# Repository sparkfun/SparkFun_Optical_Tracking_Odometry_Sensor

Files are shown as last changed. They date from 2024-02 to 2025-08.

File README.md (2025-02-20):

SparkFun Optical Tracking Odometry Sensor
========================================

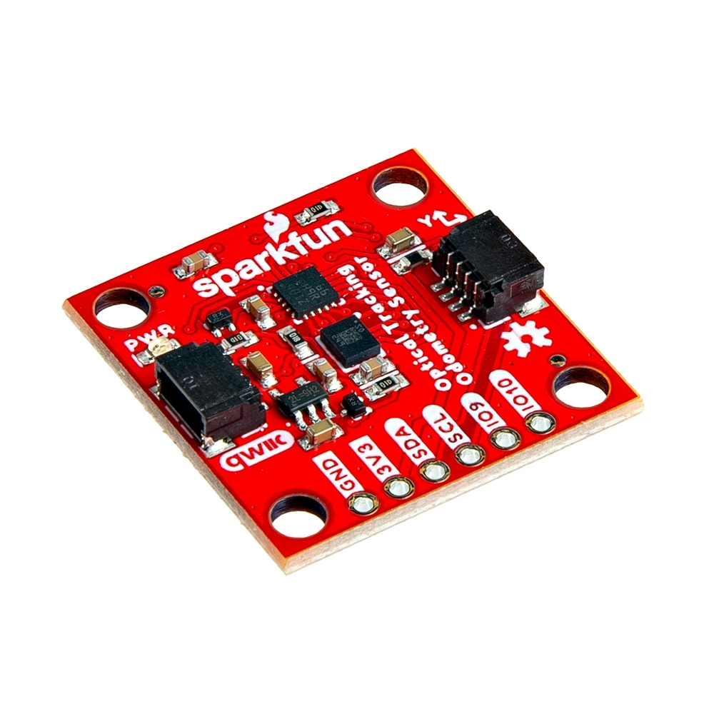
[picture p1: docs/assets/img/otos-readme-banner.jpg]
SparkFun Optical Tracking Odometry Sensor [SEN-24904]


[*SparkFun Optical Tracking Odometry Sensor [SEN-24904]*](https://www.sparkfun.com/products/24904)

The SparkFun Qwiic Optical Tracking Odometry Sensor empowers you to elevate your robot's navigation capabilities with exceptional precision and streamlined integration. This compact, all-in-one sensor leverages the power of the PAA5160E1 chip from PixArt Imaging Inc., delivering accurate dual-axis motion data across various hard floor surfaces. But that's not all! This sensor boasts a powerful built-in 6-axis Inertial Measurement Unit (IMU) and an onboard microcontroller that performs real-time sensor fusion and tracking algorithms.

Repository Contents
-------------------

* **/Hardware** - Eagle design files (.brd, .sch)
* **/Production** - Production panel files (.brd)

Documentation
--------------
* **[Arduino Library](https://github.com/sparkfun/SparkFun_Qwiic_OTOS_Arduino_Library)** - Arduino library for the SparkFun Optical Tracking Odometry Sensor.
* **[Hookup Guide](https://docs.sparkfun.com/SparkFun_Optical_Tracking_Odometry_Sensor/)** - Hookup guide for the SparkFun Optical Tracking Odometry Sensor.

License Information
-------------------

This product is _**open source**_! 

Please review the LICENSE.md file for license information. 

If you have any questions or concerns on licensing, please contact technical support on our [SparkFun forums](https://forum.sparkfun.com/viewforum.php?f=152).

Distributed as-is; no warranty is given.

- Your friends at SparkFun.

_<COLLABORATION CREDIT>_

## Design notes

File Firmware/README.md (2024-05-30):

# SparkFun OTOS (Optical Tracking Odometry Sensor) Firmware

This folder contains the firmware used on the [SparkFun Optical Tracking Odometry Sensor](https://www.sparkfun.com/products/24904). Instructions are provided below for anyone wanting to change the firmware on their OTOS.

## Firmware Update

The recommended update procedure is to use the [STM32CubeProgrammer](https://www.st.com/en/development-tools/stm32cubeprog.html) to flash the provided .hex firmware file using the UART interface. The SWD test points on the OTOS can also be used with a debugger, but instructions are not provided here.

### Required Materials

* A [SparkFun Optical Tracking Odometry Sensor](https://www.sparkfun.com/products/24904) to be updated
* A USB to serial adapter, such as the [SparkFun Serial Basic Breakout](https://www.sparkfun.com/products/15096)
* [Jumper wires](https://www.sparkfun.com/products/12795) to connect the serial adapter to the OTOS
* Download the [STM32CubeProgrammer](https://www.st.com/en/development-tools/stm32cubeprog.html) and install it onto your computer
* Download the latest .hex file [from the releases tab](https://github.com/sparkfun/SparkFun_Optical_Tracking_Odometry_Sensor/releases) or [from the main branch](https://github.com/sparkfun/SparkFun_Optical_Tracking_Odometry_Sensor/tree/main/Firmware/Release)

### Procedure

1. The STM32 on the OTOS needs to be running its bootloader to flash the new firmware.
    * To do this, the BOOT0 pin must be held high when the STM32 boots up (during power up or a reset). This is broken out to the centermost test point on the bottom of the OTOS. It is suggested to touch a jumper wire connected to 3.3V to this test point while powering up the board - the STM32 will remain in the bootloader until it resets, loses power, or new code is flashed onto it.
2. Connect the serial converter TX and RX pins to IO10 and IO9 respectively.
3. Open the STM32CubeProgrammer. In the top right, select the UART interface, leave the UART configuration at the default settings, and click the Connect button.
    * If it fails to connect, ensure the right COM port is selected and is not used by anything else on your computer, ensure the OTOS is fully powered, ensure the bootloader is running (see Step 1), and ensure the TX and RX pins are correct.
4. Once connected, select the "Erasing & programming" tab on the left. In the "Download" section, select the .hex file to be flashed in the File path, then click "Start Programming"
5. Once complete, the OTOS should start running the new firmware immediately, and will disconnect from the STM32CubeProgrammer.

## Building the Firmware

The firmware was developed using the [STM32CubeIDE](https://www.st.com/en/development-tools/stm32cubeide.html), which you will need to install in order to build the firmware. It generates code for the low-level hardware functionality, so be aware that code within the `Core` directory may be modified by the code generator if not placed in the correct locations.

To import the project, open the STM32CubeIDE -> File -> Import... -> General -> Existing Projects into Workspace -> Next -> set root directory to this folder called Firmware -> Ensure SparkFun_OTOS_Firmware is selected -> Finish. You should now see the SparkFun_OTOS_Firmware project in the Project Explorer on the left. Once open, you should also change the build configuration from Debug to Release: Project -> Build Configurations -> Set Active -> 2 Release.

To build the project, within the STM32CubeIDE, -> Project -> Build Project. The output .hex file will be placed in the `Release` directory (assuming you've changed the build configuration from Debug to Release).

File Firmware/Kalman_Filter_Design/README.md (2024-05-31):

# SparkFun OTOS Kalman Filter Design

This folder contains the simulation that was used to design the Kalman filter for the [SparkFun Optical Tracking Odometry Sensor](https://www.sparkfun.com/products/24904). This script can be run in either [MATLAB](https://www.mathworks.com/products/matlab.html) (not tested) or [GNU Octave](https://octave.org/) (free). This is mainly provided for transparency on how the Kalman filter was designed and tuned, although you're welcome to play around with it and try to improve it!

The Kalman filter is what performs the sensor fusion between the acceleration measurements from the IMU (LSM6DSO), and the velocity measurements from the optical tracking sensor (PAA5160). The LSM6DSO acceleration measurements were measured to have a standard deviation of about 0.03 m/s^2, and the PAA5160 velocity measurements were measured to have a standard deviation of about 3 in/s (0.076 m/s).

The process noise covariance matrix Q was manually tuned to give a good balance of fast response times and low noise. The simulation also includes a handful of tests to verify robustness, such as loss of optical tracking data and acceleration offsets.

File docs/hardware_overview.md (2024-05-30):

---
icon: material/cog
---

## Optical Tracking Sensor - PAA5160

The PAA5160E1-Q from PixArt Imaging has a tracking speed of 2.5m/s and a typical tracking error rate of 3~5% within a working range of 10mm to 27mm. With an 850nm Class 1 laser, a resolution of 20,000 DPI, and a frame rate of 20,000 fps, it is ideal for surfaces like concrete, epoxy, laminated wood, or glossy/semi-glossy flooring. That said, dark or diffuse surfaces are more challenging, so these specs may vary based on the surfaces that are being used. More information can be found in the [datasheet](assets/documentation/PAA5160_Datasheet_General.pdf){ target="_blank" }.

<figure markdown>
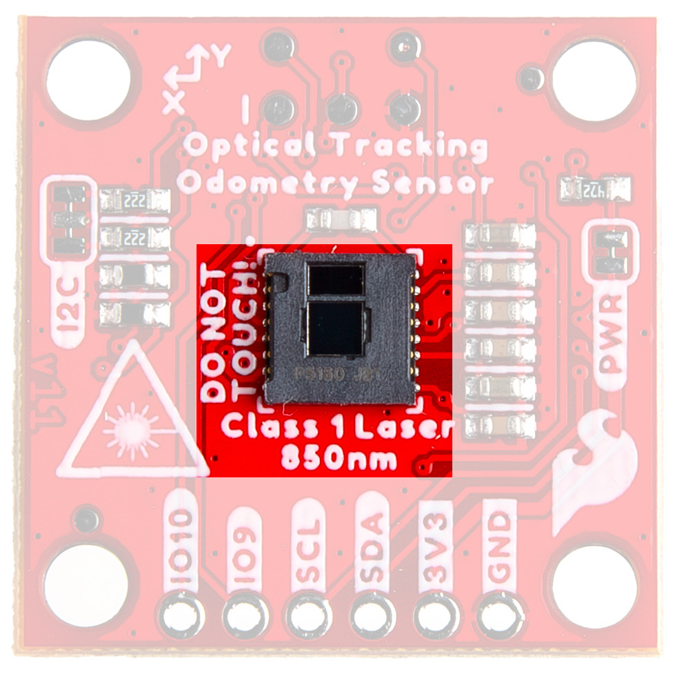
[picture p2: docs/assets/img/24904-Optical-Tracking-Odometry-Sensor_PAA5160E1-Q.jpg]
Optical Tracking Sensor - PAA5160

<figcaption markdown>Optical Tracking Sensor - PAA5160</figcaption>
</figure>

!!! warning
	The laser on this module is a Class 1, 850nm laser. Please use appropriate caution. 
	<figure markdown>
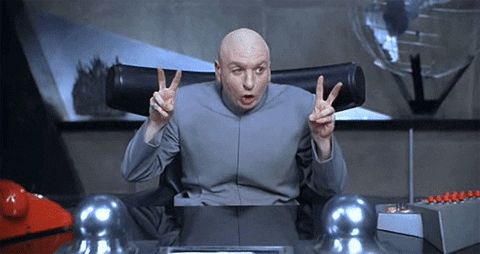
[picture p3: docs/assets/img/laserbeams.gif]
Dr. Evil using air quotes to say "freaking laser beams"
	
	<figcaption markdown>*Lasers...*</figcaption>
	</figure>

## 6-DoF IMU - LSM6DSO

The LSM6DSO from STMicroelectronics has a 3-axis digital accelerometer and 3-axis digital gyroscope featuring a full-scale acceleration range of ±2/±4/±8/±16 g and an angular rate range of ±125/±250/±500/±1000/±2000 dps. For more information, refer to the [datasheet](assets/documentation/lsm6dso.pdf){ target="_blank" }. 

<figure markdown>
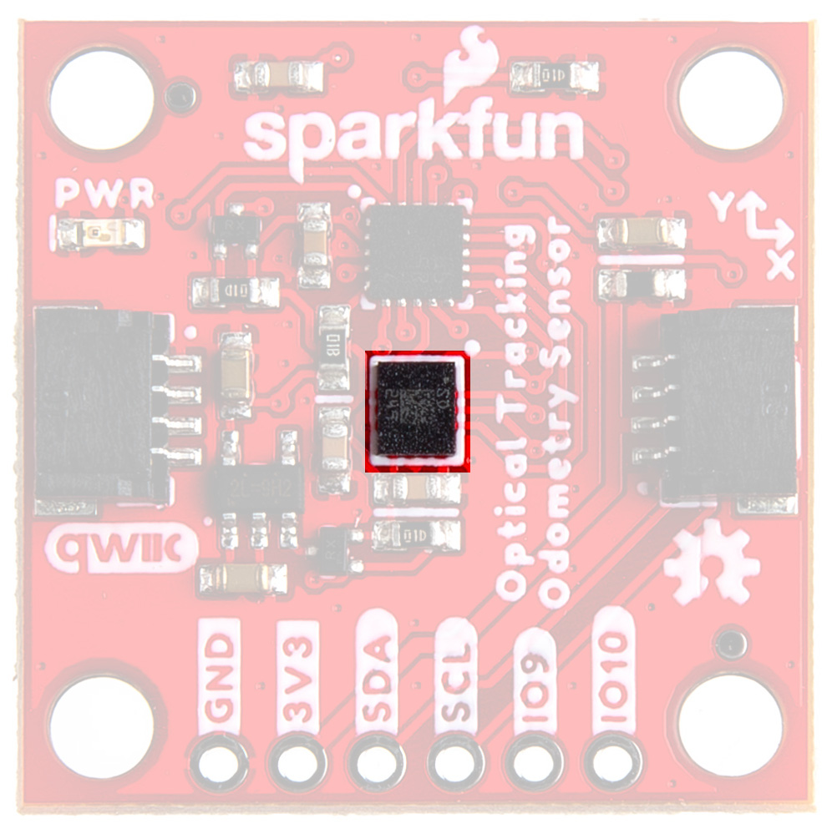
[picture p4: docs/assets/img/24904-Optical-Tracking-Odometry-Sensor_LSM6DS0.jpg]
LSM6DSO 6-DOF IMU Accelerometer

<figcaption markdown>LSM6DSO 6-DOF IMU Accelerometer</figcaption>
</figure>

## Microcontroller - STM32C0

The STM32C011F4U6 microcontroller has a high-performance Arm® Cortex®-M0+ 32-bit RISC core operating at up to 48 MHz frequency. It incorporates a memory protection unit (MPU), high-speed embedded memory (6 Kbytes of SRAM and up to 32 Kbytes of flash program memory with read and write protection), DMA, an extensive range of system functions, enhanced I/Os, and peripherals. The device offers standard communication interfaces (one I<sup>2</sup>C, one SPI / one I2S, and two USARTs), one 12-bit ADC (2.5 MSps) with up to 15 channels, a low-power RTC, an advanced control PWM timer, four general-purpose 16-bit timers, two watchdog timers, and a SysTick timer. For more information, refer to the [datasheet](assets/documentation/stm32c011d6-3082107.pdf){ target="_blank" }.

<figure markdown>
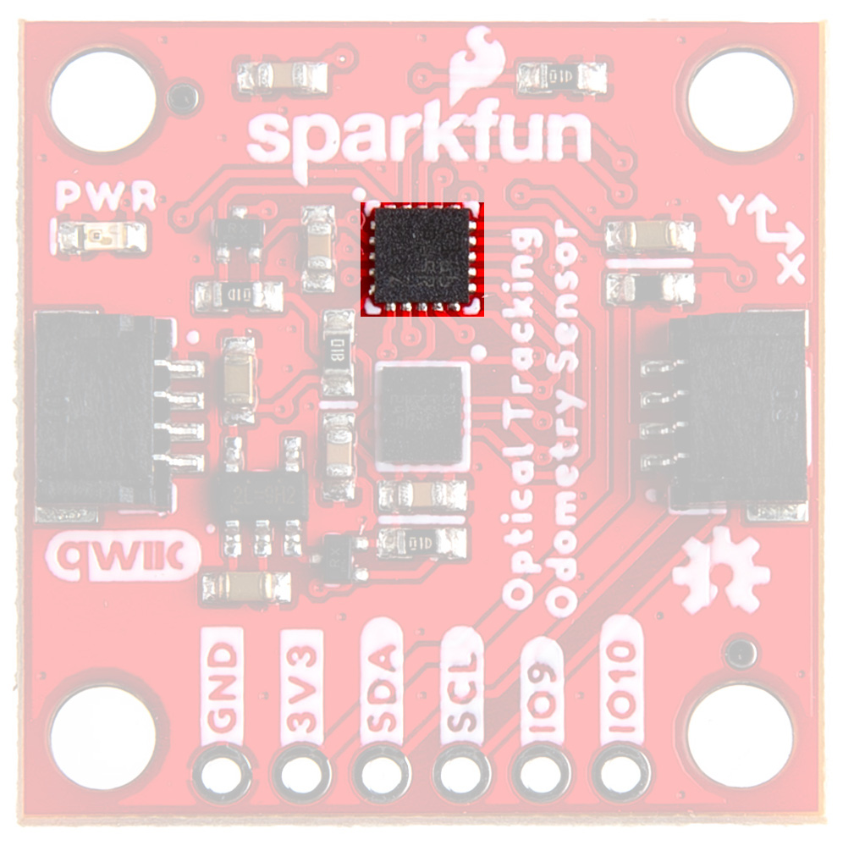
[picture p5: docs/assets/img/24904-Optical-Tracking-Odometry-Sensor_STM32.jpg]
STM32 Processor

<figcaption markdown>STM32 Processor</figcaption>
</figure>

## Power

The LED indicator lights when power is provided to the board. 

<figure markdown>
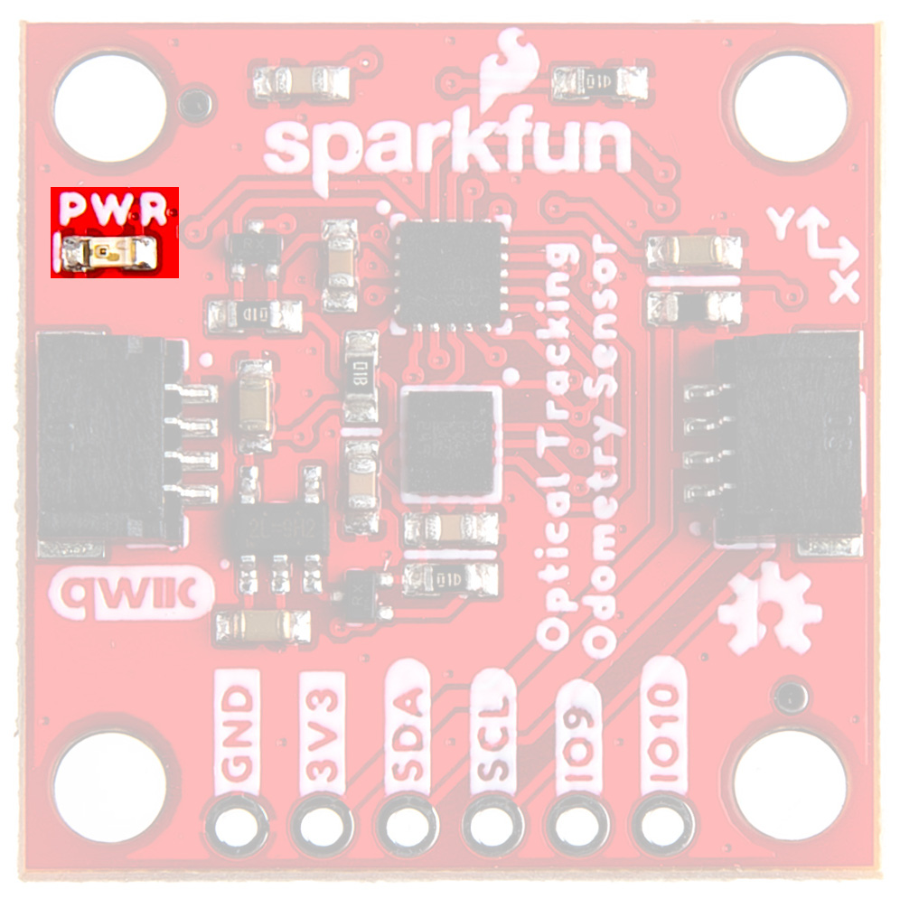
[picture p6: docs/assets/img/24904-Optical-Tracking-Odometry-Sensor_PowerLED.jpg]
Power LED

<figcaption markdown>Power LED</figcaption>
</figure>

## Qwiic Connectors

The Qwiic Connectors on the SparkFun Optical Tracking Odometry Sensor - PAA5160E1 (Qwiic) provide power and I<sup>2</sup>C connectivity simultaneously. The I<sup>2</sup>C address is 0x17.

<figure markdown>
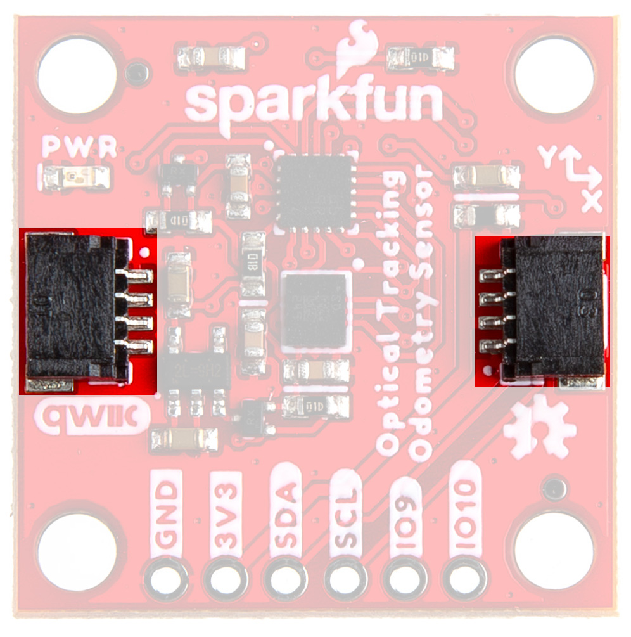
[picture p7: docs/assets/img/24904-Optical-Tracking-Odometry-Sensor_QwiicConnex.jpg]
Qwiic Connectors

<figcaption markdown>Qwiic Connectors</figcaption>
</figure>

## GPIO

The PTH pins on the side of the board allow you to provide power, access the I<sup>2</sup>C Data and Clock lines, and there are two pins available for UART/generic programming purposes. In normal operation, IO9 acts as a "data ready" interrupt; this pin could be used to synchronize measurements if needed. Outside of normal operation, IO9 and IO10 provide a UART interface that can be used for firmware updates, see instructions [here](https://github.com/sparkfun/SparkFun_Optical_Tracking_Odometry_Sensor/tree/main/Firmware). 

<figure markdown>
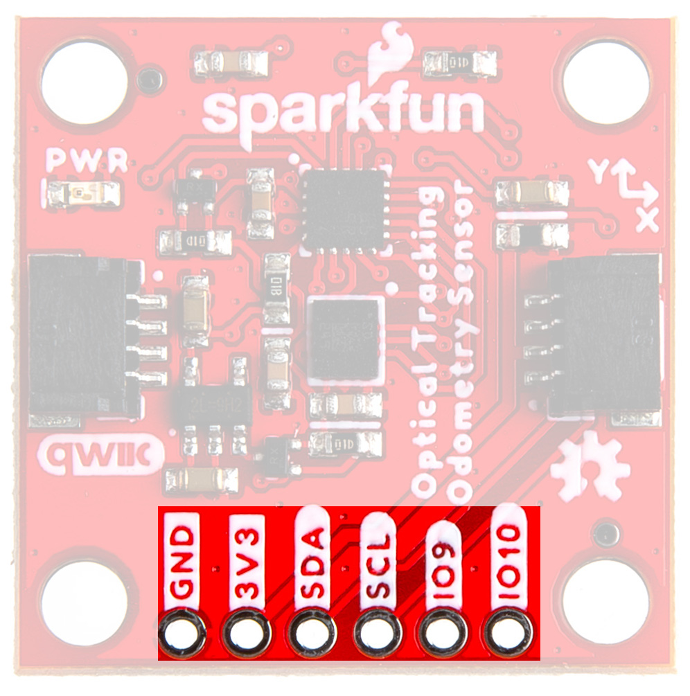
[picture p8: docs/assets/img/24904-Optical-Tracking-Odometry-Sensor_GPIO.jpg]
GPIO pins are highlighted

<figcaption markdown>GPIO</figcaption>
</figure>

## Debugging Test Points

We've broken out test points for serial wire debugging if you wish to access flash memory or directly program the board. They are located here: 

<figure markdown>
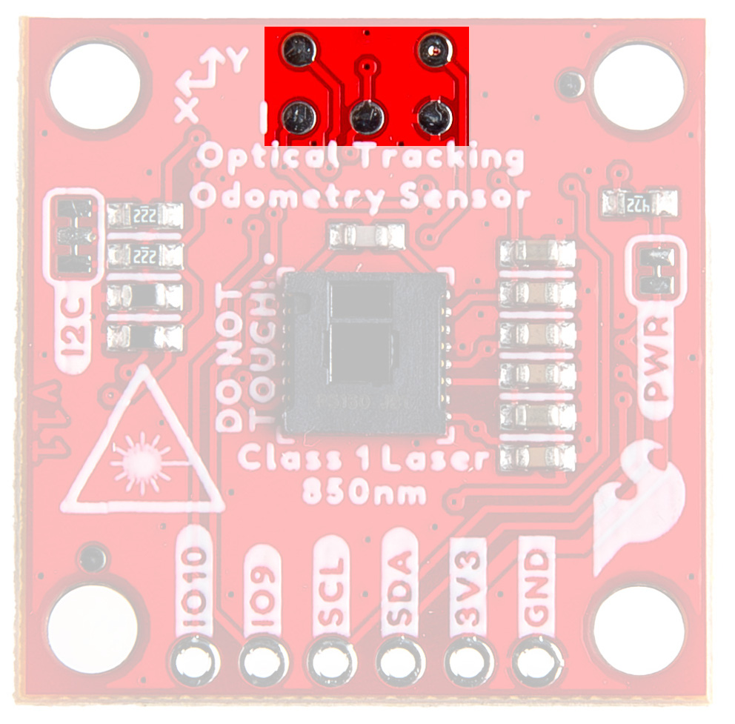
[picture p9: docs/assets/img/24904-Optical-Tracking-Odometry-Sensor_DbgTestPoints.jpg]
Debugging Test Points

<figcaption markdown>Debugging Test Points</figcaption>
</figure>

## Jumpers

??? note "Never modified a jumper before?"
	Check out our <a href="https://learn.sparkfun.com/tutorials/664">Jumper Pads and PCB Traces tutorial</a> for a quick introduction!
	<p align="center">
		<a href="https://learn.sparkfun.com/tutorials/664">
		Tutorial's thumbnail<br>
        How to Work with Jumper Pads and PCB Traces</a>
	</p>

### Power Jumper

If you are concerned about power consumption, need to run dark, or just really don't like LEDs, cut the jumper highlighted below to disconnect power from the LED on the front of the board. 

<figure markdown>
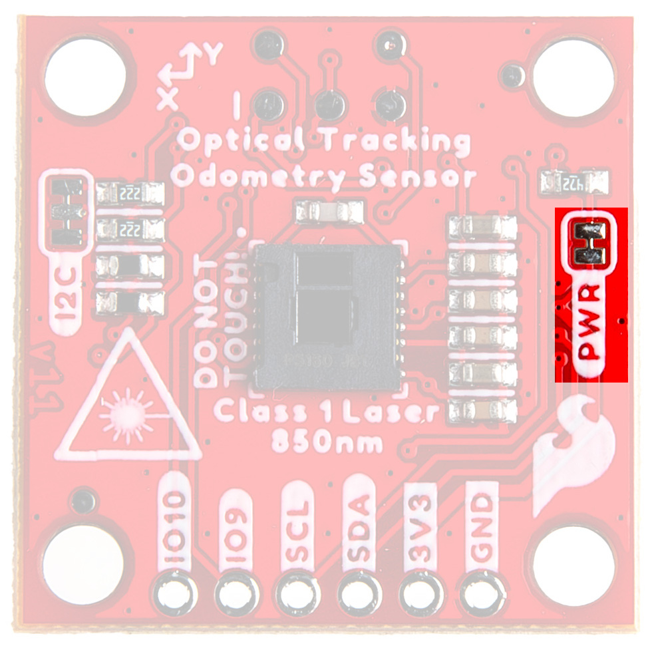
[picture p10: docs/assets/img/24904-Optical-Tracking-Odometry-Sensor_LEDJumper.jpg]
Power Jumper

<figcaption markdown>Power Jumper</figcaption>
</figure>

### I<sup>2</sup>C Jumper

If you choose to use one or more Qwiic breakouts in your project, it is important to note that this board comes equipped with pull-up resistors on the clock and data pins. If you are daisy-chaining multiple Qwiic devices, you will want to cut this jumper; if multiple sensors are connected to the bus with the pull-up resistors enabled, the parallel equivalent resistance will create too strong of a pull-up for the bus to operate correctly. As a general rule of thumb, disable all but one pair of pull-up resistors if multiple devices are connected to the bus. To disable the pull up resistors, use an X-acto knife to cut the joints between the jumper pads highlighted below.

<figure markdown>
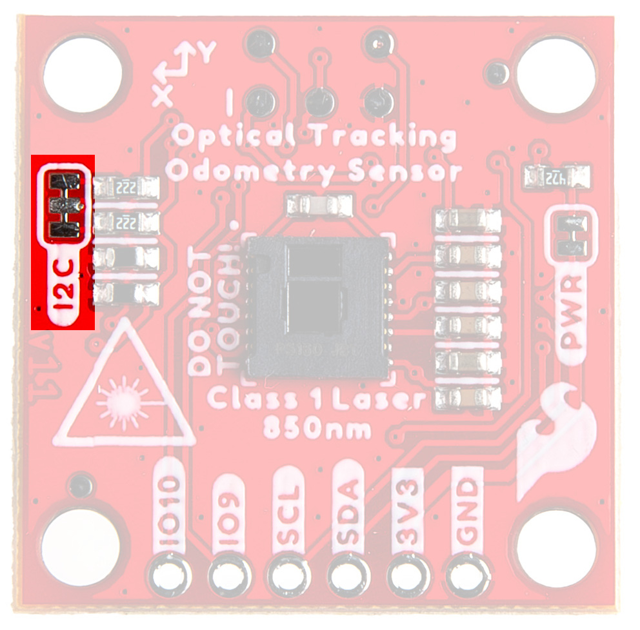
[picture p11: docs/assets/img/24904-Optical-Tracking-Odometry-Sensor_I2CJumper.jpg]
I2C Jumper

<figcaption markdown>I<sup>2</sup>C Jumper</figcaption>
</figure>

## Board Dimensions

The board dimensions are illustrated in the drawing below; the listed measurements are in inches.

<figure markdown>
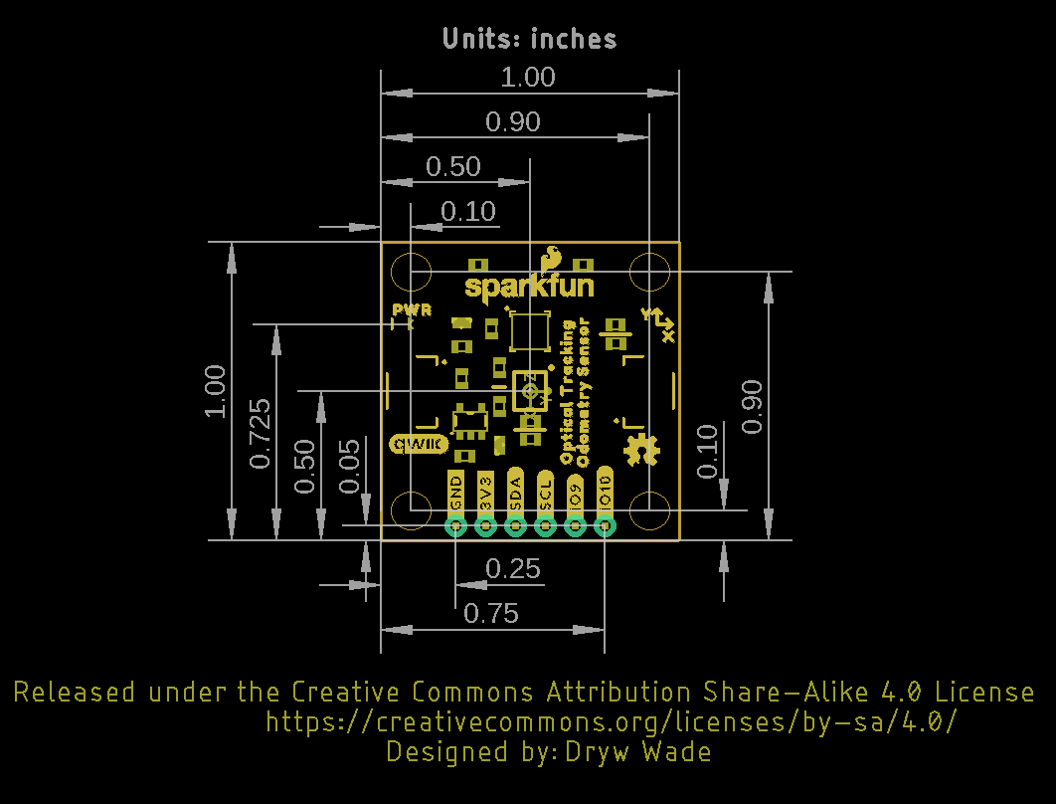
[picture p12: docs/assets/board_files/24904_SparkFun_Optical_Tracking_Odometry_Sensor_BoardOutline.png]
Board measures 1" by 1"

<figcaption markdown>SparkFun Optical Tracking Odometry Sensor Board Dimensions</figcaption>
</figure>

??? tip "Need more measurements?"
	For more information about the board's dimensions, users can download the [Eagle files](assets/board_files/24904_SparkFun_Optical_Tracking_Odometry_Sensor_EagleFiles.zip). These files can be opened in Eagle and additional measurements can be made with the dimensions tool.

	??? info ":octicons-download-16:{ .heart } Eagle - Free Download!"
		Eagle is a [CAD]("computer-aided design") program for electronics that is free to use for hobbyists and students. However, it does require an account registration to utilize the software.

		<center>
		[Download from<br>:autodesk-primary:{ .autodesk }](https://www.autodesk.com/products/eagle/free-download "Go to downloads page"){ .md-button .md-button--primary width="250px" }
		</center>
	
	??? info ":straight_ruler: Dimensions Tool"
		This video from Autodesk demonstrates how to utilize the dimensions tool in Eagle, to include additional measurements:

		<center>
		<div class="video">
		<iframe src="https://www.youtube.com/embed/dZLNd1FtNB8" title="EAGLE Dimension Tool" frameborder="0" allow="accelerometer; autoplay; clipboard-write; encrypted-media; gyroscope; picture-in-picture" allowfullscreen></iframe>
		</div>
		</center>

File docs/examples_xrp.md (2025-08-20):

---
icon: simple/python
---

!!! attention
	These instructions are written for the XRP using the [XRPCode IDE](https://xrpcode.wpi.edu/). However the setup process is very similar for MicroPython and CircuitPython on any other board, so you should be able to follow along with these instructions using your IDE of choice!

## Download Examples

First, go to the [Qwiic_OTOS_Py repository](https://github.com/sparkfun/Qwiic_OTOS_Py), open the `examples` folder, and download the example files you want to run.

Connect your XRP to your computer over USB, navigate to the [XRPCode editor](https://xrpcode.wpi.edu/), and connect to your XRP. For usage information, see the [XRPCode User Guide](https://xrpusersguide.readthedocs.io/en/latest/course/XRPCode.html).

Upload the example files into the root directory (`/`), or directory of your choice, on the XRP. Begin by finding the `Upload to XRP` option:

<figure markdown>
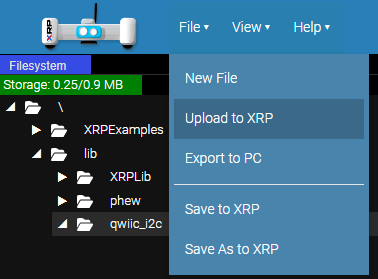
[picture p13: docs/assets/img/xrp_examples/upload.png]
File->Upload to XRP

<figcaption markdown>`Upload to XRP` option in the File Menu</figcaption>
</figure>

Select the files to upload: 

<figure markdown>
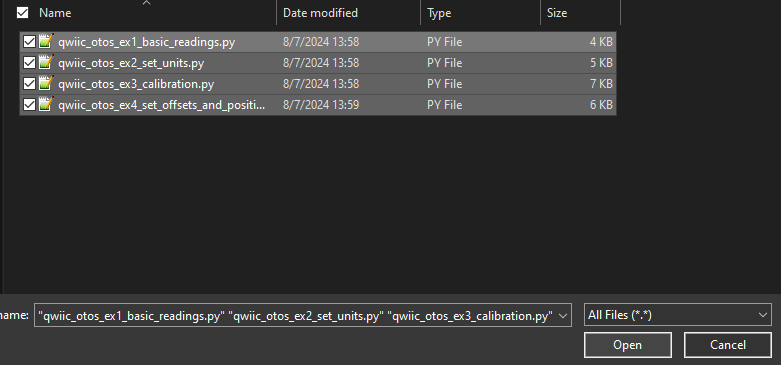
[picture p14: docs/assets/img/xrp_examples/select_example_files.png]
Select the files you wish to upload

<figcaption markdown>Selecting the Files to Upload</figcaption>
</figure>

Select the root directory (`/`), or directory of your choice, on the XRP:

<figure markdown>
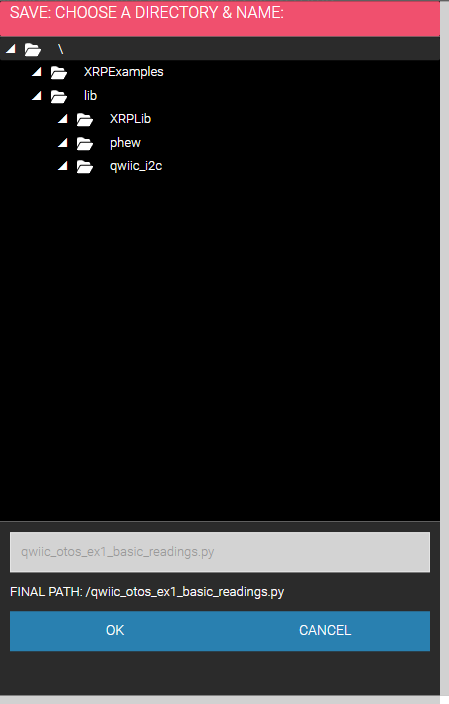
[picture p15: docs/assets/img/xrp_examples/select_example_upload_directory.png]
Select the root directory

<figcaption markdown>Select the root directory (`/`)</figcaption>
</figure>

Click the OK button and wait for the files to upload and save:

<figure markdown>
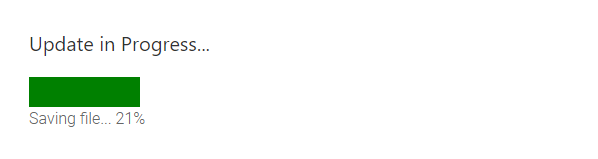
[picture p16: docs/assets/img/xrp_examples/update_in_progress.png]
Updating

<figcaption markdown>Updating</figcaption>
</figure>

You should then see the examples in the Filesystem panel on the left:

<figure markdown>
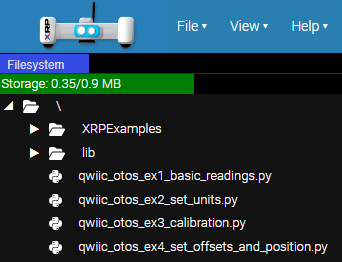
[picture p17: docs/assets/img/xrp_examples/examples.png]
Finding the examples in the FileSystem

<figcaption markdown>Finding the examples in the FileSystem</figcaption>
</figure>

## Example 1: Basic Readings

This first example just does some basic measurements to make sure everything is hooked up correctly. Assuming you uploaded this example in the procedure above, double-click `qwiic_otos_ex1_basic_readings.py` in the Filesystem panel on the left:

<figure markdown>
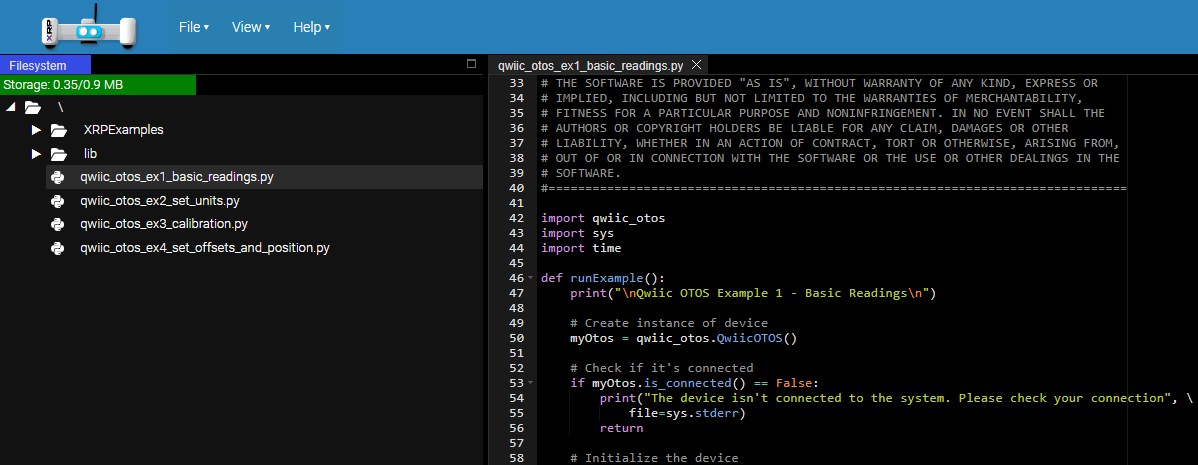
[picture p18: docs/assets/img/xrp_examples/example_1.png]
Example 1 location

<figcaption markdown>`qwiic_otos_ex1_basic_readings.py` XRP File Location</figcaption>
</figure>

Alternatively, you can expand the link below and copy and paste the code into a shiny new file:

??? "Example 1 Python Code"
	```
	--8<-- "https://raw.githubusercontent.com/sparkfun/Qwiic_OTOS_Py/master/examples/qwiic_otos_ex1_basic_readings.py"
	```

Then click the run button in the top right corner:

<figure markdown>
Giant Green RUN Button
<figcaption markdown>Run Button</figcaption>
</figure>

You should see the following output in the Shell:

<figure markdown>
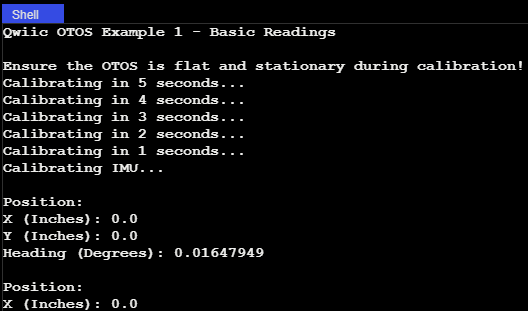
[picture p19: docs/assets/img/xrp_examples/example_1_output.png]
Example 1 Output

<figcaption markdown>Example 1 Output</figcaption>
</figure>

Move the sensor around to see how the coordinates change!

## Example 2: Set Units

This example sets the desired units for linear and angular measurements. Can be either meters or inches for linear, and radians or degrees for angular. If not set, the default is inches and degrees. Note that this setting is not stored in the sensor, it's part of the library, so you need to set at the start of all your programs. Assuming you uploaded this example in the procedure above, double-click `qwiic_otos_ex2_set_units.py` in the Filesystem panel on the left:

<figure markdown>
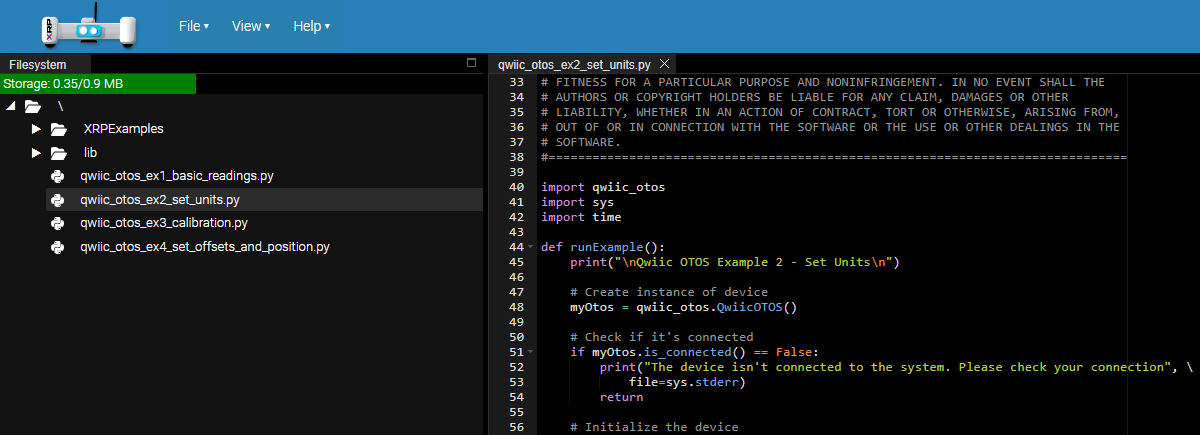
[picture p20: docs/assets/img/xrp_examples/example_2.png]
Example 2

<figcaption markdown>`qwiic_otos_ex2_set_units.py` XRP File Location</figcaption>
</figure>

Alternatively, you can expand the link below and copy and paste the code into a shiny new file and upload to the XRP as described above.

??? "Example 2 Python Code"
	```
	--8<-- "https://raw.githubusercontent.com/sparkfun/Qwiic_OTOS_Py/master/examples/qwiic_otos_ex2_set_units.py"
	```

Notice the following code snippet - this is the section of code that allows you to choose your units:

<figure markdown>
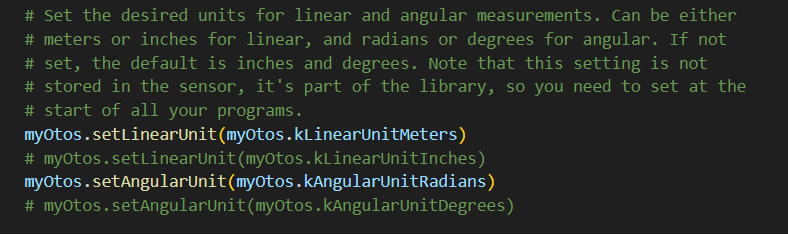
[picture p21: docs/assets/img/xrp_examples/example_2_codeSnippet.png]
Code Snippet to Change Units

<figcaption markdown>Code Snippet to Change Units</figcaption>
</figure>

Then click the run button in the top right corner:

<figure markdown>
Giant Green RUN Button
<figcaption markdown>Run Button</figcaption>
</figure>

You should see the following output in the Shell:

<figure markdown>
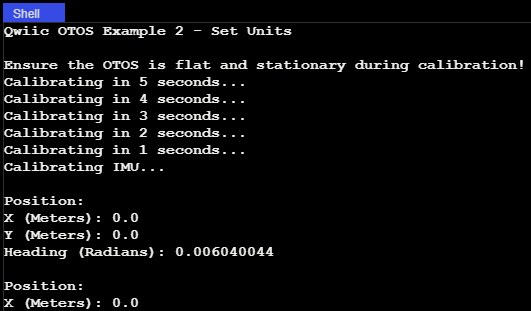
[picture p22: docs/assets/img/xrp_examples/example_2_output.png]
Example 2 Output

<figcaption markdown>Example 2 Output</figcaption>
</figure>

## Example 3: Calibration

!!! warning

	As of firmware version 1.0, these calibration values will be lost after a power cycle, so you will need to set them each time you power up the sensor.

The data from the OTOS will likely have minor scaling errors that can be calibrated out. This is especially important for the angular scalar, because an incorrect angle measurement causes the linear measurements to be rotated by the wrong angle in the firmware, which can lead to very inaccurate tracking. Assuming you uploaded this example in the procedure above, double-click `qwiic_otos_ex3_calibration.py` in the Filesystem panel on the left:

<figure markdown>
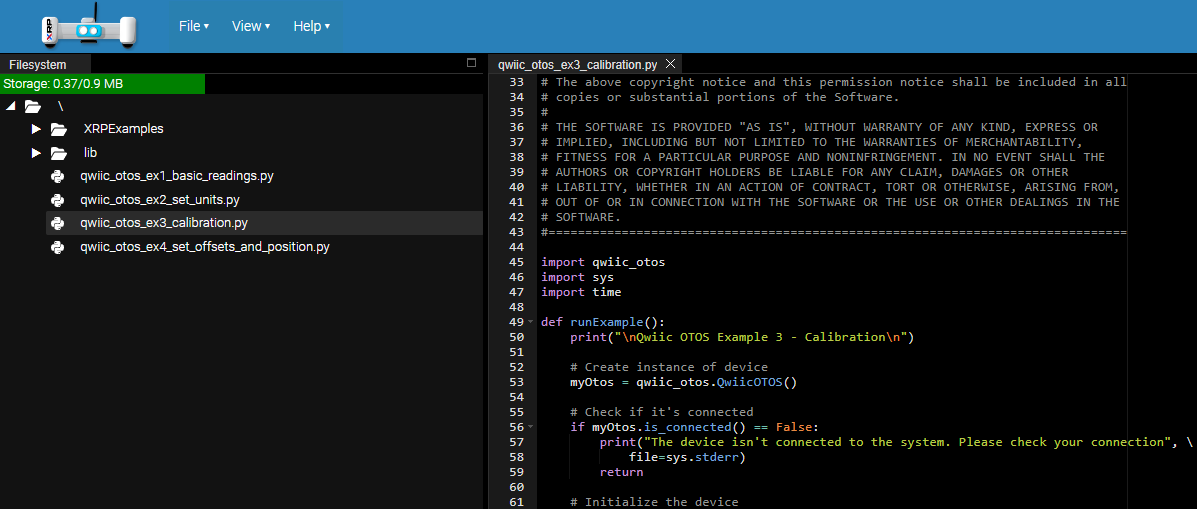
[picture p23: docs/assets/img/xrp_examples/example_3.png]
Example 3

<figcaption markdown>`qwiic_otos_ex3_calibration.py` XRP File Location</figcaption>
</figure>

Alternatively, you can expand the link below and copy and paste the code into a shiny new file and upload to the XRP as described above.

??? "Example 3 Python Code"
	```
	--8<-- "https://raw.githubusercontent.com/sparkfun/Qwiic_OTOS_Py/master/examples/qwiic_otos_ex3_calibration.py"
	```

Then click the run button in the top right corner:

<figure markdown>
Giant Green RUN Button
<figcaption markdown>Run Button</figcaption>
</figure>

Calibrating your bot requires you to move it around a bit. First, set both scalars to 1.0, then calibrate the angular scalar, then the linear scalar. 

To calibrate the angular scalar, spin the robot by multiple rotations (eg. 10) to get a precise error, then set the scalar to the inverse of the error. Remember that the angle wraps from -180 to 180 degrees, so for example, if after 10 rotations counterclockwise(positive rotation), the sensor reports -15 degrees, the required scalar would be 3600/3585 = 1.004. 

<figure markdown>
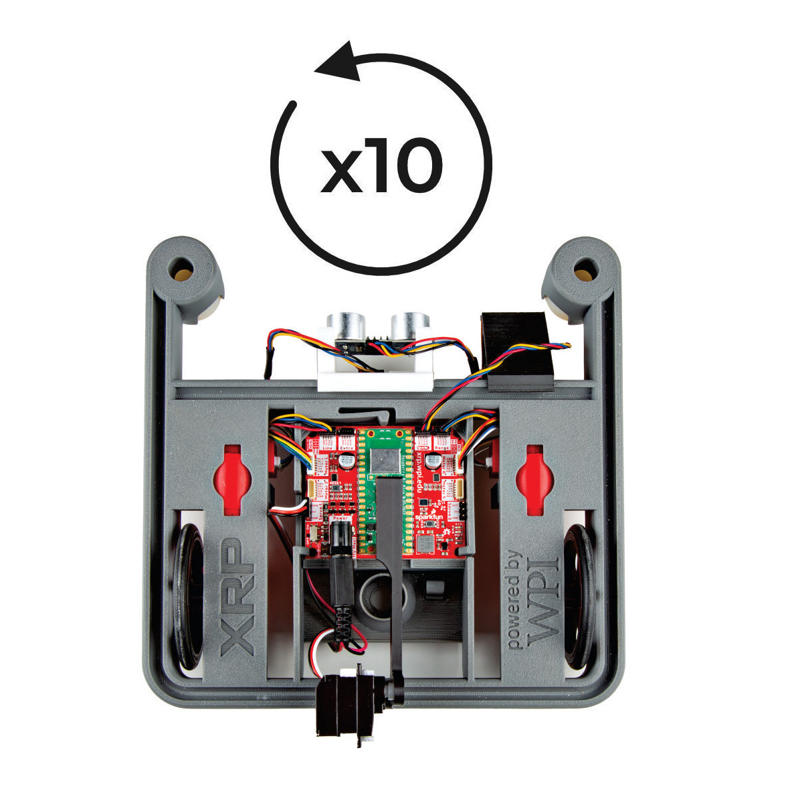
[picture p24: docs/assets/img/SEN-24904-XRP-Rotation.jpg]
Rotating the Optical Tracking Odometry Sensor

<figcaption markdown>Rotating the Optical Tracking Odometry Sensor</figcaption>
</figure>

To calibrate the linear scalar, move the robot a known distance and measure the error; do this multiple times at multiple speeds to get an average, then set the linear scalar to the inverse of the error. For example, if you move the robot 100 inches and the sensor reports 103 inches, set the linear scalar to 100/103 = 0.971. 

<figure markdown>
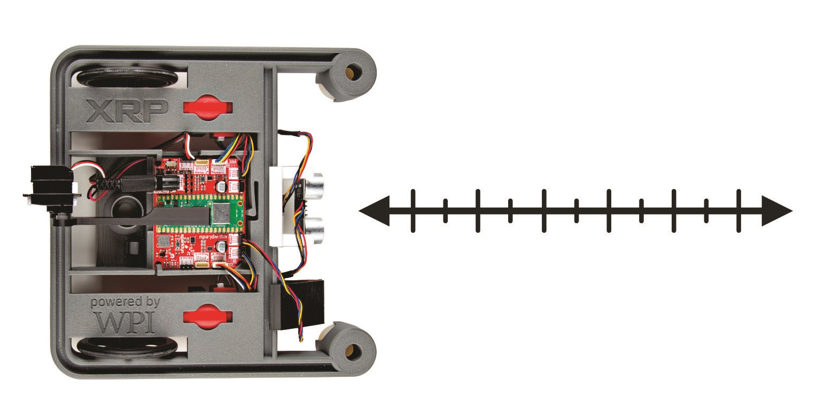
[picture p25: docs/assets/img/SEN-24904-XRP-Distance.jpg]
Moving the Optical Tracking Odometry Sensor

<figcaption markdown>Moving the Optical Tracking Odometry Sensor</figcaption>
</figure>

## Example 4: SetOffsetAndPosition 

This example shows how to set the offset for the sensor relative to the center of the robot. The units default to inches and degrees, but if you want to use different units, make sure you specify them before setting the offset. Without setting the offset, the OTOS will report the coordinates of itself. If the offset is set, the OTOS will instead report the coordinates of the center of your robot.

Note that the OTOS typically starts tracking from the origin, but if your robot starts at some other location, or you have another source of location information from another sensor that's more accurate, you can send the current location to the OTOS and it will continue tracking from there.

!!! warning 

    As of firmware version 1.0, these values will be lost after a power cycle, so you will need to set them each time you power up the sensor. 

Assuming you uploaded this example in the procedure above, double-click `qwiic_otos_ex4_set_offsets_and_position.py` in the Filesystem panel on the left:

<figure markdown>
Example 4
<figcaption markdown>`qwiic_otos_ex4_set_offsets_and_position.py` XRP File Location</figcaption>
</figure>

Alternatively, you can expand the link below and copy and paste the code into a shiny new file and upload to the XRP as described above.

??? "Example 4 Python Code"
	```
	--8<-- "https://raw.githubusercontent.com/sparkfun/Qwiic_OTOS_Py/master/examples/qwiic_otos_ex4_set_offsets_and_position.py"
	```

Then click the run button in the top right corner:

<figure markdown>
Giant Green Run Button
<figcaption markdown>Run Button</figcaption>
</figure>	

The offset values depend on the [axes conventions](https://en.wikipedia.org/wiki/Axes_conventions) that you choose for your robot. Below are 2 animations showing ENU (East-North-Up) and NWU (North-West-Up) axes conventions with the XRP, and the required offset values for the indicated location of the OTOS for each. In this case, the sensor is mounted 2 inches to the right ("East"), 4 inches forward ("North"), and with the x-axis to the right ("East").

<figure markdown>
OTOS offsets with ENU axes conventions
<figcaption markdown>OTOS offsets with ENU axes conventions</figcaption>
</figure>

<figure markdown>
OTOS offsets with NWU axes conventions
<figcaption markdown>OTOS offsets with NWU axes conventions</figcaption>
</figure>

With the ENU convention, the OTOS axes are aligned with the robot axes, so the offset angle is zero. With the NWU convention, the OTOS axes are rotated -90 degrees (right-hand rule about the "up" z-axis) relative to the robot axes. So the offset values would be `{2, 4, 0}` for ENU and `{4, -2, -90}` for NWU. These can be any value, even the angle can be tweaked slightly to compensate for imperfect mounting (eg. 1.3 degrees).

These four examples cover the basics - there are more examples to explore in the GitHub Repo!

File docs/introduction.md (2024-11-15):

---
icon: material/book-open-page-variant
---

<div class="grid cards desc" markdown>

-    <a href="https://www.sparkfun.com/products/24904">
    **SparkFun Optical Tracking Odometry Sensor - PAA5160E1 (Qwiic)**<br>
    **SKU:** SEN-24904

    ---

    <figure markdown>
    Product Thumbnail
    </figure></a>

-    The SparkFun Qwiic Optical Tracking Odometry Sensor empowers you to elevate your robot's navigation capabilities with exceptional precision and streamlined integration. This compact, all-in-one sensor leverages the power of the PAA5160E1 chip from PixArt Imaging Inc., delivering accurate dual-axis motion data across various hard floor surfaces. But that's not all! This sensor boasts a powerful built-in 6-axis Inertial Measurement Unit (IMU) and an onboard microcontroller that performs real-time sensor fusion and tracking algorithms.

    <center>
    [Purchase from SparkFun :fontawesome-solid-cart-plus:{ .heart }](https://www.sparkfun.com/products/24904){ .md-button .md-button--primary }
    </center>

</div>

<div style="text-align: center">
  <table>
    <tr>
      <td style="text-align: center; vertical-align: middle;">
        <iframe width="560" height="315" src="https://www.youtube.com/embed/WcCNC8wExUc?si=TiFzZ-B61BXpmXQT" title="YouTube video player" frameborder="0" allow="accelerometer; autoplay; clipboard-write; encrypted-media; gyroscope; picture-in-picture; web-share" referrerpolicy="strict-origin-when-cross-origin" allowfullscreen></iframe>
      </td>
    </tr>
  </table>
</div>

## Required Materials

To follow along with this tutorial, you will need the following materials. You may not need everything though depending on what you have. Add it to your cart, read through the guide, and adjust the cart as necessary.

<table style="border-style:none">
    <tr>
        <td>
            <a href="https://www.sparkfun.com/products/24904">
                <center>SparkFun Optical Tracking Odometry Sensor - PAA5160E1 (Qwiic)</center>
                <h3 class="title">SparkFun Optical Tracking Odometry Sensor - PAA5160E1 (Qwiic)</h3>
            </a>
            SEN-24904
        </td>
        <td>
            <a href="https://www.sparkfun.com/products/25596">
                <center>Flexible Qwiic to STEMMA Cable - 500mm</center>
                <h3 class="title">Flexible Qwiic to STEMMA Cable - 500mm</h3>
            </a>
            CAB-25596
        </td>
        <td>
            <a href="https://www.sparkfun.com/products/14427">
                <center>Qwiic Cable - 100mm
                </center>
                <h3 class="title">Qwiic Cable - 100mmc</h3>
            </a>
           PRT-14427
        </td>        <td>
            <a href="https://www.sparkfun.com/products/10215">
                <center>USB micro-B Cable - 6 Foot
                </center>
                <h3 class="title">USB micro-B Cable - 6 Foot</h3>
            </a>
            CAB-10215
        </td>
    </tr>
    <tr>
        <td>
            <a href="https://www.sparkfun.com/products/22230">
                <center>Experiential Robotics Platform (XRP) Kit - Beta
                </center>
                <h3 class="title">Experiential Robotics Platform (XRP) Kit - Beta</h3>
            </a>
            KIT-22230
        </td>
        <td>
            <a href="https://www.sparkfun.com/products/15123">
                <center>SparkFun RedBoard Qwiic
                </center>
                <h3 class="title">SparkFun RedBoard Qwiic</h3>
            </a>
            DEV-15123
        </td>
    </tr>
</table>

## Suggested Reading

Below are a few tutorials that may help users familiarize themselves with various aspects of the board.

<div class="grid cards hide col-4" markdown align="center">

-   <a href="https://learn.sparkfun.com/tutorials/82">
    <figure markdown>
    I2C
    </figure>
    </a>
    <a href="https://learn.sparkfun.com/tutorials/82">**I2C**
    </a>

-   <a href="https://learn.sparkfun.com/tutorials/terminal-basics">
    <figure markdown>
    SPI
    </figure>
    </a>
    <a href="https://learn.sparkfun.com/tutorials/terminal-basics">**Serial Terminal Basics**
    </a>
</div>

<center>
<div align="center">
    <div style="top:5px;left:5px;background-color:Gray;position:relative">
        <div style="top:-5px;left:-5px;background-color:#ffffff;position:relative;border:1px solid black;">
            <a href="https://www.sparkfun.com/qwiic">Qwiic Connect System</a>
        </div>
    </div>
</div>
</center>

The SparkFun Optical Tracking Odometry Sensor - PAA5160E1 (Qwiic) takes advantage of the [Qwiic connect system](https://www.sparkfun.com/qwiic). We recommend familiarizing yourself with the **Logic Levels** and **I<sup>2</sup>C** tutorials.  Click on the banner above to learn more about [Qwiic products](https://www.sparkfun.com/qwiic).

<center>
    <iframe width="600" height="327" src="https://www.youtube.com/embed/x0RDEHqFIF8" title="SparkFun's Qwiic Connect System" frameborder="0" allow="accelerometer; autoplay; clipboard-write; encrypted-media; gyroscope; picture-in-picture" allowfullscreen></iframe>
</center>

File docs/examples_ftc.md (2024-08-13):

---
icon: first
---

!!! attention
	Please ensure you have done the Software Setup before attempting to run the example! You need to have at least version v9.2 of the SDK running on the Control Hub, and add the sensor to your Hardware Config.

Unlike our Arduino and Python libraries that include several examples, there is only a single but comprehensive example for FTC. This sample OpMode is available in Blocks, OnBot Java, and Android Studio; setup instructions are avaiable for each, but running the sample is the same.

# Blocks

Create a new OpMode based on the sample called `SensorSparkFunOTOS`.

TODO

# OnBot Java

Create a new OpMode based on the sample called `SensorSparkFunOTOS`.

TODO

# Android Studio

Navigate to the sample OpModes under FtcRobotController -> java -> `org.firstinspires.ftc.robotcontroller.external.samples` -> `SensorSparkFunOTOS`. Make a copy of this file in the TeamCode folder along with the rest of your code.

!!! attention
	It is strongly recommended that you do not modify the sample OpModes within the FtcRobotController sample folder! Always make a copy so you have clean examples to work with!

After making a copy, comment out or delete the `@Disabled` to enable the OpMode. Then upload the code to the robot.

<figure markdown>

<figcaption markdown></figcaption>
</figure>

# Run the Example

On the Driver Station, select the TeleOp dropdown menu, and you should see the `Sensor: SparkFun OTOS` sample OpMode; select it.

When you press the `INIT` button, the sensor will initialize, the IMU will be calibrated, and the tracking algorithm will be reset. The telemetry on the driver station will display the version numbers read from the device.

When you press the `Start` button, the telemetry will display the (x,y) coordinates and heading angle of the robot, as measure by the sensor. If you have gamepad #1 connected, you can press Y (triangle) to reset the tracking, or press X (square) to re-calibrate the IMU.

<figure markdown>

<figcaption markdown></figcaption>
</figure>

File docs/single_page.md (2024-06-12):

---
hide:
  - navigation
  - toc
icon: fontawesome/solid/scroll
---

--8<-- "./docs/introduction.md:5"

# Hardware Overview
--8<-- "./docs/hardware_overview.md:5"

# Hardware Assembly
--8<-- "./docs/hardware_assembly.md:5"

# Hardware Assembly - FTC
--8<-- "./docs/hardware_assembly_FTC.md:5"

# Software Setup - Arduino
--8<-- "./docs/software_setup-Arduino.md:5"

# Software Setup - Python
--8<-- "./docs/software_setup-Python.md:5"

# Software Setup - FIRST Tech Challenge Java
--8<-- "./docs/software_setup-FTC.md:5"

# Troubleshooting Tips
--8<-- "./docs/troubleshooting.md:5"

# Resources:
--8<-- "./docs/resources.md"

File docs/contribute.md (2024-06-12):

# Contribute: Make an Augmentation!
Spot an improvement opportunity? Feel free to contribute to our open-source design and documentation. 

## :material-file-document-multiple:&nbsp;Improve our Documentation
All of this documentation can be modified by you! Please help us make it better.

* These pages are contained in the [`docs` folder](https://github.com/sparkfun/SparkFun_Optical_Tracking_Odometry_Sensor/tree/main/docs) of the [SparkFun Optical Tracking Odometry Sensor - PAA5160E1 (Qwiic) repository](https://github.com/sparkfun/SparkFun_Optical_Tracking_Odometry_Sensor).

### Submit a Correction

1. With a GitHub account, [fork this repository](https://github.com/sparkfun/SparkFun_Optical_Tracking_Odometry_Sensor/fork).
2. Add your corrections or improvements to the markdown file.
3. File a pull request with your changes, and enjoy making the ~~words~~ ~~worlds~~ world a better place.
	* Once received, the documentation specialist will automatically be notified.
	* We will review your suggested improvements to make sure they are correct and fit within our documentation standards.

## :material-cog:&nbsp;Improve our Hardware Design
All of our designs are open-source! Please help us make it better.

* Our board design files are contained in the [`Hardware` folder](https://github.com/sparkfun/SparkFun_Optical_Tracking_Odometry_Sensor/tree/main/Hardware) of the [SparkFun Optical Tracking Odometry Sensor - PAA5160E1 (Qwiic) repository](https://github.com/sparkfun/SparkFun_Optical_Tracking_Odometry_Sensor).

1. With a GitHub account, [fork this repository](https://github.com/sparkfun/SparkFun_Optical_Tracking_Odometry_Sensor/fork).
2. Add your design augmentation(s)
3. File a pull request with your changes, and enjoy making the ~~words~~ ~~worlds~~ world a better place.
	1. Once received, the engineer in charge of the original design will automatically be notified.
	2. We will review your suggested improvement(s) to verify that they are within our board design standards and meet our product design requirements.
	3. If approved, we will flag these changes for our next board revision. Congrats! 🍻

		!!! info
			Even if your suggestion is accepted, these changes may not be immediately available for purchase. We may have to cycle through our current product inventory first.

## Contributors&nbsp;:clap:
Let's provide some recognition to the contributors for this project!

GitHub Contributors Image
<br>


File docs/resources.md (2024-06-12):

<!-- This section should include all the relevant documentation and product files (Eagle files, schematic, datasheet(s), landing pages, etc. and any relevant tutorials to go beyond the Hookup Guide.) -->

For more resources related to the SparkFun SparkFun Optical Tracking Odometry Sensor, check out the links listed here: 

* [Product Page](https://www.sparkfun.com/products/24904){ target="_blank" }
* [Schematic (PDF)](./assets/board_files/24904_SparkFun_Optical_Tracking_Odometry_Sensor_Schematic.pdf){ target="_blank" }
* [Eagle Files (ZIP)](./assets/board_files/24904_SparkFun_Optical_Tracking_Odometry_Sensor_EagleFiles.zip){ target="_blank" }
* [Board Dimensions(PNG)](./assets/board_files/24904_SparkFun_Optical_Tracking_Odometry_Sensor_BoardOutline.png){ target="_blank" }
* [Hardware GitHub Repository](https://github.com/sparkfun/SparkFun_Optical_Tracking_Odometry_Sensor){ target="_blank" }
* [Optical Tracking Odometry Sensor Register Map (PDF)](https://github.com/sparkfun/SparkFun_Optical_Tracking_Odometry_Sensor/blob/main/Firmware/OTOS_Register_Map.pdf)

Libraries/Packages: 

* [Arduino Library GitHub Repository](https://github.com/sparkfun/SparkFun_Qwiic_OTOS_Arduino_Library){ target="_blank" }
* [SparkFun Optical Tracking Odometry Sensor Python Package GitHub](https://github.com/sparkfun/Qwiic_OTOS_Py/archive/refs/heads/master.zip){ target="_blank" }
* [SparkFun Optical Tracking Odometry Sensor Java Library GitHub](https://github.com/sparkfun/SparkFun_Qwiic_OTOS_FTC_Java_Library/archive/refs/heads/main.zip){ target="_blank" }

Visualization Python Script: 

* [XRP Visualization Script](assets\SparkFun_OTOS_XRP_Visualization.zip){ target="_blank" }

XRP Resources:

* [XRP 3D Printed Mount on Printables](https://www.printables.com/model/872179-odometry-clip-for-xrp){ target="_blank" }
* [XRP Info Page](https://www.sparkfun.com/xrp){ target="_blank" }

First Tech Challenge Resources: 

* [FTC mounts on Onshape](https://cad.onshape.com/documents/1253798610182bf3a147f431/w/11cc45e6a7c8080b22bb8377/e/d4827c4f09d804607ba1824b){ target="_blank" }	
* [Instructions for FTC mounts]( https://docs.google.com/document/d/14oHPdummdtDlF2BijsM5kqbD6MTwzaQFkbJ2jo99SUI/edit){ target="_blank" }

Datasheets: 

* [Optical Tracking Sensor - PAA5160 Datasheet](assets/documentation/PAA5160_Datasheet_General.pdf){ target="_blank" }
* [6-DoF IMU - LSM6DSO Datasheet](assets/documentation/lsm6dso.pdf){ target="_blank" }
* [Microcontroller - STM32C0 Datasheet](assets/documentation/stm32c011d6-3082107.pdf)

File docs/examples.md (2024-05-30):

---
icon: simple/arduino
---

!!! attention

	All of the examples require the user to enter a key into the serial monitor before the example starts, which triggers the IMU calibration. 

!!! attention

	The IMU on the Optical Tracking Odometry Sensor includes a gyroscope and accelerometer, which could have an offset. The OTOS performs a quick calibration when it powers up, but it is recommended to perform a more thorough calibration at the start of all your programs. 

###Example 1: Basic Readings

This first example just does some basic measurements to make sure everything is hooked up correctly. To find Example 1, go to **File** > **Examples** > **SparkFun Qwiic OTOS** > **Example1_BasicReadings**:

<figure markdown>
Optical Tracking Odometry Sensor Arduino Example 1
<figcaption markdown>Finding Example 1</figcaption>
</figure>

Alternatively, you can expand the link below and copy and paste the code into a shiny new Arduino sketch: 

??? "Example 1 Arduino Code"
	```
	--8<-- "https://raw.githubusercontent.com/sparkfun/SparkFun_Qwiic_OTOS_Arduino_Library/main/examples/Example1_BasicReadings/Example1_BasicReadings.ino"
	```

Make sure you've selected the correct board and port in the Tools menu and then hit the upload button. Once the code has finished uploading, go ahead and open a [Serial Monitor](https://learn.sparkfun.com/tutorials/terminal-basics). You should see something similar to the following.  

<figure markdown>
Optical Tracking Odometry Sensor Arduino Example 1 Output
<figcaption markdown>Example 1 Output</figcaption>
</figure>

Move the sensor around to see how the coordinates change!

###Example 2: SetUnits

This example sets the desired units for linear and angular measurements. Can be either meters or inches for linear, and radians or degrees for angular. If not set, the default is inches and degrees. Note that this setting is not stored in the sensor, it's part of the library, so you need to set at the start of all your programs.

To find Example 2, go to **File** > **Examples** > **SparkFun Qwiic OTOS** > **Example2_SetUnits**:

<figure markdown>
Optical Tracking Odometry Sensor Arduino Example 2
<figcaption markdown>Finding Example 2</figcaption>
</figure>

Alternatively, you can expand the link below and copy and paste the code into a shiny new Arduino sketch: 

??? "Example 2 Arduino Code"
	```
	--8<-- "https://raw.githubusercontent.com/sparkfun/SparkFun_Qwiic_OTOS_Arduino_Library/main/examples/Example2_SetUnits/Example2_SetUnits.ino"
	```

Notice the following code snippet - this is the section of code that allows you to choose your units: 

<figure markdown>
Optical Tracking Odometry Sensor Arduino Example 2 Code Snippet
<figcaption markdown>Example 2 Code To Change Units </figcaption>
</figure>

Make sure you've selected the correct board and port in the Tools menu and then hit the upload button. Once the code has finished uploading, go ahead and open a [Serial Monitor](https://learn.sparkfun.com/tutorials/terminal-basics). You should see something similar to the following.  

<figure markdown>
Optical Tracking Odometry Sensor Arduino Example 2
<figcaption markdown>Example 2 Output</figcaption>
</figure>

###Example 3: Calibration

!!! warning

	As of firmware version 1.0, these calibration values will be lost after a power cycle, so you will need to set them each time you power up the sensor.

The data from the OTOS will likely have minor scaling errors that can be calibrated out. This is especially important for the angular scalar, because an incorrect angle measurement causes the linear measurements to be rotated by the wrong angle in the firmware, which can lead to very inaccurate tracking.

To find Example 3, go to **File** > **Examples** > **SparkFun Qwiic OTOS** > **Example3_Calibration**:

<figure markdown>
Optical Tracking Odometry Sensor Arduino Example 3
<figcaption markdown>Finding Example 3</figcaption>
</figure>

Alternatively, you can expand the link below and copy and paste the code into a shiny new Arduino sketch: 

??? "Example 3 Arduino Code"
	```
	--8<-- "https://raw.githubusercontent.com/sparkfun/SparkFun_Qwiic_OTOS_Arduino_Library/main/examples/Example3_Calibration/Example3_Calibration.ino"
	```

Make sure you've selected the correct board and port in the Tools menu and then hit the upload button. Once the code has finished uploading, go ahead and open a [Serial Monitor](https://learn.sparkfun.com/tutorials/terminal-basics).

Calibrating your bot requires you to move it around a bit. First, set both scalars to 1.0, then calibrate the angular scalar, then the linear scalar. 

To calibrate the angular scalar, spin the robot by multiple rotations (eg. 10) to get a precise error, then set the scalar to the inverse of the error. Remember that the angle wraps from -180 to 180 degrees, so for example, if after 10 rotations counterclockwise(positive rotation), the sensor reports -15 degrees, the required scalar would be 3600/3585 = 1.004. 

<figure markdown>
Rotating the Optical Tracking Odometry Sensor
<figcaption markdown>Rotating the Optical Tracking Odometry Sensor</figcaption>
</figure>

To calibrate the linear scalar, move the robot a known distance and measure the error; do this multiple times at multiple speeds to get an average, then set the linear scalar to the inverse of the error. For example, if you move the robot 100 inches and the sensor reports 103 inches, set the linear scalar to 100/103 = 0.971. 

<figure markdown>
Moving the Optical Tracking Odometry Sensor
<figcaption markdown>Moving the Optical Tracking Odometry Sensor</figcaption>
</figure>

###Example 4: SetOffsetAndPosition 

This example shows how to set the offset for the sensor relative to the center of the robot. The units default to inches and degrees, but if you want to use different units, make sure you specify them before setting the offset. Without setting the offset, the OTOS will report the coordinates of itself. If the offset is set, the OTOS will instead report the coordinates of the center of your robot.

Note that the OTOS typically starts tracking from the origin, but if your robot starts at some other location, or you have another source of location information from another sensor that's more accurate, you can send the current location to the OTOS and it will continue tracking from there.

!!! warning 

    As of firmware version 1.0, these values will be lost after a power cycle, so you will need to set them each time you power up the sensor. 

To find Example 4, go to **File** > **Examples** > **SparkFun Qwiic OTOS** > **Example4_SetOffsetAndPosition**:

<figure markdown>
Optical Tracking Odometry Sensor Arduino Example 4
<figcaption markdown>Finding Example 4</figcaption>
</figure>

Alternatively, you can expand the link below and copy and paste the code into a shiny new Arduino sketch: 

??? "Example 4 Arduino Code"
	```
	--8<-- "https://raw.githubusercontent.com/sparkfun/SparkFun_Qwiic_OTOS_Arduino_Library/main/examples/Example4_SetOffsetAndPosition/Example4_SetOffsetAndPosition.ino"
	```

If the sensor is mounted 5 inches to the left (negative X) and 10 inches forward (positive Y) of the center of the robot, and mounted 90 degrees clockwise (negative rotation) from the robot's orientation, the offset would be {-5, 10, -90}. These can be any value, even the angle can be tweaked slightly to compensate for imperfect mounting (eg. 1.3 degrees).

<figure markdown>
The X, Y, and Angular Offset of the Optical Tracking Sensor
<figcaption markdown>The X, Y, and Angular Offset of the Optical Tracking Sensor</figcaption>
</figure>

These four examples cover the basics - there are more examples to explore in the library! 

<!--
###Example 5: VelocityAndAcceleration

This example prints out the velocity and acceleration of the bot as it moves. 

To find Example 5, go to **File** > **Examples** > **SparkFun Qwiic OTOS** > **Example5_VelocityAndAcceleration**:

<figure markdown>
[![Optical Tracking Odometry Sensor Arduino Example 5](assets/img/Arduino_Example_5_Menu.jpg){ width="600" }](assets/img/Arduino_Example_5_Menu.jpg "Click to enlarge")
<figcaption markdown>Finding Example 5</figcaption>
</figure>

Alternatively, you can expand the link below and copy and paste the code into a shiny new Arduino sketch: 

??? "Example 5 Arduino Code"
	```
	--8<-- ""
	```

https://raw.githubusercontent.com/sparkfun/SparkFun_Qwiic_OTOS_Arduino_Library/v1.0.0/examples/Example5_VelocityAndAcceleration/Example5_VelocityAndAcceleration.ino

###Example 6: StandardDeviation

This example reads the standard deviation of the tracking. Note that these values are just the square root of the diagonal elements of the covariance matrices of the Kalman filters used in the firmware of the OTOS and not actual tracking error data. 

!!! warning 

    THESE VALUES DO NOT REPRESENT THE ACTUAL TRACKING ERROR! These are statistical quantities that assume a correct model of the system, but there could be unmodelled error sources that cause the physical error to become larger than these statistical error (eg. improper calibration, or rotating the OTOS to not be flat against the tracking surface). These are provided primarily for anyone wanting to perform sensor fusion with additional sensors, but they can be used to at least "get an idea" of the quality of the accuracy.

To find Example 6, go to **File** > **Examples** > **SparkFun Qwiic OTOS** > **Example6_StandardDeviation**:

<figure markdown>
[![Optical Tracking Odometry Sensor Arduino Example 6](assets/img/Arduino_Example_6_Menu.jpg){ width="600" }](assets/img/Arduino_Example_6_Menu.jpg "Click to enlarge")
<figcaption markdown>Finding Example 6</figcaption>
</figure>

Alternatively, you can expand the link below and copy and paste the code into a shiny new Arduino sketch: 

??? "Example 6 Arduino Code"
	```
	--8<-- ""
	```

https://raw.githubusercontent.com/sparkfun/SparkFun_Qwiic_OTOS_Arduino_Library/v1.0.0/examples/Example6_StandardDeviation/Example6_StandardDeviation.ino

###Example 7: GetVersion

This should be fairly self explanatory. This example gets the current hardware and firmware version of the board. 

To find Example 7, go to **File** > **Examples** > **SparkFun Qwiic OTOS** > **Example7_GetVersion**:

<figure markdown>
[![Optical Tracking Odometry Sensor Arduino Example 7](assets/img/Arduino_Example_7_Menu.jpg){ width="600" }](assets/img/Arduino_Example_7_Menu.jpg "Click to enlarge")
<figcaption markdown>Finding Example 7</figcaption>
</figure>

Alternatively, you can expand the link below and copy and paste the code into a shiny new Arduino sketch: 

??? "Example 7 Arduino Code"
	```
	--8<-- ""
	```
https://raw.githubusercontent.com/sparkfun/SparkFun_Qwiic_OTOS_Arduino_Library/v1.0.0/examples/Example7_GetVersion/Example7_GetVersion.ino

Make sure you've selected the correct board and port in the Tools menu and then hit the upload button. Once the code has finished uploading, go ahead and open a [Serial Monitor](https://learn.sparkfun.com/tutorials/terminal-basics). You should see something similar to the following: 

<figure markdown>
[![Optical Tracking Odometry Sensor Arduino Example 7 Output](assets/img/Arduino_Example_7_Output.jpg){ width="600" }](assets/img/Arduino_Example_7_Output.jpg "Click to enlarge")
<figcaption markdown>Example 7 Output</figcaption>
</figure>

###Example 8: SelfTest 

Again, this should be self explanatory. This example tests the basics to make sure everything is working as expected. 

To find Example 8, go to **File** > **Examples** > **SparkFun Qwiic OTOS** > **Example8_SelfTest**:

<figure markdown>
[![Optical Tracking Odometry Sensor Arduino Example 8](assets/img/Arduino_Example_8_Menu.jpg){ width="600" }](assets/img/Arduino_Example_8_Menu.jpg "Click to enlarge")
<figcaption markdown>Finding Example 8</figcaption>
</figure>

Alternatively, you can expand the link below and copy and paste the code into a shiny new Arduino sketch: 

??? "Example 8 Arduino Code"
	```
	--8<-- ""
	```
<!--
https://raw.githubusercontent.com/sparkfun/SparkFun_Qwiic_OTOS_Arduino_Library/v1.0.0/examples/Example8_SelfTest/Example8_SelfTest.ino
-->

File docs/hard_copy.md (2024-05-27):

---
icon: material/book-open-variant
---

Need to download or print our hookup guide?

* [Print :fontawesome-solid-print:](single_page.md) (Single-Page View)
    * To save as a `*.pdf` file, select the **Printer** or **Destination** labeled ++"Save as PDF"++. *(Instructions will vary based on the browser)*
<!-- * [Download :fontawesome-regular-file-pdf:](../board_files/hookup_guide.pdf) *(Beta - demonstration only)* -->

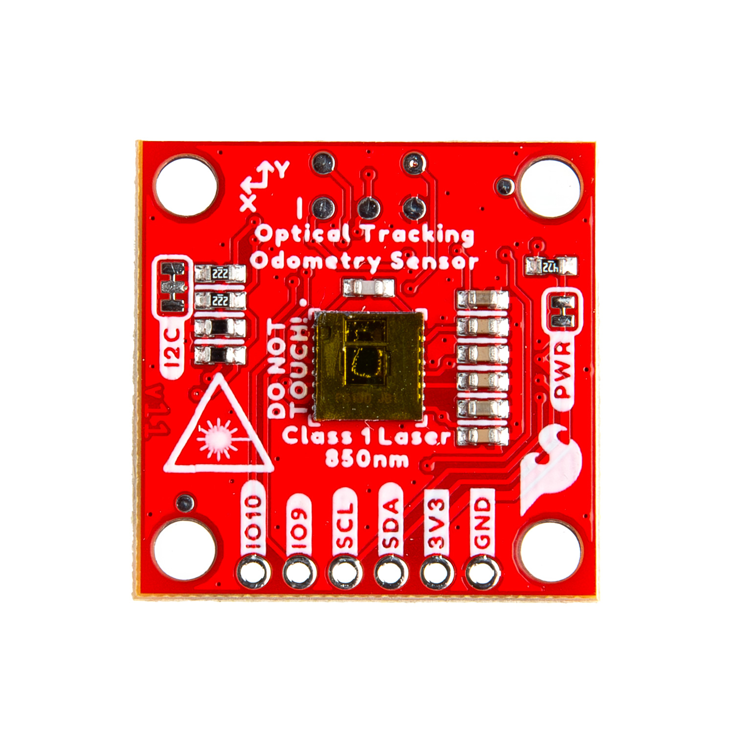
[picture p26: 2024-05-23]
docs/assets/img/SEN-24904-Optical-Tracking-Odometry-Sensor-Back-Sticker.jpg

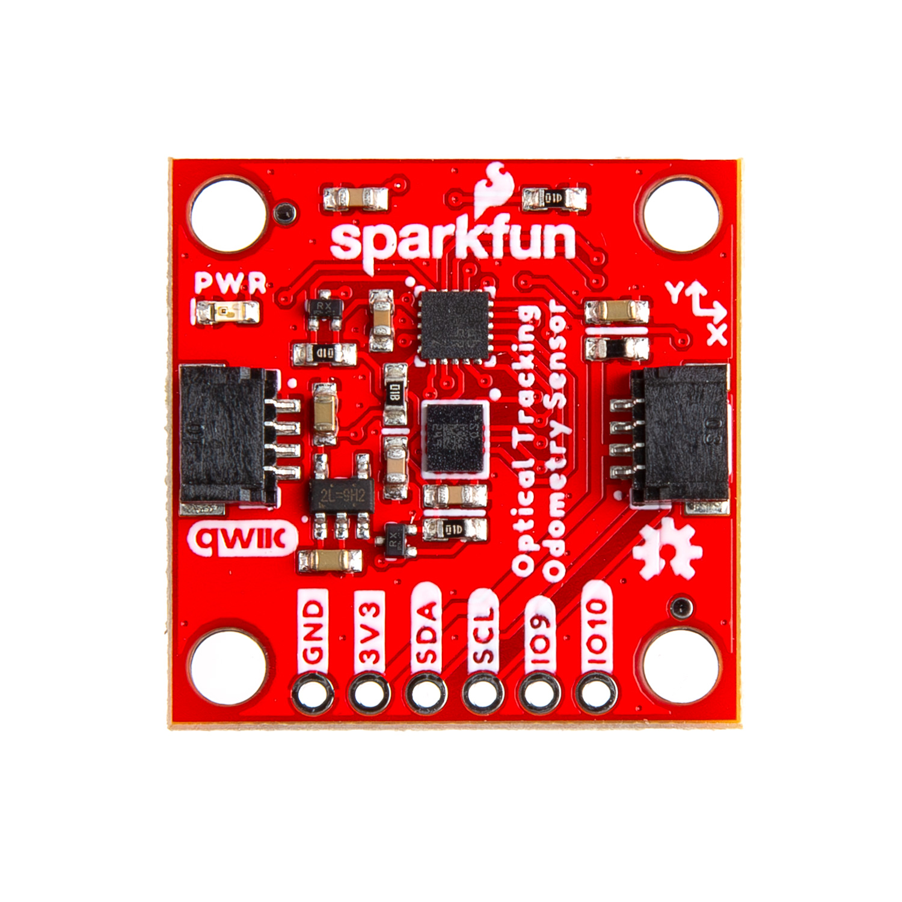
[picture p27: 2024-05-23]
docs/assets/img/SEN-24904-Optical-Tracking-Odometry-Sensor-Front.jpg

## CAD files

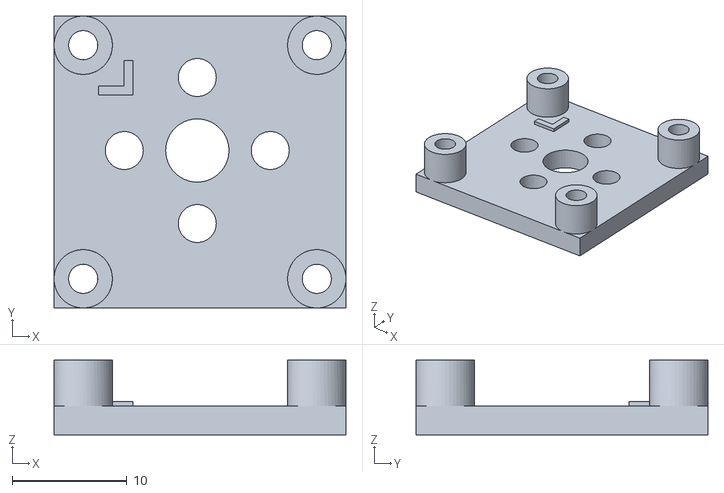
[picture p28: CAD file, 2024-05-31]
Firmware/Lookup_Table_Calibration/3D_Printables/stepper_otos_mount.stl
25.4 x 25.4 x 6.50

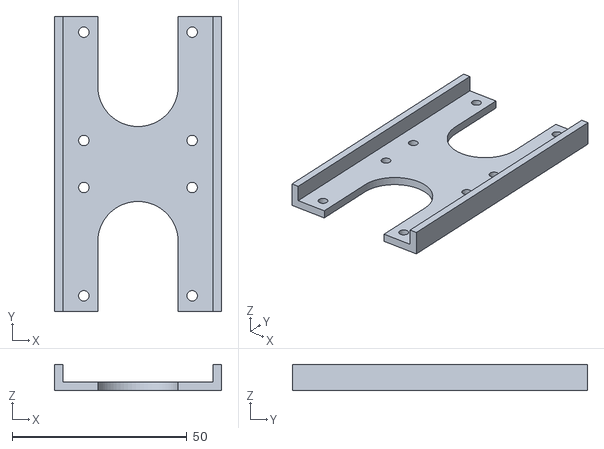
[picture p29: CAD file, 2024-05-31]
Firmware/Lookup_Table_Calibration/3D_Printables/stepper_motor_bracket.stl
47.8 x 84.4 x 7.50

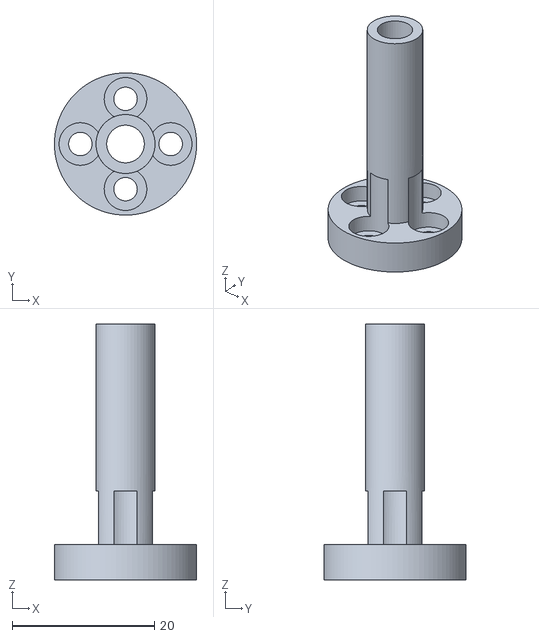
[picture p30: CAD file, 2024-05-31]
Firmware/Lookup_Table_Calibration/3D_Printables/stepper_disc_mount.stl
20.0 x 20.0 x 36.0

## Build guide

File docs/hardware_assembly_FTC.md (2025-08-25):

---
icon: first
---

<!--
[![FIRST Tech Logo](assets/img/FIRSTTech_IconVert_RGB.jpg){ align="center" width="200"}](assets/img/FIRSTTech_IconVert_RGB.jpg "Click to enlarge")
-->

The SparkFun Optical Tracking Odometry Sensor needs to be rigidly mounted to a robot chassis and oriented flat to the floor in order to get accurate data. If you don't already have a mount, there are a few 3D printing models you can use. That said, you may need to design your own mount for this board, depending on your use case. 

 Note here that we are using the foam surface typical of FIRST Tech Challenge competitions and the sensor is mounted at 10mm from the surface.
 
!!! warning

	Accurate readings require that the sensor is mounted correctly; attempting to move the sensor by hand may work, but tracking accuracy will suffer.

The FTC mounts are available on [Onshape](https://cad.onshape.com/documents/1253798610182bf3a147f431/w/11cc45e6a7c8080b22bb8377/e/d4827c4f09d804607ba1824b) with instructions for them [here](https://docs.google.com/document/d/14oHPdummdtDlF2BijsM5kqbD6MTwzaQFkbJ2jo99SUI/edit).

The image below shows the 3D mounted clip with the Optical Tracking Sensor attached to an FTC Bot: 

<figure markdown>
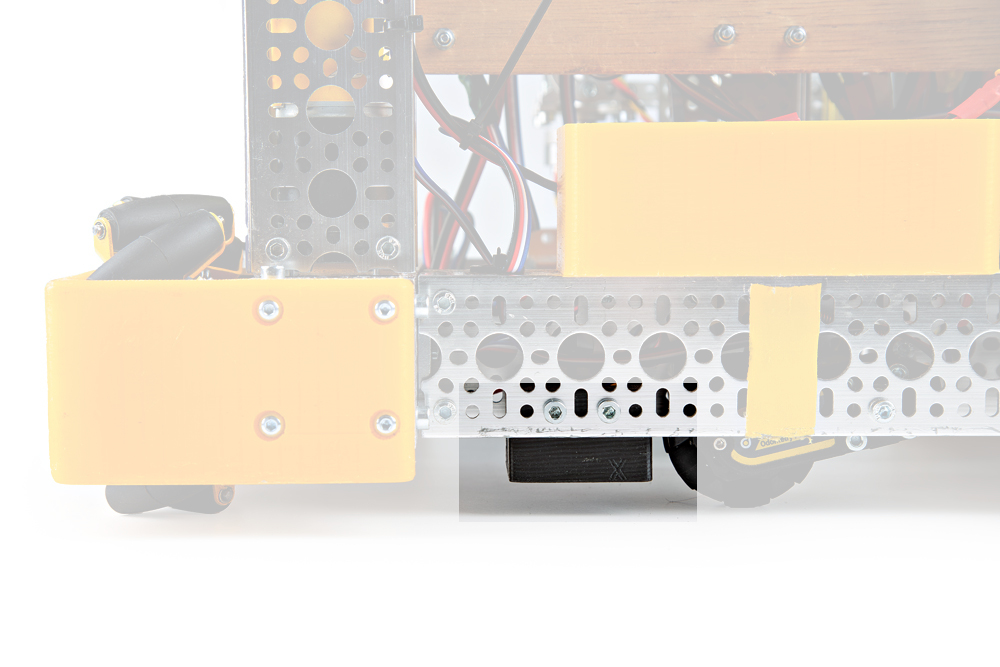
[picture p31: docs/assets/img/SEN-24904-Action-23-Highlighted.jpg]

<figcaption markdown>Optical Tracking Sensor Mounted to the FTC Bot</figcaption>
</figure>

!!! first-tech "FIRST Tech Challenge"

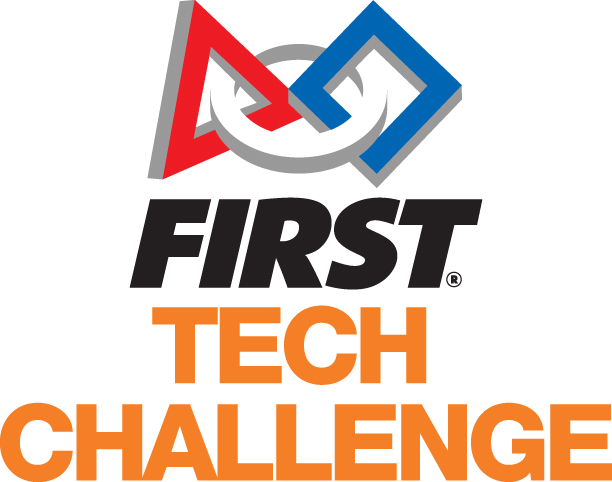
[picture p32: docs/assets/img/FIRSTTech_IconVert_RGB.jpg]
FIRST Tech Logo
	

	FIRST Tech Challenge: Note here that for the foam competition files, the sensor really needs to be mounted at exactly 10mm from the surface with a tolerance of +/ 1mm. Beyond that, the tracking is less accurate; beyond +/- 3mm, and it can't track the foam surface at all.

Here is the underside of the FTC Bot with the Optical Tracking Sensor attached via the mounting clip: 

<figure markdown>
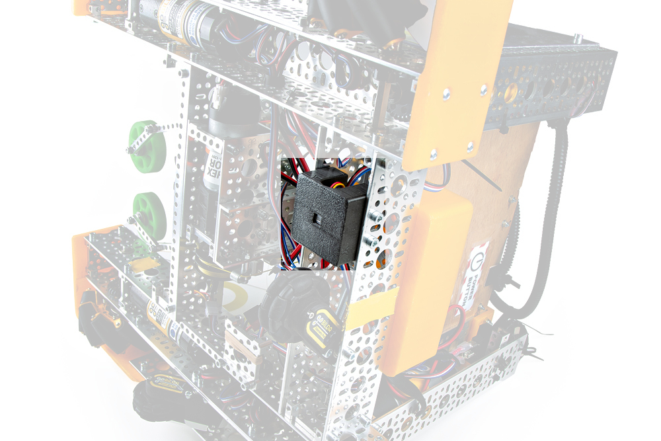
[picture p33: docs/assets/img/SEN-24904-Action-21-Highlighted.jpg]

<figcaption markdown>Optical Tracking Sensor Mounted to the FTC Bot</figcaption>
</figure>

Using the [Flexible Qwiic to STEMMA Cable - 500mm](https://www.sparkfun.com/products/25596), you'll need to attach the sensor via one of the I<sup>2</sup>C connectors on the Control Hub like so:

<figure markdown>
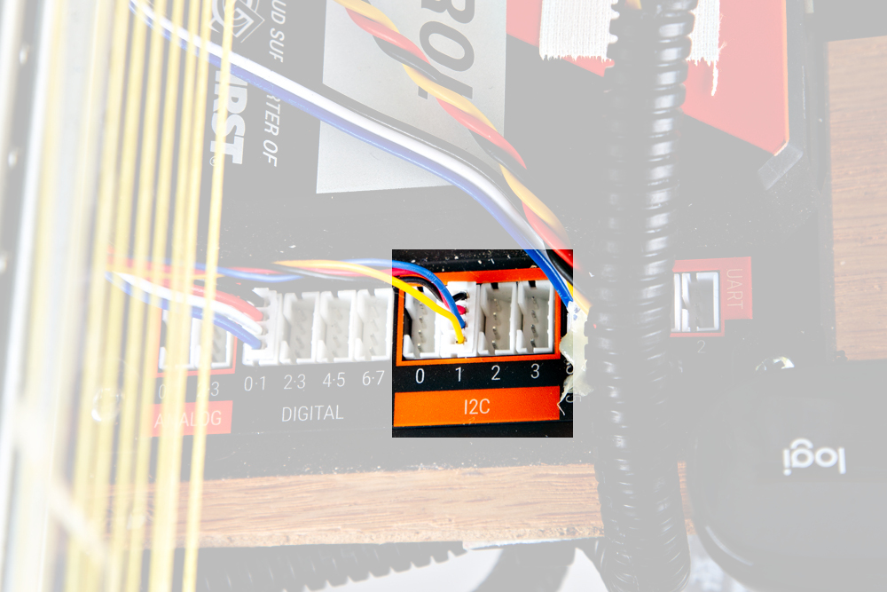
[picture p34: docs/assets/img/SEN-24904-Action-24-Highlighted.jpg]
I2C connection location

<figcaption markdown>I<sup>2</sup>C connection location</figcaption>
</figure>

!!! attention

	Reminder - make sure you peel off the yellow kapton tape! 

<figure markdown>
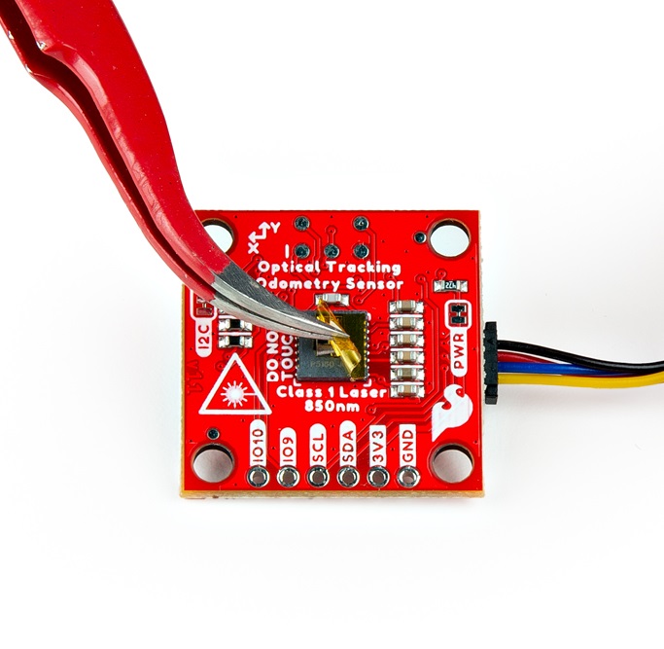
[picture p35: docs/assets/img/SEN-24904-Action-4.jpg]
Peel off the Kapton tape!

<figcaption markdown>Peel off the Kapton tape before use</figcaption>
</figure>

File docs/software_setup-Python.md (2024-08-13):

---
icon: simple/python
---

!!! attention
	If this is your first time working with Python, there are quite a few useful tutorials on getting started. The [Python Programming Section](https://learn.sparkfun.com/tutorials/python-programming-tutorial-getting-started-with-the-raspberry-pi/programming-in-python) of our Getting Started with the Raspberry Pi Tutorial has some good basic information and resources for getting started with Python. 

## Linux/Raspberry Pi Variants

We've written a python package to get you started with the SparkFun Optical Tracking Odometry Sensor. It's been included in the SparkFun Qwiic Python package, which aggregates all Python Qwiic drivers/modules to provide a single entity for Qwiic within a Python environment. The [Qwiic_Py GitHub Library ReadMe](https://github.com/sparkfun/Qwiic_Py) has more information on the Qwiic Python package. 

If you already have your Qwiic Python package installed, you can update it with the following command: 

```
pip install --upgrade sparkfun-qwiic

```

If you don't have the Qwiic Python package installed already, you can install it with the following command: 

```
pip install sparkfun-qwiic

```

If you prefer to install just this package, use the following command: 

```
pip install sparkfun-qwiic-otos

```

If you prefer downloading the code to build and install the package manually, you can grab them from the [GitHub Repository](https://github.com/sparkfun/Qwiic_Py).

<center>
	[SparkFun Optical Tracking Odometry Sensor Python Package GitHub](https://github.com/sparkfun/Qwiic_OTOS_Py/archive/refs/heads/master.zip){ .md-button .md-button--primary }
</center>

!!! attention
	If you are working with a Raspberry Pi and are using the new Bookworm distribution of the Raspberry Pi OS, refer to [these instructions](https://www.raspberrypi.com/documentation/computers/os.html#python-on-raspberry-pi) to setup a virtual environment.  

	Make sure to include the --system-site-packages flag:python3 -m venv <name of virtual environment> --system-site-packages 
	
	Then it is possible to install the packages using pip. 

## XRP/MicroControllers

If you are working with the XRP or other microcontroller, pip will not work for you. Instead, you'll need to install the Qwiic_I2C_Py driver as well as the Qwiic_OTOS driver. 

!!! attention
	These instructions are written for the XRP using the [XRPCode IDE](https://xrpcode.wpi.edu/). However the setup process is very similar for MicroPython and CircuitPython on any other board, so you should be able to follow along with these instructions using your IDE of choice!

### Install Qwiic_I2C_Py

Qwiic_I2C_Py is a generic I2C driver we have created to work on various platforms (such as MicroPython). Our Qwiic Python device drivers take advantage of Qwiic_I2C_Py to function correctly on any of the supported platforms, so it is a required dependency to use our OTOS Python driver.

Fist, go to the [Qwiic_I2C_Py repository](https://github.com/sparkfun/Qwiic_I2C_Py) and download it as a .zip file. Once downloaded, extract the `qwiic_i2c` folder within.

Connect your XRP to your computer over USB, navigate to the [XRPCode IDE](https://xrpcode.wpi.edu/), and connect to your XRP. For usage information, see the [XRPCode User Guide](https://xrpusersguide.readthedocs.io/en/latest/course/XRPCode.html).

Create a new folder within the `lib` directory (right-click on the folder), and name it `qwiic_i2c`.

<figure markdown>
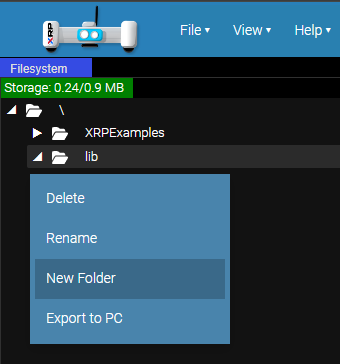
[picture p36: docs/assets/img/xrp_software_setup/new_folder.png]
Create a new folder in the directory

<figcaption markdown>Create a new folder in the `lib` directory</figcaption>
</figure>

<figure markdown>
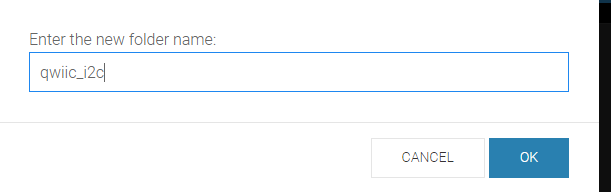
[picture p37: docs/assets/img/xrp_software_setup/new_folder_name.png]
Name the folder qwiic_i2c

<figcaption markdown>Name the folder `qwiic_i2c`</figcaption>
</figure>

Upload the files from the previously extracted `qwiic_i2c` folder into the new folder you just created on the XRP. From the **File** menu, choose the Upload to XRP option: 

<figure markdown>
Choose the "Upload to XRP" option
<figcaption markdown>Choose the "Upload to XRP" option</figcaption>
</figure>

Then select the extracted files: 

<figure markdown>
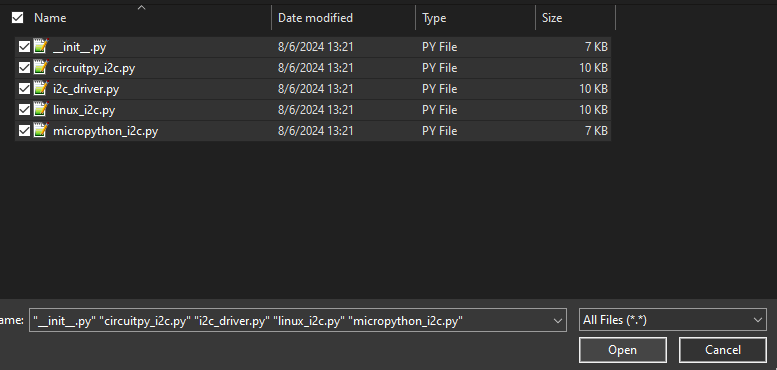
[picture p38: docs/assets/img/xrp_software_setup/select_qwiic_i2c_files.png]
Select the extracted I2C Files

<figcaption markdown>Select the extracted I2C Files</figcaption>
</figure>

Then choose the newly created `qwiic_i2c` folder on the XRP:

<figure markdown>
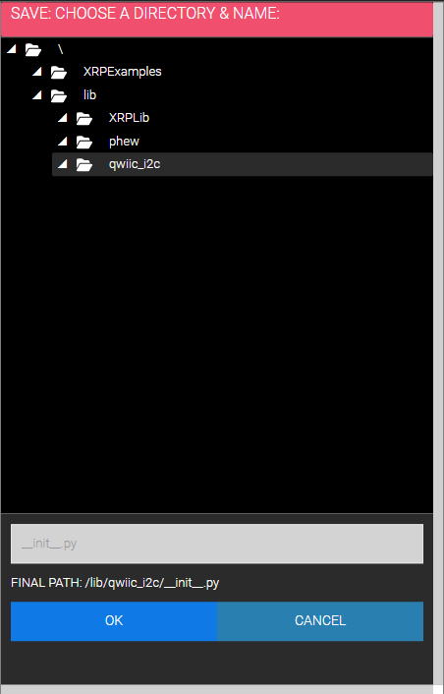
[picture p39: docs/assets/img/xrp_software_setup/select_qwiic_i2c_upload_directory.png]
Choose the newly created folder

<figcaption markdown>Choose the newly created `qwiic_i2c` folder</figcaption>
</figure>

Uploading...

<figure markdown>
Update in Progress
<figcaption markdown>Update in Progress</figcaption>
</figure>

You can test to confirm correct installation by typing `import qwiic_i2c` followed by `qwiic_i2c.get_i2c_driver().scan()` in the Shell. If no errors are printed, then the Qwiic_I2C_Py driver has been installed correctly!

<figure markdown>
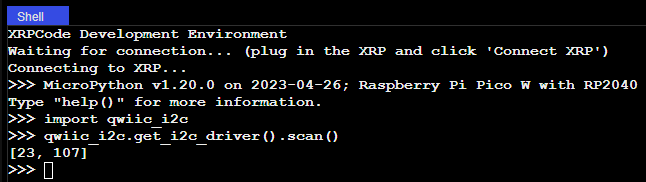
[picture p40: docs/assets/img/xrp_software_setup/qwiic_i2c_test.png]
Testing install

<figcaption markdown>Testing the install</figcaption>
</figure>

### Install Qwiic_OTOS_Py

Fist, go to the [Qwiic_OTOS_Py repository](https://github.com/sparkfun/Qwiic_OTOS_Py) and download just the `qwiic_otos.py` file.

Connect your XRP to your computer over USB, navigate to the [XRPCode editor](https://xrpcode.wpi.edu/), and connect to your XRP. For usage information, see the [XRPCode User Guide](https://xrpusersguide.readthedocs.io/en/latest/course/XRPCode.html).

Upload the `qwiic_otos.py` file into the `lib` folder on the XRP. From the **File** menu, choose the Upload to XRP option: 

<figure markdown>
Select the "Upload to XRP" option from the file menu
<figcaption markdown>Select the "Upload to XRP" Option from the File Menu</figcaption>
</figure>

Select the qwiic_otos.py file: 

<figure markdown>
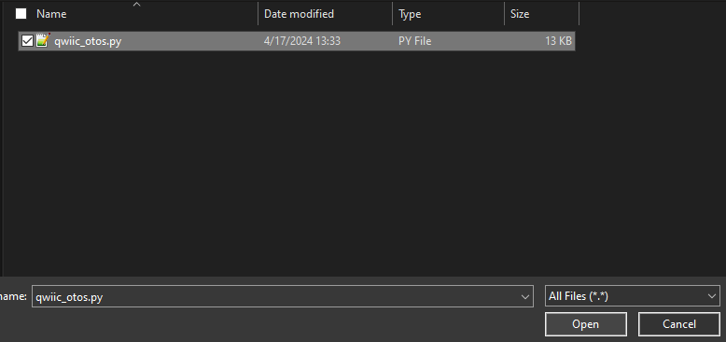
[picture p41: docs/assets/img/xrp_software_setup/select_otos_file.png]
Select the qwiic_otos.py file

<figcaption markdown>Select the qwiic_otos.py file</figcaption>
</figure>

Then select the lib folder on the XRP:

<figure markdown>
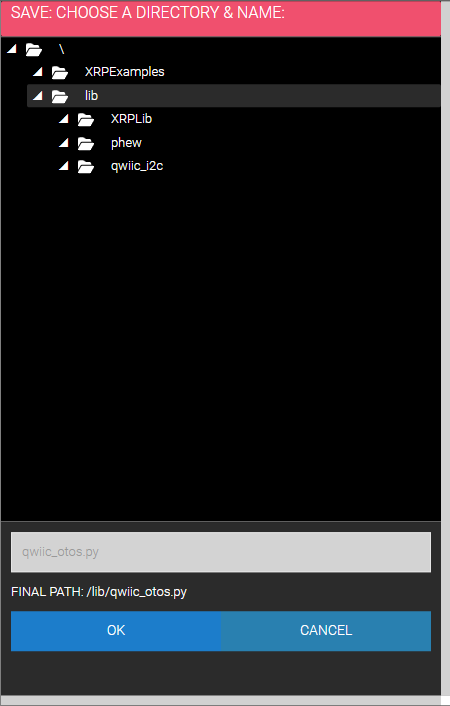
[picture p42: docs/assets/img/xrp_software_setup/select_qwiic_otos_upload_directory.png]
Select the lib folder on the XRP

<figcaption markdown>Select the lib folder on the XRP</figcaption>
</figure>

Updating... 

<figure markdown>
Updating
<figcaption markdown>Updating</figcaption>
</figure>

You can test to confirm correct installation by typing `import qwiic_otos` followed by `qwiic_otos.QwiicOTOS().is_connected()` in the Shell. If no errors are printed, then the Qwiic_OTOS_Py driver has been installed correctly!

Testing the install:

<figure markdown>
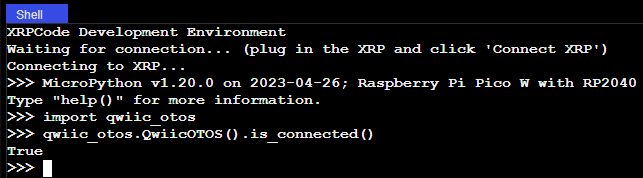
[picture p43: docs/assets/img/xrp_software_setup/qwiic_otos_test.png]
Testing the install

<figcaption markdown>Testing the install</figcaption>
</figure>

## Visualization

In addition to the package provided here, we have written a Python script that allows you to visualize the XRP in real time. Download via the button below. 

<center>
	[XRP Visualization Script](assets/SparkFun_OTOS_XRP_Visualization.zip){ .md-button .md-button--primary download="SparkFun_OTOS_XRP_Visualization.zip" }
</center>

<figure markdown>
Visualization Script in Action
<figcaption markdown>Visualization Script in Action</figcaption>
</figure>

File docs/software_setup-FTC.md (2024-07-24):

---
icon: first
---

## Update the FTC Robot Controller

!!! attention

	Version v9.2 of the [FTC SDK](https://github.com/sparkfun/SparkFun_Qwiic_OTOS_FTC_Java_Library) added [our Java driver](https://github.com/sparkfun/SparkFun_Qwiic_OTOS_FTC_Java_Library), so it is no longer necessary to manually install those files. Make sure you have at least v9.2 installed on your Control Hub before continuing!

## Hardware Configuration

You can edit your robot's hardware configuration from the Driver Station. Select the I<sup>2</sup>C port that the OTOS is connected to, then tap the "Add" button. From the dropdown, you should see "SparkFun OTOS" like so:

<figure markdown>
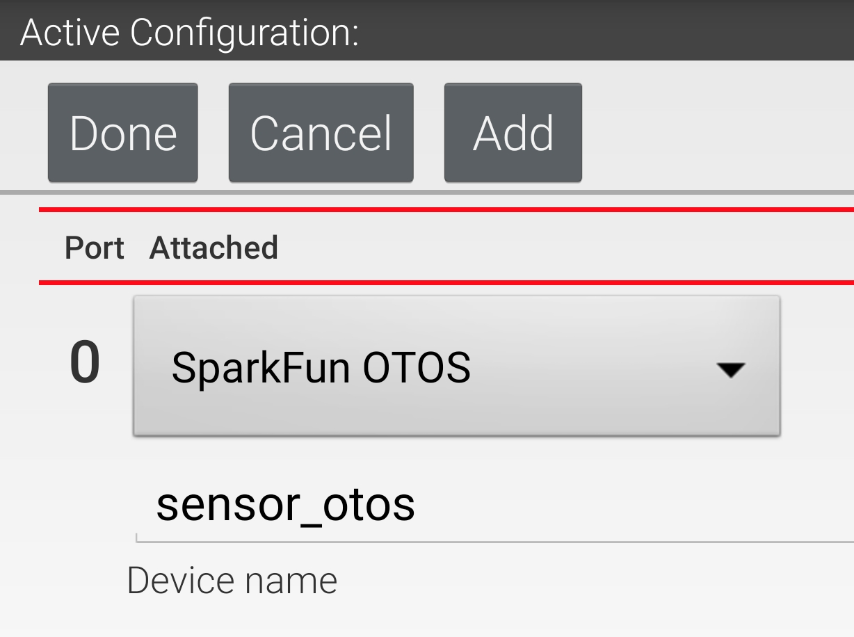
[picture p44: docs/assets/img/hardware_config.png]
Hardware Configuration

<figcaption markdown>Hardware Configuration</figcaption>
</figure>

!!! warning

	If you don't see "SparkFun OTOS" in the dropdown, make sure you have updated your Control Hub to use at least version v9.2 of the FTC SDK. 

Then enter a name for the sensor. The sample OpMode assumes it is named `sensor_otos`, so that is recommended.

Once done, save your hardware configuration, then you're ready to run the sample OpMode!

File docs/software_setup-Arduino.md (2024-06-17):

---
icon: simple/arduino
---

!!! attention
	If this is your first time using Arduino, please review our tutorial on [installing the Arduino IDE](https://learn.sparkfun.com/tutorials/installing-arduino-ide). If you have not previously installed an Arduino library, please check out our [installation guide](https://learn.sparkfun.com/tutorials/installing-an-arduino-library).

We've written a library to get you started with the SparkFun Optical Tracking Odometry Sensor. You can obtain this library through the Arduino Library Manager by searching for "Odometry" and installing the latest version from SparkFun. If you prefer downloading libraries manually, you can grab them from the [GitHub Repository](https://github.com/sparkfun/SparkFun_Qwiic_OTOS_Arduino_Library).

<center>
	[SparkFun Optical Tracking Odometry Sensor Arduino Library GitHub](https://github.com/sparkfun/SparkFun_Qwiic_OTOS_Arduino_Library/archive/refs/heads/main.zip){ .md-button .md-button--primary }
</center>

In addition to the library provided here, we have written a Python script that allows you to visualize the XRP in real time. Download via the button below. 

<center>
	[XRP Visualization Script](assets/SparkFun_OTOS_XRP_Visualization.zip){ .md-button .md-button--primary download="SparkFun_OTOS_XRP_Visualization.zip" }
</center>

<figure markdown>
Visualization Script in Action
<figcaption markdown>Visualization Script in Action</figcaption>
</figure>

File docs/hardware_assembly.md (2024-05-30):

---
icon: xrp
---

The SparkFun Optical Tracking Odometry Sensor needs to be rigidly mounted to a robot chassis and oriented flat to the floor in order to get accurate data. If you don't already have a mount, there are a few 3D printing models you can use. That said, you may need to design your own mount for this board, depending on your use case. 

The height that the sensor needs to be mounted will be dependent on the surface being read. If you have a shiny or glossy surface, you should be able to mount the sensor anywhere in the range of 10mm to 27mm, measured from the front face of the optical sensor. If you have a darker or more diffuse surface, you may need to mount the sensor at the low-end of that range. You'll need to test to determine what height works for your surface.

You can access the XRP mount on Printables:  

<center>
	[XRP Mount on Printables](https://www.printables.com/model/872179-odometry-clip-for-xrp){ .md-button .md-button--primary target="_blank" }
</center>

!!! warning

	Accurate readings require that the sensor is mounted correctly; attempting to move the sensor by hand may work, but tracking accuracy will suffer.

The image below shows the 3D mounted clip with the Optical Tracking Sensor attached to an XRP: 

<figure markdown>
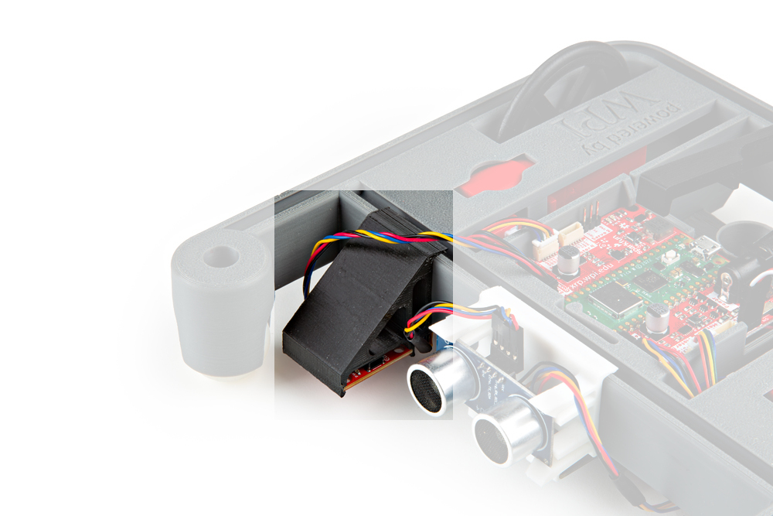
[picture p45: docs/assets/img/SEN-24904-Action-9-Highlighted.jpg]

<figcaption markdown>Optical Tracking Sensor Mounted to the XRP</figcaption>
</figure>

Here is the underside of the XRP with the Optical Tracking Sensor attached via the mounting clip: 

<figure markdown>
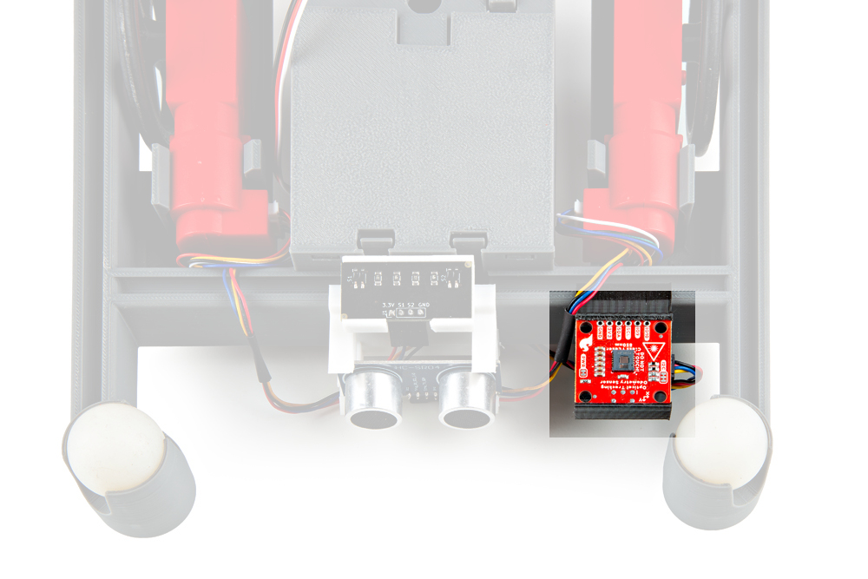
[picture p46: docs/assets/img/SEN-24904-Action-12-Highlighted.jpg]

<figcaption markdown>Optical Tracking Sensor Mounted to the XRP</figcaption>
</figure>

!!! attention

	Reminder - make sure you peel off the yellow kapton tape! 

<figure markdown>
Peel off the Kapton tape!
<figcaption markdown>Peel off the Kapton tape before use</figcaption>
</figure>

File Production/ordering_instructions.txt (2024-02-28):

panel size, 169x117mm
PCB thickness, 1.6mm
number of layers, 2
soldermask color, Red
silkscreen color, White
oz copper, 1oz
finish, HASL lead free
stencils, top+bottom
pcs per panel, 24
min trace width, 0.2286mm / 0.0090in
min drill size, 0.3048mm / 0.0120in

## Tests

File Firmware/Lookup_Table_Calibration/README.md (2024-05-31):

# SparkFun OTOS Lookup Table Calibration

This folder contains the scripts and files that were used to create the lookup table calibration for the [SparkFun Optical Tracking Odometry Sensor](https://www.sparkfun.com/products/24904). This is mainly provided for transparency on how the lookup table was created. **This is not a tutorial, and no support will be provided for anyone attempting to do this themselves!** This requires many pieces of software and hardware, some details are ommitted, and it can take **many hours** to go from nothing to a final lookup table.

## Precursory Info

The PAA5160 is the optical tracking sensor used on the board, and it was discovered in testing that there is resolution variation based on how fast the surface is moving. However the resolution variation is nonlinear, and the variation for one axis depends on the velocity in both axes. Below is a plot of the x-axis resolution variation (measured velocity divided by true velocity) versus the true velocity in both axes, where the color scale goes from 0.9 (purple) to 1.0 (yellow):

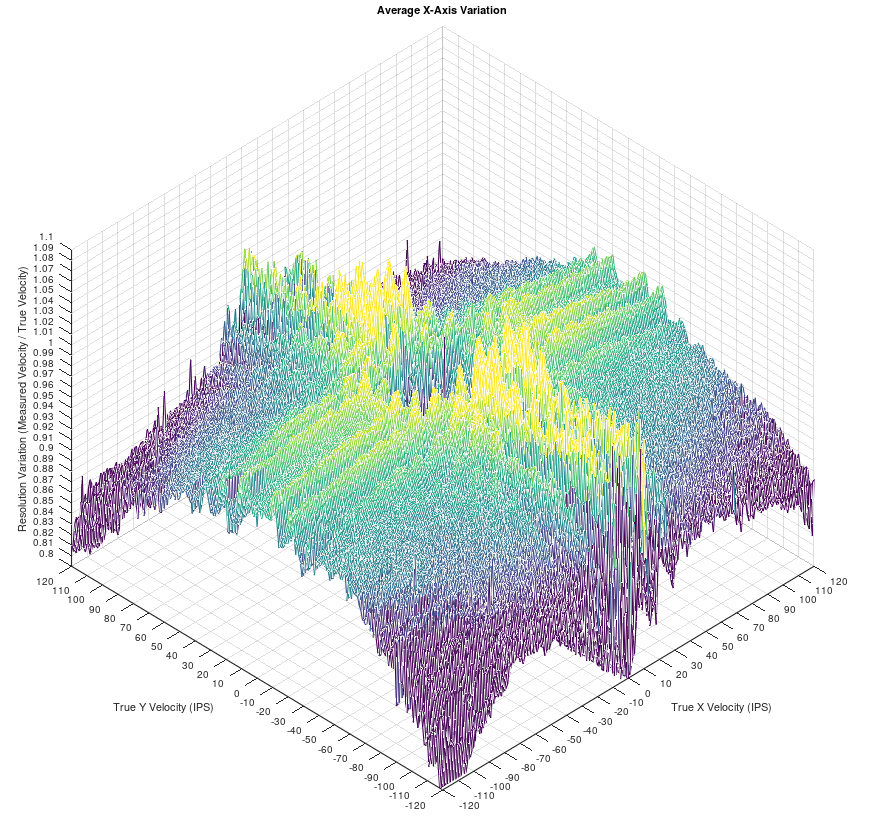
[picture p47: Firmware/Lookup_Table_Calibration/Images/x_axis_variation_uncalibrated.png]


Ideally, this should be a flat surface, but has the overall shape of an inverted paraboloid with ridges in both directions. The y-axis is similar, but with flipped x and y axes. The y-axis is also slightly asymetric, likely due to the laser being off-center from the sensor.

Testing has shown this variation to be consitent per sensor, and fairly similar between different sensors. The idea to correct this is to store this variation in the firmware, then at every time step, measure the velocity and multiply it by the inverse of the variation at that velocity. Theoretically, this should cause the surface to become flat.

Rather than storing the variation, the inverse (referred to as the scalar lookup table) is stored in order to reduce the amount of floating point division in each loop iteration to optimize performance. The image below is shows the scalar lookup table versus the *measured* velocity in both axes (instead of the *true* velocity, since that's not known at runtime):

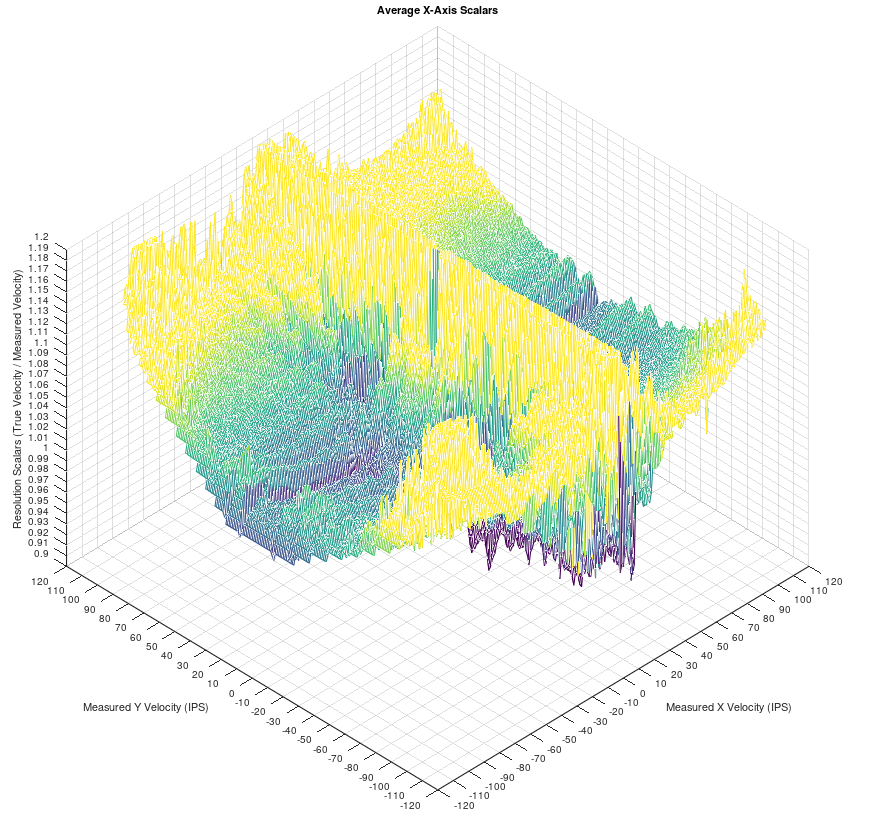
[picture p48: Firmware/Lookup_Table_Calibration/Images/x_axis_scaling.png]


The firmware needs to store this lookup table up to +/- 100 in/s (2.5m/s), which is the max rated speed of the PAA5160. The lookup table in the image above has a resolution of 1 in/s, meaning 201 * 201 = 40,401 data points would need to be stored. The STM32C0 microcontroller on the board only has 32k of flash memory, so this needs to be stored more efficiently.

The main space savings here is to store a sparse version of this lookup tableT Firmware version v1.0 uses 51 * 51 = 2,601 data points; the 51 grid coordinate were chosen by hand to capture just the peaks and valleys. At every time step, the measured velocity is used to index into the lookup table, and a bilinear interpolation is used to approximate the correct scaling value. Below is an image of the sparse lookup table:

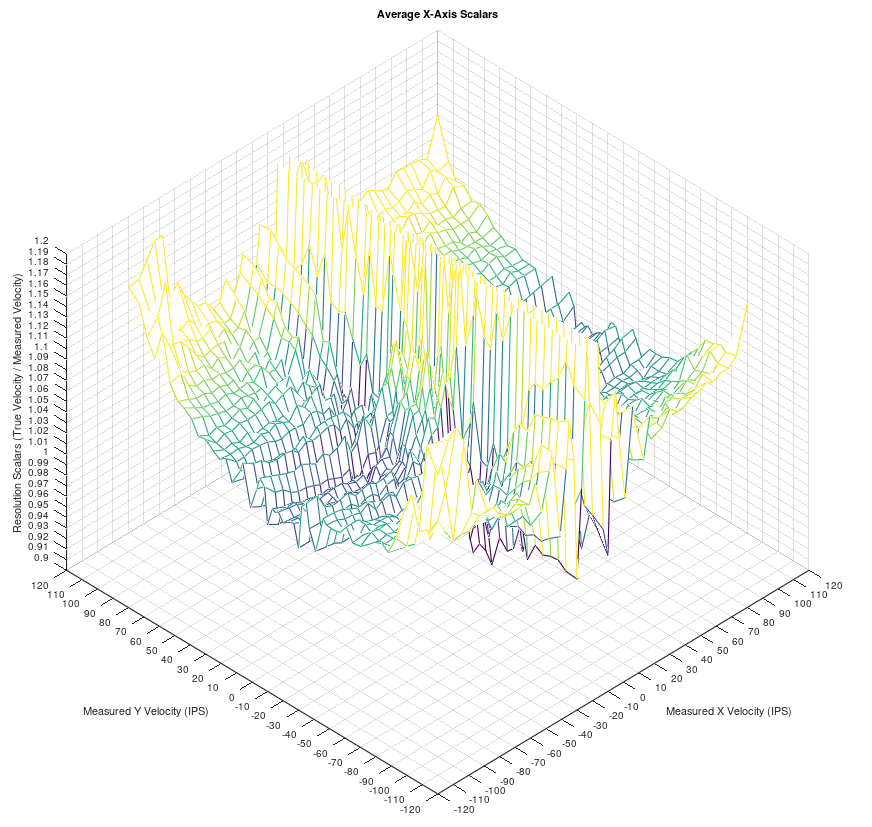
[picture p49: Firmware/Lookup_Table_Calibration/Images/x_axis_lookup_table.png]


The other memory saving measure is to store each value in a single byte, requiring only about 2.6kB (5.2kB total, since a separate lookup table is needed for each axis). Each byte has a resolution of 0.2%, allowing scaling values from 0.774 to 1.254.

To verify this makes an improvement, the resolution variation from the data in the first figure above is multiplied by the interpolated sparse lookup table, which results in the surface below, where the color scale goes from 0.98 (purple) to 1.02 (yellow):

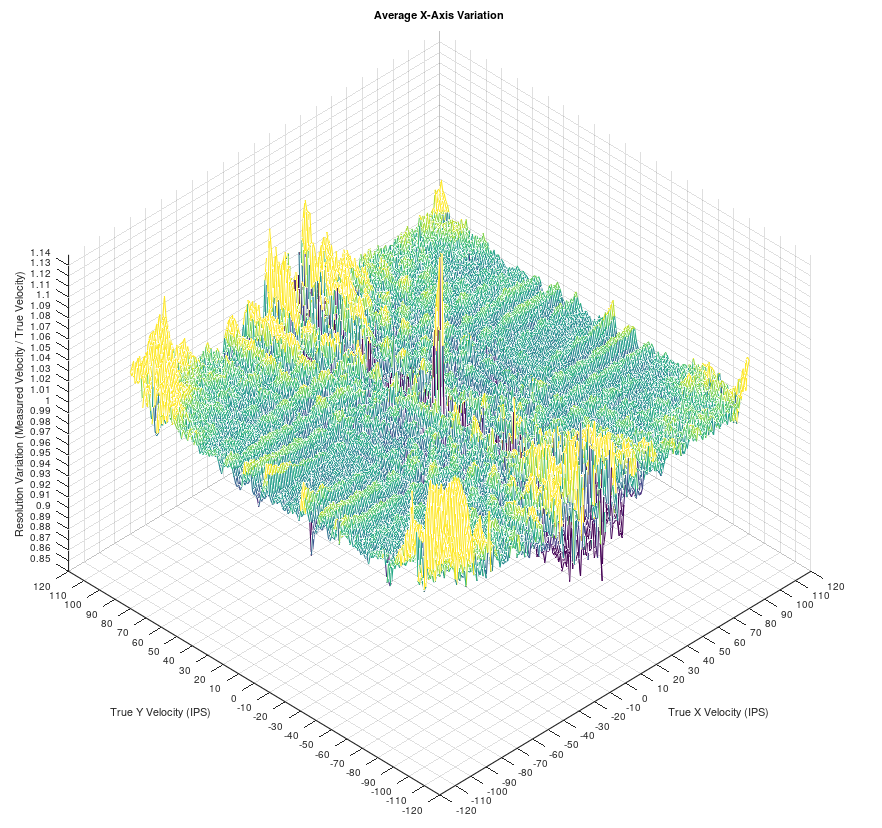
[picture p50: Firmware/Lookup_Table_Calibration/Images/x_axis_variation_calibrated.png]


The surface is overall much more flat than before. Some ridges are and other fluctuations are still present, at least partially due to the innaccuracy of the sparse lookup table. Although in reality there is more variation than this, since the measurement noise causes the lookup table to be indexed into the wrong place, meaning a slightly incorrect scaling value is used. But the main benefit is that the surface is overall flat instead of an inverted paraboloid.

## Materials Used

This calibration is done by spinning a disc of the surface in front of the sensor at a range of speeds and angles to generate the resolution variation data in the first image above. Below is an image of the setup used:

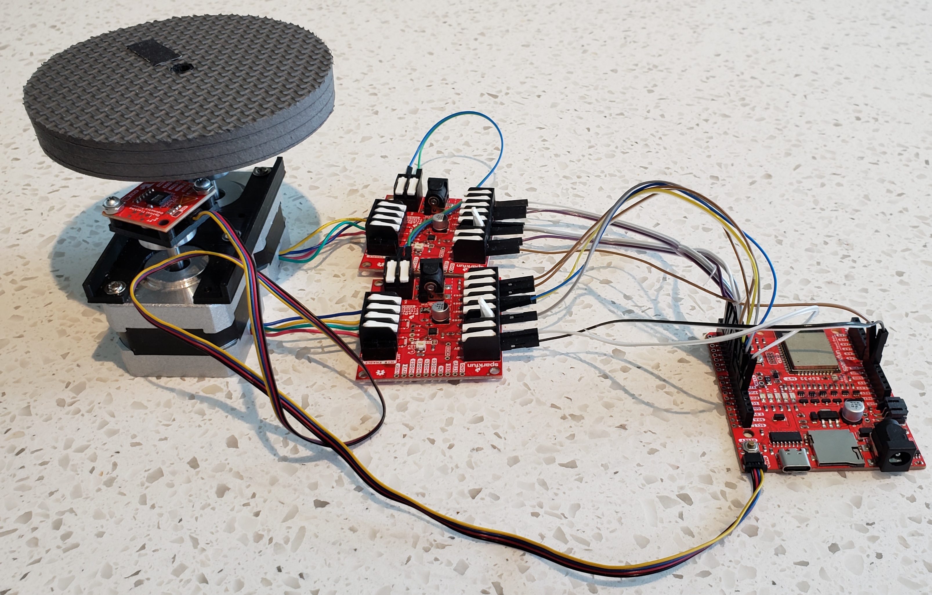
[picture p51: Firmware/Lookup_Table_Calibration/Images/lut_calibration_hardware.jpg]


This setup uses the following hardware:

* 1x [12V power supply](https://www.sparkfun.com/products/15313) (at least 500mA)
* 2x [stepper motors](https://www.sparkfun.com/products/9238)
* 2x [stepper motor hubs](https://www.sparkfun.com/products/10006)
* M3 and 4-40 screws
* 2x [stepper motor drivers](https://www.sparkfun.com/products/16836)
* 1x [ESP32 IoT RedBoard](https://www.sparkfun.com/products/19177)
* 1x [Optical Tracking Odometry Sensor](https://www.sparkfun.com/products/24904)
* [Jumper wires](https://www.sparkfun.com/products/12795)
* 1x [Qwiic Cable](https://www.sparkfun.com/products/17257)
* Disc of surface, at least 4" diameter
    * In this setup, an FTC foam tile was cut using a CNC milling machine into a 4" diameter disc with an 0.3" hole in the center for mounting
* 3D printed parts:
    * [Motor bracket](3D_Printables/stepper_motor_bracket.stl) (positions shafts 1.75" apart from each other)
    * [OTOS mount](3D_Printables/stepper_otos_mount.stl)
    * [Disc mount](3D_Printables/stepper_disc_mount.stl) (works with FTC foam tile disc, but another design may be needed for other discs)

And the following software is required:

* [Arduino IDE](https://www.arduino.cc/en/software) with [ESP32 core](https://github.com/espressif/arduino-esp32) to program the IoT RedBoard
* [MATLAB](https://www.mathworks.com/products/matlab.html) (not tested) or [GNU Octave](https://octave.org/) (free) to run included scripts
    * If using Octave,the [Intrument Control Package](https://octave.sourceforge.io/instrument-control/index.html) needs to be installed; a tutorial is available [here](https://www.edn.com/read-serial-data-directly-into-octave/)
* [STM32CubeIDE](https://www.st.com/en/development-tools/stm32cubeide.html) and [STM32CubeProgrammer](https://www.st.com/en/development-tools/stm32cubeprog.html) to modify, build, and flash the firmware with the new calibration to the sensor, see instructions [here](../README.md)

Again, this is not a tutorial, this is only documentation on how this lookup table calibration was done for transparency. If you want to do this yourself, you may need to substitute some items, design your own 3D printed mounts, modify some code, etc. **Support will not be provided, you'll be on your own!**

## Calibration Process

Note - This setup has the optical sensor oriented upwards. It includes an IR bandpass filter, so it is usually not necessary to block ambient light. However if the room has sunlight coming through a window, it may be necessary to add some kind of light shield around the setup, otherwise the optical sensor can lose tracking. This can be done with something like a large carboard box over the entire setup.

### Assembly

Assemble the setup as shown in the image above. Ensure the disc is positioned at a suitable distance from the sensor (10mm is used for the FTC foam tile). See the [Arduino sketch](Data_Collection/Data_Collection.ino) for the connections between the IoT RedBoard and stepper motor drivers. The stepper motor wires were connected to the drivers with the following pinout:

* A+ -> Blue
* A- -> Yellow
* B+ -> Red
* B- -> Green

The provided mount for the OTOS is not symmetric. The optical sensor on the board has the laser and sensing element slightly off-center, and this needs to be accounted for to get accurate data. The mount includes a feature indicating the intended orientation of the sensor, align the axes in the silkscreen with this feature.

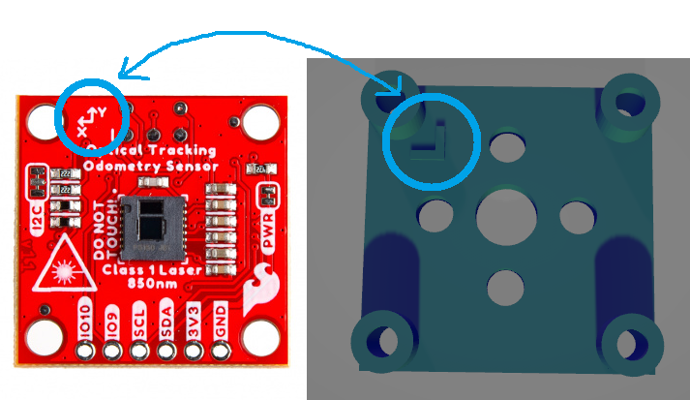
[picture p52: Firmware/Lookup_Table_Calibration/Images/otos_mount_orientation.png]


### Verification Test

The following tests should be performed to verify the setup is working. Open the [Arduino sketch](Data_Collection/Data_Collection.ino), then change the value of `currentTest` near the top of the sketch and run the following tests in order:

* OTOS Angle
    * This should rotate the OTOS stepper by +90 degrees, then -90 degrees. This will verify the correct motor is being controlled, and that it rotates in the correct direcion and angle.
* Disc Ramp
    * This should spin the disc stepper, ramping up to speed the max speed required by the final data collection test, then ramping back down to zero.
    * This test can also be used to ensure the disc does not wobble while spinning; it may be necessary to shim the 3D printed mount.
    * If the disc motor stops spinning at high speed, it may be necessary to add more mass so it has more inertia.
* Zero Angle
    * This should spin the disc stepper at a medium speed, then use the data from the optical sensor to zero the angle of the OTOS relative to the surface motion.

### OTOS Mount Centering

The mount will get the optical sensor close to centered on the motor shaft, but the mounting holes allow for some variation in exact location. The sensor should be positioned as close to center as possible to get the most accurate data for the final data collection test. This can be done using the mount centering test:

Edit the value of `currentTest` to run the mount centering test. This will first find the zero angle for the optical sensor, then sweep the disc through a range of speeds in all 4 orthogonal directions.

While the test is running, it is also necessary to run the [mounting test script](Data_Collection/otos_mounting_test.m) in MATLAB or Octave to collect the data from the test and generate the output plots. Set the COM port used by the IoT RedBoard near the top of the script, then run the script while the zero angle is being found to synchronize with the start of the test.

Once the test completes, 2x plots similar to the following should be displayed:

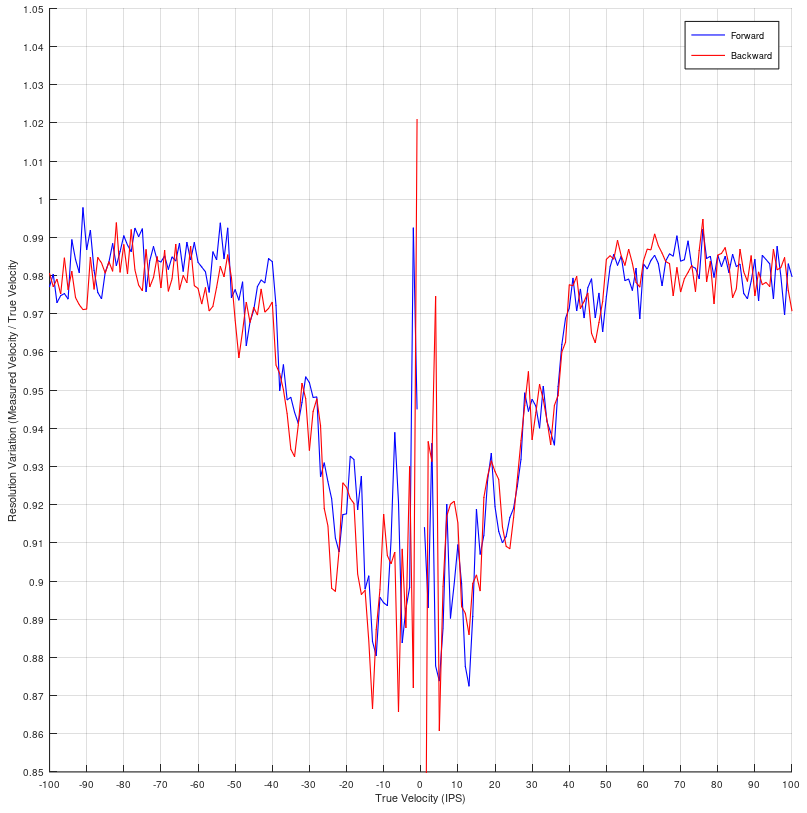
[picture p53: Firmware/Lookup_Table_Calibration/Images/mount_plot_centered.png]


If the red and blue lines overlap with each other in both plots like above, then the sensor is well centered. If it's not centered, there will be an offset between the lines like below:

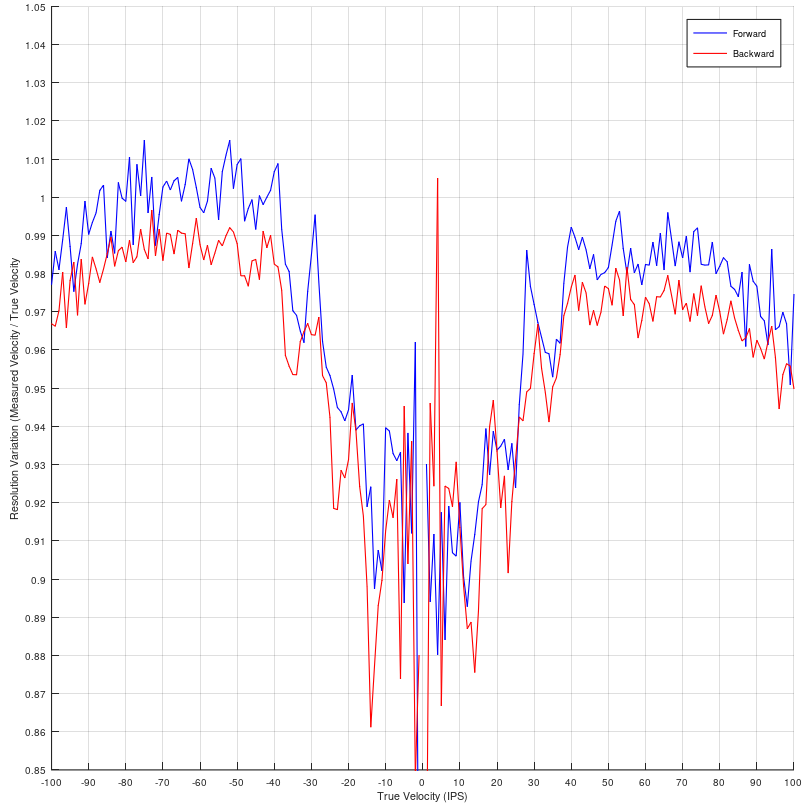
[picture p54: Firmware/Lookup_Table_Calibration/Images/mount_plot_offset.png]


In this case, the sensor needs to be re-mounted, and shifted in whatever direction causes the lines to overlap. The noise in the data can be reduced by increasing the value of `numSamples` near the top of the Arduino sketch, although this increases the amount of time the test takes.

### Data Collection

Once everything above has been completed, data collection can begin to create the lookup table. Edit the value of `currentTest` to run the data collection test. This will first find the zero angle for the optical sensor, then sweep the disc speed and sensor angle through a grid of velocities.

While the test is running, it is also necessary to run the [lookup table data collection script](Data_Collection/otos_mounting_test.m) in MATLAB or Octave to collect the data from the test and generate the output plots. Set the COM port used by the IoT RedBoard near the top of the script, then run the script while the zero angle is being found to synchronize with the start of the test.

Note - **THIS TEST TAKES A LONG TIME!** By default, it measures velocities from -120 to +120 in/sec with 1 in/sec resolution, which results in 241 * 241 = **58,081 data points**. With `numSamples` set to the default of 8, it makes about 16x measurements per second, so **this takes about an hour**. However if only a single sensor is calibrated, the data will likely be too noisy for a good lookup table, so it is recommended to increase `numSamples` by 8x (which increases the test time by the same amount). The lookup table used in firmware v1.0 was generated with `numSamples` set to 8, and averaged across 8 different sensors (effectively 64 samples per data point).

Note - In the final data collection test, the zero angle may be slightly off; this can be corrected by editing `correctionAngle` near the top of the sketch. This is easiest to identify early in the test if the output plot looks significantly asymmetric.

Once the test completes, the data will be saved to a pair of CSV files, which can be used in [this script](Calibration_Data/average_variation_and_compute_lookup_tables.m) to compute the final lookup tables. The CSV files included in [Calibration_Data](Calibration_Data/) folder is the data used to create the final lookup table used in firmware version v1.0.

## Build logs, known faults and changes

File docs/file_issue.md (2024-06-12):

# Did we make a mistake?

Spot something wrong? Please let us know. 

!!! attention
    This is not where customers should seek assistance on a product. If you require technical assistance or have questions about a product that is not working as expected, please head over to the [SparkFun Technical Assistance](https://www.sparkfun.com/technical_assistance) page for some initial troubleshooting.
    <center>
    [SparkFun Technical Assistance Page](https://www.sparkfun.com/technical_assistance){ .md-button .md-button--primary }
    </center>
    
    If you can't find what you need there, you'll need a [Forum Account](https://forum.sparkfun.com/ucp.php?mode=register) to search product forums and post questions.

## Discrepancies in the Documentation

All of this documentation can be modified by you! Please help us make it better.

* The documentation files for these pages are contained in the [`docs` folder](https://github.com/sparkfun/SparkFun_Optical_Tracking_Odometry_Sensor/tree/main/docs) of the [SparkFun Optical Tracking Odometry Sensor - PAA5160E1 (Qwiic)](https://github.com/sparkfun/SparkFun_Optical_Tracking_Odometry_Sensor) repository.

### Spot something wrong?
If a section of the documentation is incorrect, please [open an issue](https://github.com/sparkfun/SparkFun_Optical_Tracking_Odometry_Sensor/issues) and let us know.

### Do you have a suggested correction?
1. With a GitHub account, fork this repo
2. Add your correction(s) or improvement(s) to the markdown file(s)
3. File a pull request with your changes, and enjoy making the ~~words~~ ~~worlds~~ world a better place.
    * Once received, the documentation specialist will automatically be notified.
    * We will review your suggested improvement(s) to make sure they are correct and fit within our documentation standards.

## Problems in the Hardware Design

All of our designs are open-source! Please help us make it better.

* Our board design files are contained in the [`Hardware` folder](https://github.com/sparkfun/SparkFun_Optical_Tracking_Odometry_Sensor/tree/main/Hardware) of the [SparkFun Optical Tracking Odometry Sensor - PAA5160E1 (Qwiic)](https://github.com/sparkfun/SparkFun_Optical_Tracking_Odometry_Sensor) repository. 

### Does something not make sense?
If part of the design is confusing, please [open an issue](https://github.com/sparkfun/SparkFun_Optical_Tracking_Odometry_Sensor/issues) and let us know.

### Did we forget to include an important function of the board?
* Please keep in mind that we may intentionally exclude certain functions of the board to meet our product design requirements. *(For example, our Qwiic Micro boards are intended to fit on a small board layout and only use I<sup>2</sup>C communication; therefore, we may not have the SPI and interrupt pins available for users.)*
* If part of the board's functionality is missing, please [open an issue](https://github.com/sparkfun/SparkFun_Optical_Tracking_Odometry_Sensor/issues) and file a feature request.

### Do you wish to contribute directly to improving the board design?
1. With a GitHub account, Fork this repo
2. Add your design improvement(s)
3. File a pull request with your changes, and enjoy making the ~~words~~ ~~worlds~~ world a better place.
    * Once received, the engineer in charge of the original design will automatically be notified.
    * We will review your suggested improvement(s), if they are within our board design standards and meet our product design requirements, we will flag these changes for our next board revision. *(Please note, that even if your suggestion is accepted, these changes may not be immediate. We may have to cycle through our current product inventory first.)*

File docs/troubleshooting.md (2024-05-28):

---
icon: fontawesome/solid/question
---

A few things we've noticed: 

## Calibration

Got the spins? If the IMU isn't calibrated correctly, the gyroscope will think the robot is constantly rotating and you may see something like below. If you find this, try re-calibrating your bot. 

<figure markdown>
You spin me right round baby right round
<figcaption markdown>Example of Calibration Error</figcaption>
</figure>

!!! note
    <span class="glyphicon glyphicon-question-sign" aria-hidden="true"></span>
        <strong> Not working as expected and need help? </strong> <br /><br />

    If you need technical assistance and more information on a product that is not working as you expected, we recommend heading on over to the <a href="https://www.sparkfun.com/technical_assistance">SparkFun Technical Assistance</a> page for some initial troubleshooting. <br /><br />

    <div style="text-align: center"><a href="https://www.sparkfun.com/technical_assistance" target="sfe_technical_assistance" class="md-button">SparkFun Technical Assistance Page</a></div>

    If you don't find what you need there, the <a href="https://forum.sparkfun.com/index.php">SparkFun Forums</a> are a great place to find and ask for help. If this is your first visit, you'll need to <a href="https://forum.sparkfun.com/ucp.php?mode=register">create a Forum Account</a> to search product forums and post questions.<br /><br />

    <div style="text-align: center"><a href="https://forum.sparkfun.com/ucp.php?mode=register" class="md-button">Create New Forum Account</a>&nbsp;&nbsp;&nbsp;<a href="https://forum.sparkfun.com/index.php" class="md-button md-button--primary">Log Into SparkFun Forums</a></div>

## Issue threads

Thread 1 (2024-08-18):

Offset registers always read 0

sfe-SparkFro, 2024-08-18:
The root problem is [`updatePoseFromHostShadow()`](https://github.com/sparkfun/SparkFun_Optical_Tracking_Odometry_Sensor/blob/3501e487bd247fff5e409eeb6b0a7a30b22fb9a8/Firmware/SFE/Src/main.cpp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) does not set register contents. That should be done after checking if `allRegsWritten` is true.

SizzinSeal, 2025-02-02:
Setting the offset will sometimes fail without the Linux I2C/SMBus subsystem reporting an error.

Unlike other configuration commands like setting the angular scalar, we can't get the offset from the sensor to verify it has been applied properly. This is a major concern for my team, as it's only a matter of time this leads to a failure outside of testing.

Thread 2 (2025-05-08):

Bad bias Instability and  Speed-dependent optical sensor errors

uecken, 2025-05-08:
Hi, I would like to use this module for a pen plotter robot with 1mm positioning accuracy.

However, current firmware has 2 issues.

1. Even when stationary, it rotates about 0.01° every 2 seconds (=18°/h). This instability is very bad compared to the other IMU module BNO085

2.The faster the moving speed, the larger the distance error.
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

While I was following this issue, I checked the following article. I will try this if possible.
https://github.com/sparkfun/SparkFun_Optical_Tracking_Odometry_Sensor/tree/main/Firmware/Lookup_Table_Calibration

Is there any way to solve issue 1?
Could it be that the bias stability or temperature characteristic calibration of the LSM6DSO is poor?

sfe-SparkFro, 2025-05-08:
Hi there, thanks for your feedback and data!

> 1. Even when stationary, it rotates about 0.01° every 2 seconds (=18°/h). This instability is very bad compared to the other IMU module BNO085

I believe this is a limitation of the IMU itself, I don't think there's a way to make it better in firmware. To my knowledge, it does not have any kind of temperature compensation or similar, so higher bias instability is to be expected than higher-end IMUs. This was determined to be acceptable for the first version of this sensor, because the primary application was FIRST Tech Challenge robots that only run autonomously for 30 seconds, so well under 1 degree by the end. However, totally understand that other applications may need more accuracy for longer, so we can definitely consider a better IMU for a future revision, if and when we do that!

>・Large angular velocity range ±2000 dps (degrees per second)

Because the primary application is FIRST Tech Challenge robots that can easily have very high rotation rates during collisions, the max velocity range of 2000 dps was chosen as default for the firmware. One possible improvement for future firmware is to make this configurable via the I2C registers.

>・Calibration with short-time samples (64 samples)

This would probably also be improved by using a lower angular velocity range, since the noise floor would be lower.

>・No temperature calibration function

Again, this would require a different IMU in a future hardware revision (if and when we do that).

> 2. The faster the moving speed, the larger the distance error.

This one is more difficult to nail down the root cause, as there are a number of possible sources of error.

1. As documented in the Lookup Table Calibration documentation, the calibration in the firmware was created using the foam surface used in FIRST Tech Challenge. My limited testing of other surfaces showed this to be an improvement all around, however you may be able to get better accuracy by performing the calibration on whatever surface you're using.
2. If you look closely at the final accuracy plot, you'll notice "ridges"; some speeds result in slightly higher resolution than nominal, some are slightly lower. It's possible that the exact speed you're running at lands in one of these ridges, so you may get better accuracy by traveling at a slightly different speed (not necessarily faster or slower, just different).
    * 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

STB3, 2025-05-09:
Hi!
There is no need to make a new PCB for using a different IMU. The Bosch BMI323 is pin compatible.
It gives me (using the BMI built in calibration + the SW calibration) approx 0.3 degrees drift in 5 min (3.6°/h). The BMI has 16 bit registers and some other features so the firmware changes are quite big. I'm using  the library with the STM32G491.
STB

uecken, 2025-05-09:
Wow, thank you for your advice.
So you say the footprint is same.

BMI323
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

LMS6DS0
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

I have no experience replacing small surface mounted ICs. Can I remove the LMS6DS0 using a heat gun and then solder the BM323 again with the heat gun?

Then, upload this Changes_OTOS_BMI323.zip files to STM32C0?

STB3, 2025-05-09:
Removing with a heat gun at approx. 360°C should work. Soldering the new one can be tricky. I'd dispense low temperature solder paste (Sn42/Bi58 from Chipquick) and use the heat gun at 250°C to solder it. Higher temperatures often destroy the LGA packages when doing it at home.

Concerning the SW, it is not enough to simply replace the files you need to understand the changes because there is some code in I used for the G491. I'd recommend checking the code first and if it compiles without errors you can modify the HW.

uecken, 2025-05-10:
@sfe-SparkFro

The surface is wood desk.
The sensor height is almost 1cm.
Will upload the photo.

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
https://photos.google.com/share/AF1QipP5YnHrYbnPP3WSc-DmbEN-X_fp6kc8H916-n2LqNGDcZCMMkvIFrMhvj1UumTEsg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
Now using microPython on M5StickC or RaspiPico W

[Angular and linear sacaler](https://docs.sparkfun.com/SparkFun_Optical_Tracking_Odometry_Sensor/examples/#example-3-calibration) is not set.

uecken, 2025-05-10:
Sorry, IMU calibration code on micropython code by M5StickC seems not to be performed well.
(The reason why I tested it with M5StickC first was because the XRP kit had not arrived yet.

The XRP kit has just arrived, I tried qwiic_otos_ex1_basic_readings.py, but has error.
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

```
>> %Run -c $EDITOR_CONTENT

MPY: soft reboot

Qwiic OTOS Example 1 - Basic Readings

'id' argument required
error: failed to connect to i2c bus
The device isn't connected to the

 system. Please check your connection
```

Then, I fixed the code and tried.
The accuracy is good.
```
Position:
X (Inches): 0.0
Y (Inches): 0.0
Heading (Degrees): -0.005493164

Position:
X (Inches): 0.0
Y (Inches): 0.0
Heading (Degrees): 0.0

Position:
X (Inches): 0.0
Y (Inches): 0.0
Heading (Degrees): -0.005493164

Position:
X (Inches): 0.0
Y (Inches): 0.0
Heading (Degrees): 0.0

Position:
X (Inches): 0.0
Y (Inches): 0.0
Heading (Degrees): 0.0

Position:
X (Inches): 0.0
Y (Inches): 0.0
Heading (Degrees): 0.0

Position:
X (Inches): 0.0
Y (Inches): 0.0
Heading (Degrees): 0.0
```

The code is here.
[qwiic_otos_ex1_basic_readings_2.py.txt](https://github.com/user-attachments/files/20133939/qwiic_otos_ex1_basic_readings_2.py.txt)

sfe-SparkFro, 2025-05-12:
> By the way, does a lower sensor height improve accuracy?

This is not something I've tested much myself. Most of my testing has been at 10mm with the foam surface used in FIRST Tech Challenge. At least on that surface, I do know that changing the mounting height by more than 1mm can start to affect the tracking accuracy, particularly at higher speeds. You could try different mounting heights to see if that makes an improvement for your surface.

> I know that a range of 100mm - 270mm is good.

Correction: 10mm - 27mm

> Created other issue.
> https://github.com/sparkfun/qwiic_otos_py/issues/2

Thanks, we'll take a look at that.

uecken, 2025-05-13:
Thank you for your kind response.

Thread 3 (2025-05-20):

OTOS offset

uecken, 2025-05-20:
I think this explanation and image is wrong.

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

Please tell me correct explanation and image.
I think below orange position and explanation is correct.
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

I want to check this, but my XRP with OTOS is not working now due to https://github.com/sparkfun/qwiic_otos_py/issues/2
I also want to know the XRP body cordination. Forward is +x, Left is +y ?

sfe-SparkFro, 2025-05-20:
Hi there,

The numbers in the text were not intended to relate to the image, but I can see how that is confusing! We'll see if we can make an edit to help clarify.

> I also want to know the XRP body cordination. Forward is +x, Left is +y ?

You can define the XRP's body axes however you like! The images you referenced have +x to the right and +y forward, which is more intuitive for beginners to understand. However if you prefer +x to be forward and +y to the left, you can do that too! You'll just need to change any relevant coordinate definitions.

In the XRP images above, the sensor is mounted about 2 inches to the right and 4 inches forward of the center of the XRP. We mounted it such that +x of the OTOS was pointing to the right, and +y was pointing forward. I've listed the correct offset, depending on your XRP body axis definition:

* XRP body axes: +x right, +y forward
    * OTOS offset: {2, 4, 0}
* XRP body axes: +x forward, +y left
    * OTOS offset: {4, -2, -90}

Hope this helps!

uecken, 2025-05-20:
Thank you, will try it.

sfe-SparkFro, 2025-08-20:
Fixed by #4

Closed 2025-08-20.

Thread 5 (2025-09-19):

I2C Bus Stuck When Slave Holds Clock Low (STM32F401)

ludovicb1239, 2025-09-19:
I2C Bus Stuck When Slave Holds Clock Low (STM32F401)

Description:

I’m encountering intermittent I2C bus lock-ups with the SparkFun Optical Tracking Odometry Sensor when using an STM32F401 as the master. The issue manifests either:

On the very first acknowledge byte of a transaction, or

After several successful transactions, communication randomly fails.

In these cases, the slave appears to hold the SCL line low, causing the master to hang.

Setup:

STM32F401 as I2C master.

Pull-ups are configured correctly.

I2C speed: 100 kHz.

Slave: SparkFun Optical Tracking Odometry Sensor.

Steps to Reproduce:

Initialize I2C communication at 100 kHz.

Attempt to read or write data to the sensor.

Sometimes the transaction works; other times, the slave holds SCL low either immediately on the first ACK or after a few successful reads/writes.

Expected Behavior:

The bus should function reliably at 100 kHz without hanging.

Actual Behavior:

Slave occasionally holds SCL low.

Software attempts to reset the bus (disabling/enabling the peripheral, clearing CR1/CR2, sending STOP conditions) do not release the bus.

Attempts to Resolve:

Verified pull-ups are present and strong.

Tried software resets and STOP generation.

Tried multiple retries from the master.

Request:

Guidance on reliably recovering the bus or avoiding this intermittent SCL hold issue would be greatly appreciated. Is this a known issue with certain slaves, or is additional master-side handling required?

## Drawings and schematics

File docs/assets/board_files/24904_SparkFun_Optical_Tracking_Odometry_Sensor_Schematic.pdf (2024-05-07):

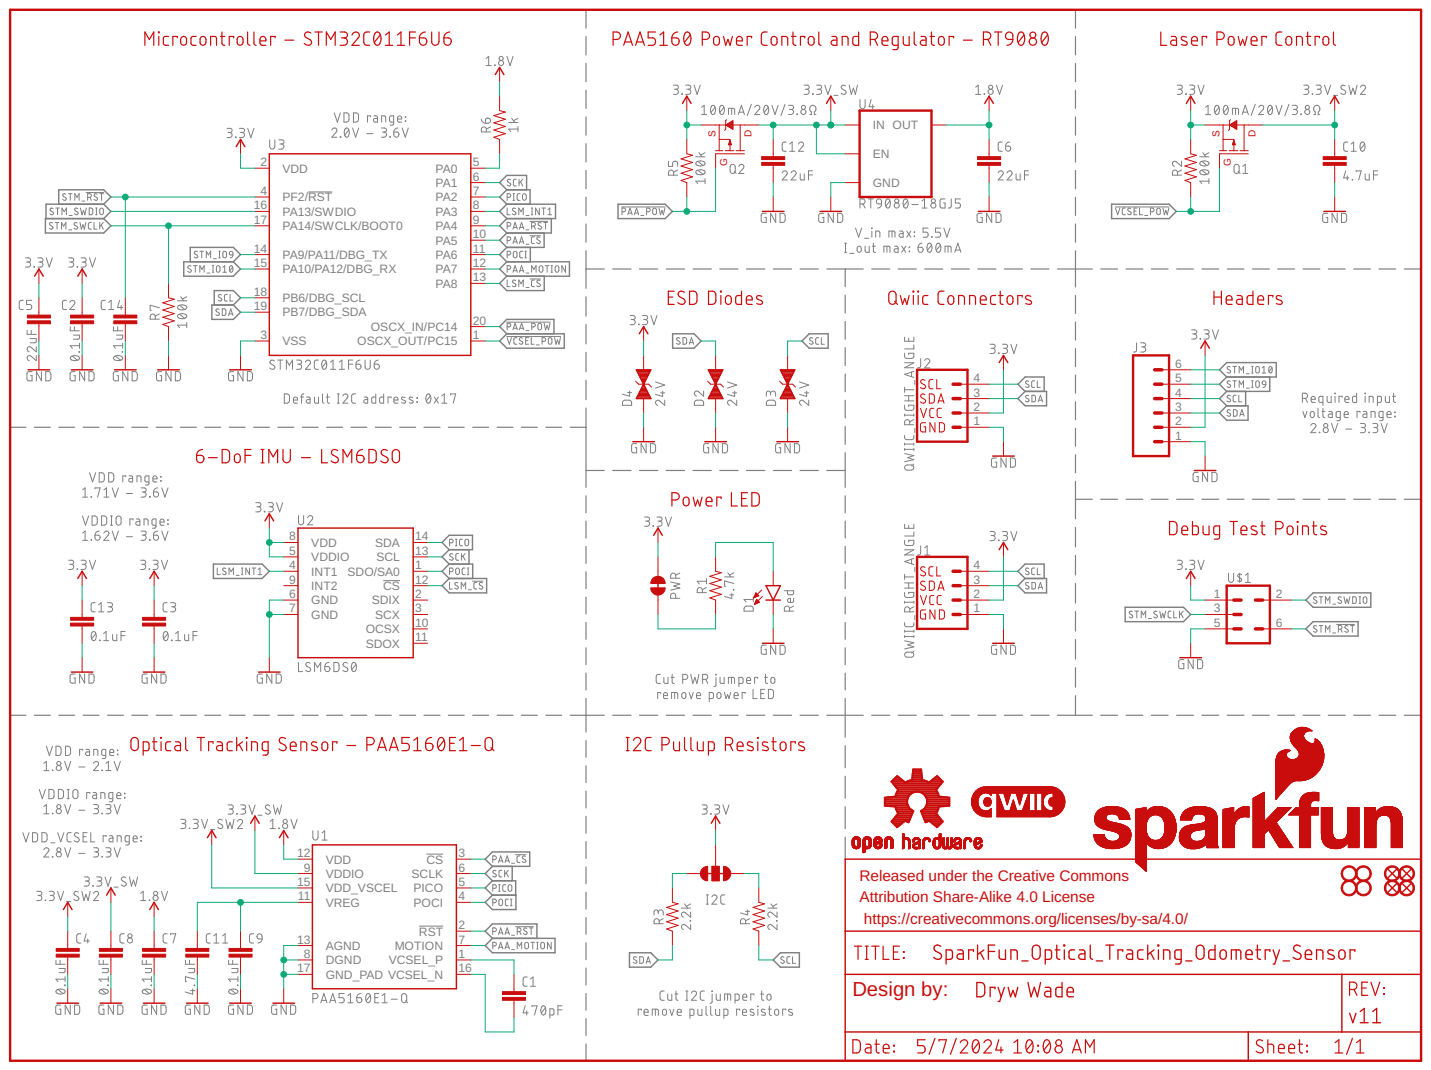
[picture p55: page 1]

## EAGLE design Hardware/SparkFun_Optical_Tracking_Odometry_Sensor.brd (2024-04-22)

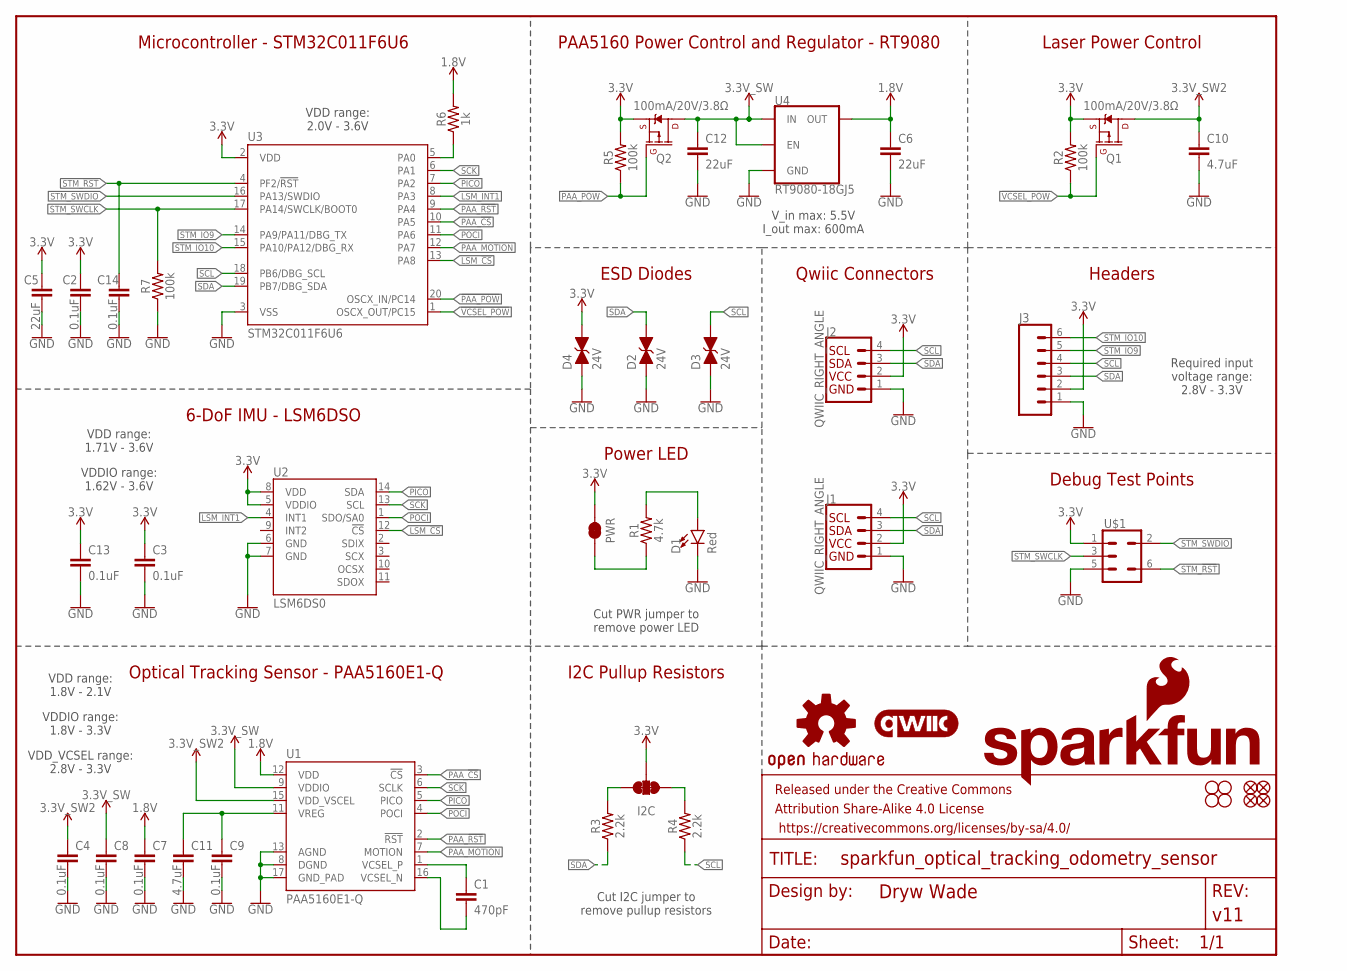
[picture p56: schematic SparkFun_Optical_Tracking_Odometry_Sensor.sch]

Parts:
C1: 470pF; 0603
C2, C3, C4, C7, C8, C9, C13, C14: 0.1uF; 0603
C5, C6, C12: 22uF; 0603
C10, C11: 4.7uF; 0603
D1: Red; LED-0603
D2, D3, D4: 24V; 0603
FD1, FD2, FD3, FD4: FIDUCIAL1X2; FIDUCIAL-1X2
FRAME1: FRAME-LETTER; CREATIVE_COMMONS
H1, H2, H3, H4: STAND-OFF
I2C: JUMPER-SMT_3_2-NC_TRACE_SILK; SMT-JUMPER_3_2-NC_TRACE_SILK
J1, J2: QWIIC_RIGHT_ANGLE; JST04_1MM_RA
J3: CONN_06NO_SILK_NO_POP; 1X06_NO_SILK
LOGO1: OSHW-LOGOS; OSHW-LOGO-S
LOGO2: QWIIC_LOGO_5MM; QWIIC_5MM
LOGO3: SFE_LOGO_NAME_FLAME.1_INCH; SFE_LOGO_NAME_FLAME_.1
PWR: JUMPER-SMT_2_NC_TRACE_SILK; SMT-JUMPER_2_NC_TRACE_SILK
Q1, Q2: 100mA/20V/3.8Ω; SOT-416FL
R1: 4.7k; 0603
R2, R5, R7: 100k; 0603
R3, R4: 2.2k; 0603
R6: 1k; 0603
U1: PAA5160E1-Q
U2: LSM6DS0; LGA14L
U3: STM32C011F6U6
U4: RT9080-18GJ5; SOT23-5
U$1: SWD-5PIN; PAD_05_03X2_TP_NO4

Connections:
1.8V: C6.1, C7.1, R6.2, U1.12 (VDD), U4.5 (OUT)
3.3V: C2.1, C3.1, C5.1, C13.1, D4.2 (C), I2C.2, J1.2, J2.2, J3.2, PWR.2, Q1.2 (S), Q2.2 (S), R2.2, R5.2, U2.5 (VDDIO), U2.8 (VDD), U3.2 (VDD), U$1.1
3.3V_SW: C8.1, C12.1, Q2.3 (D), U1.9 (VDDIO), U4.1 (IN), U4.3 (EN)
3.3V_SW2: C4.1, C10.1, Q1.3 (D), U1.15 (VDD_VSCEL)
!PAA_POW!: Q2.1 (G), R5.1, U3.20 (OSCX_IN/PC14)
!VCSEL_POW!: Q1.1 (G), R2.1, U3.1 (OSCX_OUT/PC15)
GND: C2.2, C3.2, C4.2, C5.2, C6.2, C7.2, C8.2, C9.2, C10.2, C11.2, C12.2, C13.2, C14.2, D1.C, D2.1 (A), D3.1 (A), D4.1 (A), J1.1, J2.1, J3.1, R7.1, U1.8 (DGND), U1.13 (AGND), U1.17 (GND_PAD), U2.6 (GND), U2.7 (GND), U3.3 (VSS), U4.2 (GND), U$1.5
LSM_!CS!: U2.12 (!CS!), U3.13 (PA8)
LSM_INT1: U2.4 (INT1), U3.8 (PA3)
unnamed: PWR.1, R1.1
unnamed: D1.A, R1.2
unnamed: C1.1, U1.1 (VCSEL_P)
unnamed: C1.2, U1.16 (VCSEL_N)
unnamed: I2C.3, R3.2
unnamed: I2C.1, R4.2
unnamed: C9.1, C11.1, U1.11 (VREG)
unnamed: R6.1, U3.5 (PA0)
PAA_!CS!: U1.3 (!CS!), U3.10 (PA5)
PAA_!RST!: U1.2 (!RST!), U3.9 (PA4)
PAA_MOTION: U1.7 (MOTION), U3.12 (PA7)
PICO: U1.5 (PICO), U2.14 (SDA), U3.7 (PA2)
POCI: U1.4 (POCI), U2.1 (SDO/SA0), U3.11 (PA6)
SCK: U1.6 (SCLK), U2.13 (SCL), U3.6 (PA1)
SCL: D3.2 (C), J1.4, J2.4, J3.4, R4.1, U3.18 (PB6/DBG_SCL)
SDA: D2.2 (C), J1.3, J2.3, J3.3, R3.1, U3.19 (PB7/DBG_SDA)
STM_!RST!: C14.1, U3.4 (PF2/!RST!), U$1.6
STM_IO9: J3.5, U3.14 (PA9/PA11/DBG_TX)
STM_IO10: J3.6, U3.15 (PA10/PA12/DBG_RX)
STM_SWCLK: R7.2, U3.17 (PA14/SWCLK/BOOT0), U$1.3
STM_SWDIO: U3.16 (PA13/SWDIO), U$1.2

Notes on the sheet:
Power LED
Optical Tracking Sensor - PAA5160E1-Q
6-DoF IMU - LSM6DSO
Microcontroller - STM32C011F6U6
PAA5160 Power Control and Regulator - RT9080
Debug Test Points
Qwiic Connectors
I2C Pullup Resistors
Cut I2C jumper to remove pullup resistors
Cut PWR jumper to remove power LED
Headers
ESD Diodes
Laser Power Control
V_in max: 5.5V I_out max: 600mA
VDD range: 2.0V - 3.6V
VDD range: 1.71V - 3.6V
VDDIO range: 1.62V - 3.6V
VDD range: 1.8V - 2.1V
VDDIO range: 1.8V - 3.3V
VDD_VCSEL range: 2.8V - 3.3V
Required input voltage range: 2.8V - 3.3V

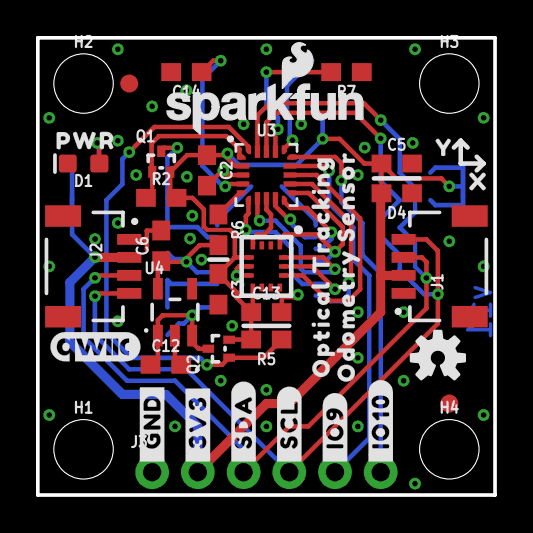
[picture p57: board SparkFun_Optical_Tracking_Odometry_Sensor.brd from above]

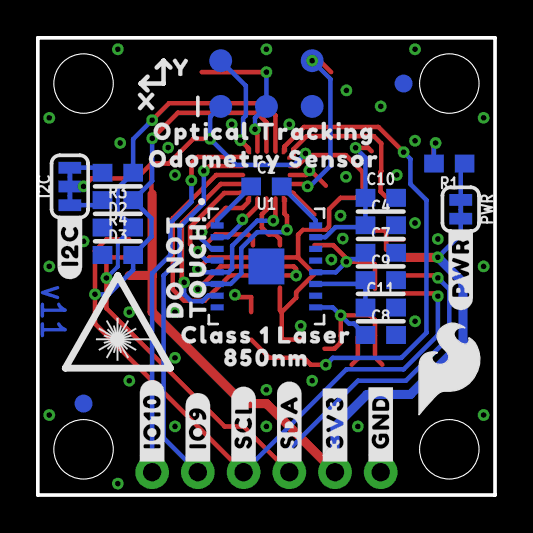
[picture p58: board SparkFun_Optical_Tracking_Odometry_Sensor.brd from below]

Board: 2 copper layers, 25.4 x 25.4 mm, 78 parts (35 on the bottom side), 30 nets.

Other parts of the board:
U$2, U$8: #_GND#0
U$3, U$9: #_3V3#0
U$4, U$10: #_SDA#0
U$5, U$11: #_SCL#0
U$6: CLASS_1_LASER0
U$7, U$23: #_IO10#0
U$12, U$32: #_IO9#0
U$14, U$16: OPTICAL_TRACKING0
U$15, U$17: ODOMETRY_SENSOR0
U$18, U$30: X0
U$20: #PWR#0
U$21: TOUCH##0
U$22: DO_NOT0
U$24: SFE_LOGO_FLAME_.2
U$25: PWR0
U$26: #I2C#0
U$27: ORDERING_INSTRUCTIONS
U$28: 850NM0
U$29, U$31: Y0

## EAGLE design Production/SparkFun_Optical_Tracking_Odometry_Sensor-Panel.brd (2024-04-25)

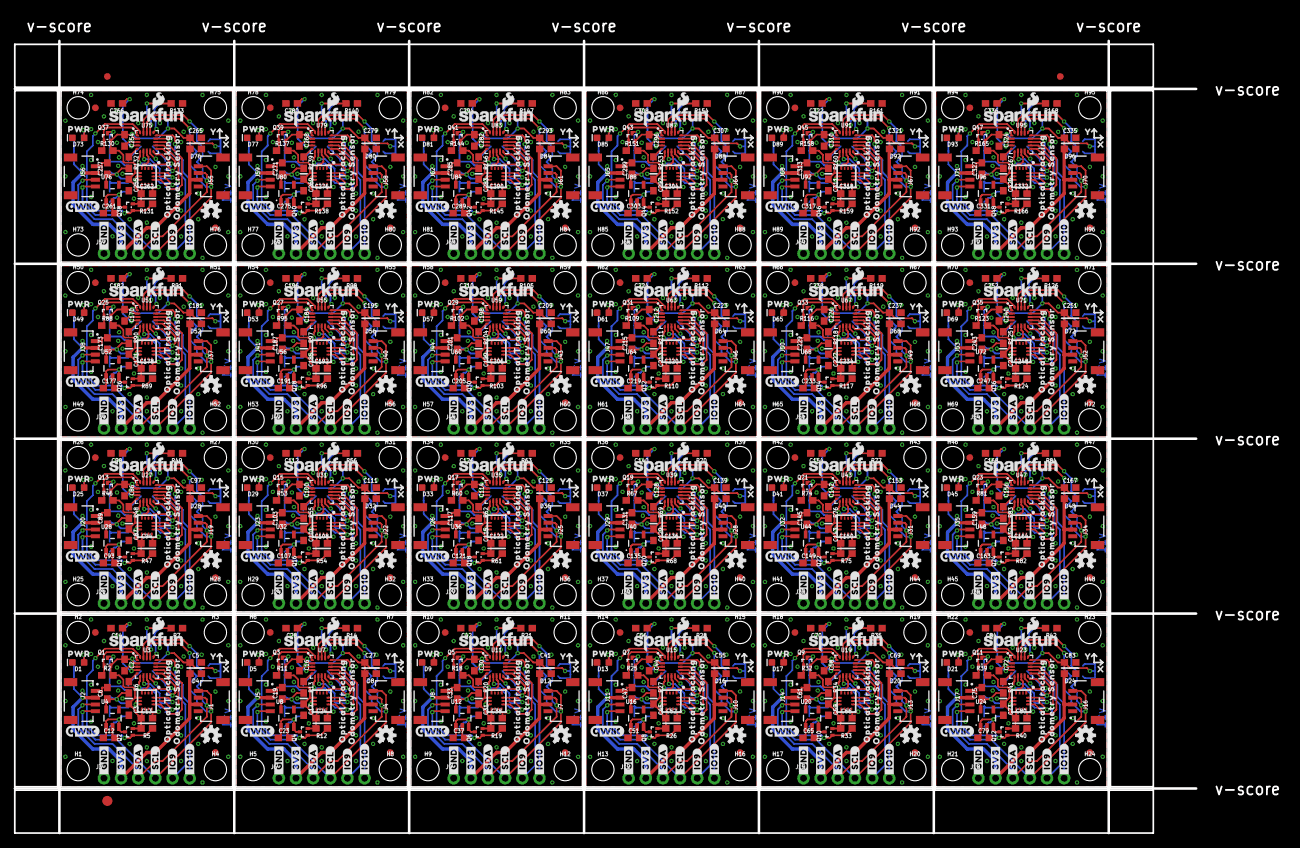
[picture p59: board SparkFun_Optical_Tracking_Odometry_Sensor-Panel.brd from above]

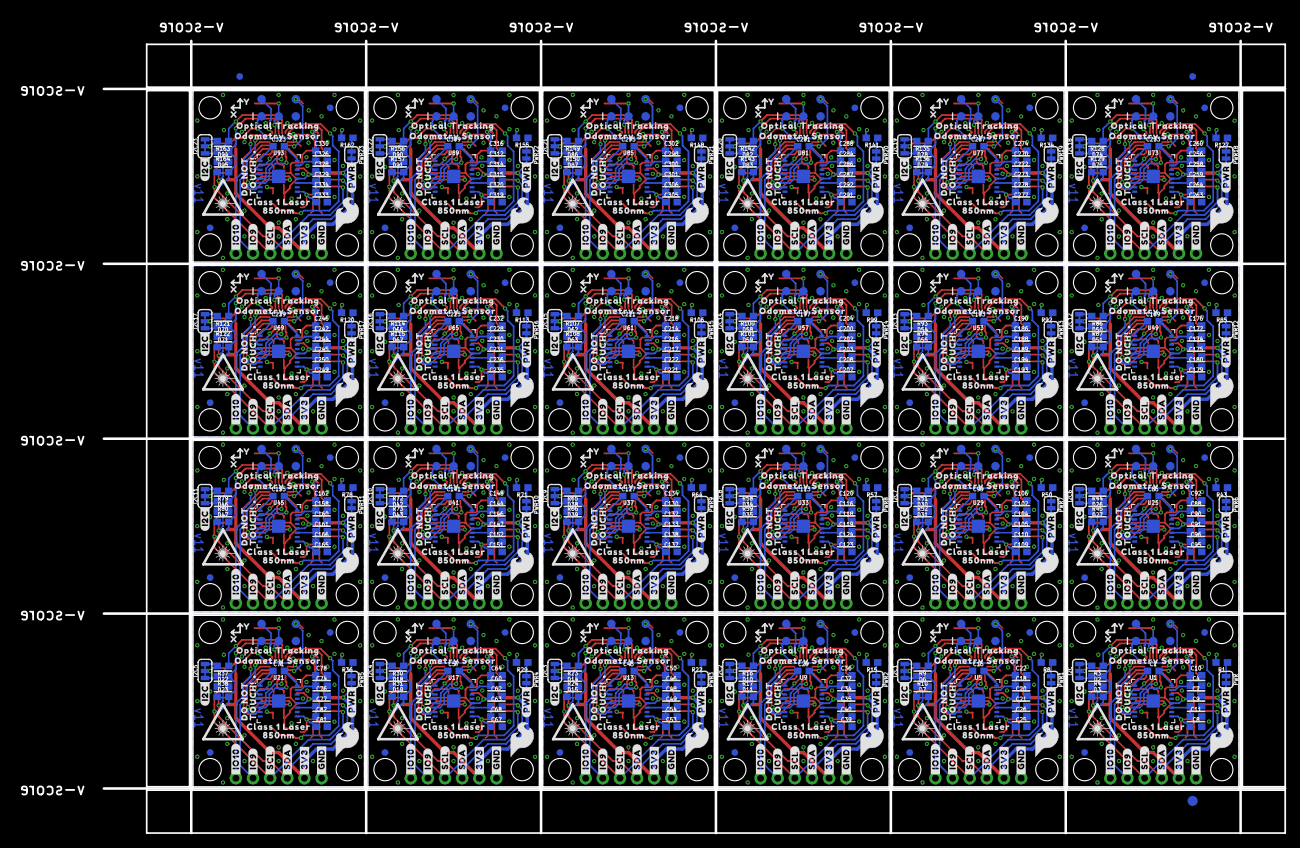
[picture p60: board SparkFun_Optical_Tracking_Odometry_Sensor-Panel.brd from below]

Board: 2 copper layers, 175.0 x 117.3 mm, 1830 parts (843 on the bottom side), 720 nets.

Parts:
C1, C15, C29, C43, C57, C71, C85, C99, C113, C127, C141, C155, C169, C183, C197, C211, C225, C239, C253, C267, C281, C295, C309, C323: 470pF; 0603
C2, C3, C4, C7, C8, C9, C13, C14, C16, C17, C18, C20, C21, C24, C25, C28, C30, C31, C32, C34, C35, C38, C39, C42, C44, C45, C46, C48, C49, C52, C53, C56, C58, C59, C60, C62, C63, C66, C67, C70, C72, C73, C74, C76, C77, C80, C81, C84, C86, C87, C88, C90, C91, C94, C95, C98, C100, C101, C102, C104, C105, C108, C109, C112, C114, C115, C116, C118, C119, C122, C123, C126, C128, C129, C130, C132, C133, C136, C137, C140, C142, C143, C144, C146, C147, C150, C151, C154, C156, C157, C158, C160, C161, C164, C165, C168, C170, C171, C172, C174, C175, C178, C179, C182, C184, C185, C186, C188, C189, C192, C193, C196, C198, C199, C200, C202, C203, C206, C207, C210, C212, C213, C214, C216, C217, C220, C221, C224, C226, C227, C228, C230, C231, C234, C235, C238, C240, C241, C242, C244, C245, C248, C249, C252, C254, C255, C256, C258, C259, C262, C263, C266, C268, C269, C270, C272, C273, C276, C277, C280, C282, C283, C284, C286, C287, C290, C291, C294, C296, C297, C298, C300, C301, C304, C305, C308, C310, C311, C312, C314, C315, C318, C319, C322, C324, C325, C326, C328, C329, C332, C333, C336: 0.1uF; 0603
C5, C6, C12, C19, C23, C27, C33, C37, C41, C47, C51, C55, C61, C65, C69, C75, C79, C83, C89, C93, C97, C103, C107, C111, C117, C121, C125, C131, C135, C139, C145, C149, C153, C159, C163, C167, C173, C177, C181, C187, C191, C195, C201, C205, C209, C215, C219, C223, C229, C233, C237, C243, C247, C251, C257, C261, C265, C271, C275, C279, C285, C289, C293, C299, C303, C307, C313, C317, C321, C327, C331, C335: 22uF; 0603
C10, C11, C22, C26, C36, C40, C50, C54, C64, C68, C78, C82, C92, C96, C106, C110, C120, C124, C134, C138, C148, C152, C162, C166, C176, C180, C190, C194, C204, C208, C218, C222, C232, C236, C246, C250, C260, C264, C274, C278, C288, C292, C302, C306, C316, C320, C330, C334: 4.7uF; 0603
D1, D5, D9, D13, D17, D21, D25, D29, D33, D37, D41, D45, D49, D53, D57, D61, D65, D69, D73, D77, D81, D85, D89, D93: Red; LED-0603
D2, D3, D4, D6, D7, D8, D10, D11, D12, D14, D15, D16, D18, D19, D20, D22, D23, D24, D26, D27, D28, D30, D31, D32, D34, D35, D36, D38, D39, D40, D42, D43, D44, D46, D47, D48, D50, D51, D52, D54, D55, D56, D58, D59, D60, D62, D63, D64, D66, D67, D68, D70, D71, D72, D74, D75, D76, D78, D79, D80, D82, D83, D84, D86, D87, D88, D90, D91, D92, D94, D95, D96: 24V; 0603
E$1, E$2, E$3, E$4: FIDUCIAL-1X2
E$5, E$6: FIDUCIAL-1.5X3
FD1, FD2, FD3, FD4, FD5, FD6, FD7, FD8, FD9, FD10, FD11, FD12, FD13, FD14, FD15, FD16, FD17, FD18, FD19, FD20, FD21, FD22, FD23, FD24, FD25, FD26, FD27, FD28, FD29, FD30, FD31, FD32, FD33, FD34, FD35, FD36, FD37, FD38, FD39, FD40, FD41, FD42, FD43, FD44, FD45, FD46, FD47, FD48, FD49, FD50, FD51, FD52, FD53, FD54, FD55, FD56, FD57, FD58, FD59, FD60, FD61, FD62, FD63, FD64, FD65, FD66, FD67, FD68, FD69, FD70, FD71, FD72, FD73, FD74, FD75, FD76, FD77, FD78, FD79, FD80, FD81, FD82, FD83, FD84, FD85, FD86, FD87, FD88, FD89, FD90, FD91, FD92, FD93, FD94, FD95, FD96: FIDUCIAL1X2; FIDUCIAL-1X2
H1, H2, H3, H4, H5, H6, H7, H8, H9, H10, H11, H12, H13, H14, H15, H16, H17, H18, H19, H20, H21, H22, H23, H24, H25, H26, H27, H28, H29, H30, H31, H32, H33, H34, H35, H36, H37, H38, H39, H40, H41, H42, H43, H44, H45, H46, H47, H48, H49, H50, H51, H52, H53, H54, H55, H56, H57, H58, H59, H60, H61, H62, H63, H64, H65, H66, H67, H68, H69, H70, H71, H72, H73, H74, H75, H76, H77, H78, H79, H80, H81, H82, H83, H84, H85, H86, H87, H88, H89, H90, H91, H92, H93, H94, H95, H96: STAND-OFF
I2C, I2C1, I2C2, I2C3, I2C4, I2C5, I2C6, I2C7, I2C8, I2C9, I2C10, I2C11, I2C12, I2C13, I2C14, I2C15, I2C16, I2C17, I2C18, I2C19, I2C20, I2C21, I2C22, I2C23: JUMPER-SMT_3_2-NC_TRACE_SILK; SMT-JUMPER_3_2-NC_TRACE_SILK
J1, J2, J4, J5, J7, J8, J10, J11, J13, J14, J16, J17, J19, J20, J22, J23, J25, J26, J28, J29, J31, J32, J34, J35, J37, J38, J40, J41, J43, J44, J46, J47, J49, J50, J52, J53, J55, J56, J58, J59, J61, J62, J64, J65, J67, J68, J70, J71: QWIIC_RIGHT_ANGLE; JST04_1MM_RA
J3, J6, J9, J12, J15, J18, J21, J24, J27, J30, J33, J36, J39, J42, J45, J48, J51, J54, J57, J60, J63, J66, J69, J72: 1X06_NO_SILK
LOGO1, LOGO4, LOGO7, LOGO10, LOGO13, LOGO16, LOGO19, LOGO22, LOGO25, LOGO28, LOGO31, LOGO34, LOGO37, LOGO40, LOGO43, LOGO46, LOGO49, LOGO52, LOGO55, LOGO58, LOGO61, LOGO64, LOGO67, LOGO70: OSHW-LOGOS; OSHW-LOGO-S
LOGO2, LOGO5, LOGO8, LOGO11, LOGO14, LOGO17, LOGO20, LOGO23, LOGO26, LOGO29, LOGO32, LOGO35, LOGO38, LOGO41, LOGO44, LOGO47, LOGO50, LOGO53, LOGO56, LOGO59, LOGO62, LOGO65, LOGO68, LOGO71: QWIIC_LOGO_5MM; QWIIC_5MM
LOGO3, LOGO6, LOGO9, LOGO12, LOGO15, LOGO18, LOGO21, LOGO24, LOGO27, LOGO30, LOGO33, LOGO36, LOGO39, LOGO42, LOGO45, LOGO48, LOGO51, LOGO54, LOGO57, LOGO60, LOGO63, LOGO66, LOGO69, LOGO72: SFE_LOGO_NAME_FLAME.1_INCH; SFE_LOGO_NAME_FLAME_.1
PWR, PWR1, PWR2, PWR3, PWR4, PWR5, PWR6, PWR7, PWR8, PWR9, PWR10, PWR11, PWR12, PWR13, PWR14, PWR15, PWR16, PWR17, PWR18, PWR19, PWR20, PWR21, PWR22, PWR23: JUMPER-SMT_2_NC_TRACE_SILK; SMT-JUMPER_2_NC_TRACE_SILK
Q1, Q2, Q3, Q4, Q5, Q6, Q7, Q8, Q9, Q10, Q11, Q12, Q13, Q14, Q15, Q16, Q17, Q18, Q19, Q20, Q21, Q22, Q23, Q24, Q25, Q26, Q27, Q28, Q29, Q30, Q31, Q32, Q33, Q34, Q35, Q36, Q37, Q38, Q39, Q40, Q41, Q42, Q43, Q44, Q45, Q46, Q47, Q48: 100mA/20V/3.8Ω; SOT-416FL
R1, R8, R15, R22, R29, R36, R43, R50, R57, R64, R71, R78, R85, R92, R99, R106, R113, R120, R127, R134, R141, R148, R155, R162: 4.7k; 0603
R2, R5, R7, R11, R12, R14, R18, R19, R21, R25, R26, R28, R32, R33, R35, R39, R40, R42, R46, R47, R49, R53, R54, R56, R60, R61, R63, R67, R68, R70, R74, R75, R77, R81, R82, R84, R88, R89, R91, R95, R96, R98, R102, R103, R105, R109, R110, R112, R116, R117, R119, R123, R124, R126, R130, R131, R133, R137, R138, R140, R144, R145, R147, R151, R152, R154, R158, R159, R161, R165, R166, R168: 100k; 0603
R3, R4, R9, R10, R16, R17, R23, R24, R30, R31, R37, R38, R44, R45, R51, R52, R58, R59, R65, R66, R72, R73, R79, R80, R86, R87, R93, R94, R100, R101, R107, R108, R114, R115, R121, R122, R128, R129, R135, R136, R142, R143, R149, R150, R156, R157, R163, R164: 2.2k; 0603
R6, R13, R20, R27, R34, R41, R48, R55, R62, R69, R76, R83, R90, R97, R104, R111, R118, R125, R132, R139, R146, R153, R160, R167: 1k; 0603
U1, U5, U9, U13, U17, U21, U25, U29, U33, U37, U41, U45, U49, U53, U57, U61, U65, U69, U73, U77, U81, U85, U89, U93: PAA5160E1-Q
U2, U6, U10, U14, U18, U22, U26, U30, U34, U38, U42, U46, U50, U54, U58, U62, U66, U70, U74, U78, U82, U86, U90, U94: LSM6DS0; LGA14L
U3, U7, U11, U15, U19, U23, U27, U31, U35, U39, U43, U47, U51, U55, U59, U63, U67, U71, U75, U79, U83, U87, U91, U95: STM32C011F6U6
U4, U8, U12, U16, U20, U24, U28, U32, U36, U40, U44, U48, U52, U56, U60, U64, U68, U72, U76, U80, U84, U88, U92, U96: RT9080-18GJ5; SOT23-5
U$1, U$13, U$59, U$88, U$117, U$146, U$175, U$204, U$233, U$262, U$291, U$320, U$349, U$378, U$407, U$436, U$465, U$494, U$523, U$552, U$581, U$610, U$639, U$668: PAD_05_03X2_TP_NO4
U$2, U$8, U$19, U$35, U$60, U$64, U$89, U$93, U$118, U$122, U$147, U$151, U$176, U$180, U$205, U$209, U$234, U$238, U$263, U$267, U$292, U$296, U$321, U$325, U$350, U$354, U$379, U$383, U$408, U$412, U$437, U$441, U$466, U$470, U$495, U$499, U$524, U$528, U$553, U$557, U$582, U$586, U$611, U$615, U$640, U$644, U$669, U$673: #_GND#0
U$3, U$9, U$27, U$36, U$61, U$65, U$90, U$94, U$119, U$123, U$148, U$152, U$177, U$181, U$206, U$210, U$235, U$239, U$264, U$268, U$293, U$297, U$322, U$326, U$351, U$355, U$380, U$384, U$409, U$413, U$438, U$442, U$467, U$471, U$496, U$500, U$525, U$529, U$554, U$558, U$583, U$587, U$612, U$616, U$641, U$645, U$670, U$674: #_3V3#0
U$4, U$10, U$33, U$37, U$62, U$66, U$91, U$95, U$120, U$124, U$149, U$153, U$178, U$182, U$207, U$211, U$236, U$240, U$265, U$269, U$294, U$298, U$323, U$327, U$352, U$356, U$381, U$385, U$410, U$414, U$439, U$443, U$468, U$472, U$497, U$501, U$526, U$530, U$555, U$559, U$584, U$588, U$613, U$617, U$642, U$646, U$671, U$675: #_SDA#0
U$5, U$11, U$34, U$38, U$63, U$67, U$92, U$96, U$121, U$125, U$150, U$154, U$179, U$183, U$208, U$212, U$237, U$241, U$266, U$270, U$295, U$299, U$324, U$328, U$353, U$357, U$382, U$386, U$411, U$415, U$440, U$444, U$469, U$473, U$498, U$502, U$527, U$531, U$556, U$560, U$585, U$589, U$614, U$618, U$643, U$647, U$672, U$676: #_SCL#0
U$6, U$54, U$83, U$112, U$141, U$170, U$199, U$228, U$257, U$286, U$315, U$344, U$373, U$402, U$431, U$460, U$489, U$518, U$547, U$576, U$605, U$634, U$663, U$692: CLASS_1_LASER0
U$7, U$23, U$56, U$57, U$85, U$86, U$114, U$115, U$143, U$144, U$172, U$173, U$201, U$202, U$230, U$231, U$259, U$260, U$288, U$289, U$317, U$318, U$346, U$347, U$375, U$376, U$404, U$405, U$433, U$434, U$462, U$463, U$491, U$492, U$520, U$521, U$549, U$550, U$578, U$579, U$607, U$608, U$636, U$637, U$665, U$666, U$694, U$695: #_IO10#0
U$12, U$32, U$55, U$58, U$84, U$87, U$113, U$116, U$142, U$145, U$171, U$174, U$200, U$203, U$229, U$232, U$258, U$261, U$287, U$290, U$316, U$319, U$345, U$348, U$374, U$377, U$403, U$406, U$432, U$435, U$461, U$464, U$490, U$493, U$519, U$522, U$548, U$551, U$577, U$580, U$606, U$609, U$635, U$638, U$664, U$667, U$693, U$696: #_IO9#0
U$14, U$16, U$39, U$41, U$68, U$70, U$97, U$99, U$126, U$128, U$155, U$157, U$184, U$186, U$213, U$215, U$242, U$244, U$271, U$273, U$300, U$302, U$329, U$331, U$358, U$360, U$387, U$389, U$416, U$418, U$445, U$447, U$474, U$476, U$503, U$505, U$532, U$534, U$561, U$563, U$590, U$592, U$619, U$621, U$648, U$650, U$677, U$679: OPTICAL_TRACKING0
U$15, U$17, U$40, U$42, U$69, U$71, U$98, U$100, U$127, U$129, U$156, U$158, U$185, U$187, U$214, U$216, U$243, U$245, U$272, U$274, U$301, U$303, U$330, U$332, U$359, U$361, U$388, U$390, U$417, U$419, U$446, U$448, U$475, U$477, U$504, U$506, U$533, U$535, U$562, U$564, U$591, U$593, U$620, U$622, U$649, U$651, U$678, U$680: ODOMETRY_SENSOR0
U$18, U$30, U$50, U$52, U$79, U$81, U$108, U$110, U$137, U$139, U$166, U$168, U$195, U$197, U$224, U$226, U$253, U$255, U$282, U$284, U$311, U$313, U$340, U$342, U$369, U$371, U$398, U$400, U$427, U$429, U$456, U$458, U$485, U$487, U$514, U$516, U$543, U$545, U$572, U$574, U$601, U$603, U$630, U$632, U$659, U$661, U$688, U$690: X0
U$20, U$43, U$72, U$101, U$130, U$159, U$188, U$217, U$246, U$275, U$304, U$333, U$362, U$391, U$420, U$449, U$478, U$507, U$536, U$565, U$594, U$623, U$652, U$681: #PWR#0
U$21, U$44, U$73, U$102, U$131, U$160, U$189, U$218, U$247, U$276, U$305, U$334, U$363, U$392, U$421, U$450, U$479, U$508, U$537, U$566, U$595, U$624, U$653, U$682: TOUCH##0
U$22, U$45, U$74, U$103, U$132, U$161, U$190, U$219, U$248, U$277, U$306, U$335, U$364, U$393, U$422, U$451, U$480, U$509, U$538, U$567, U$596, U$625, U$654, U$683: DO_NOT0
U$24, U$46, U$75, U$104, U$133, U$162, U$191, U$220, U$249, U$278, U$307, U$336, U$365, U$394, U$423, U$452, U$481, U$510, U$539, U$568, U$597, U$626, U$655, U$684: SFE_LOGO_FLAME_.2
U$25, U$47, U$76, U$105, U$134, U$163, U$192, U$221, U$250, U$279, U$308, U$337, U$366, U$395, U$424, U$453, U$482, U$511, U$540, U$569, U$598, U$627, U$656, U$685: PWR0
U$26, U$48, U$77, U$106, U$135, U$164, U$193, U$222, U$251, U$280, U$309, U$338, U$367, U$396, U$425, U$454, U$483, U$512, U$541, U$570, U$599, U$628, U$657, U$686: #I2C#0
U$28, U$49, U$78, U$107, U$136, U$165, U$194, U$223, U$252, U$281, U$310, U$339, U$368, U$397, U$426, U$455, U$484, U$513, U$542, U$571, U$600, U$629, U$658, U$687: 850NM0
U$29, U$31, U$51, U$53, U$80, U$82, U$109, U$111, U$138, U$140, U$167, U$169, U$196, U$198, U$225, U$227, U$254, U$256, U$283, U$285, U$312, U$314, U$341, U$343, U$370, U$372, U$399, U$401, U$428, U$430, U$457, U$459, U$486, U$488, U$515, U$517, U$544, U$546, U$573, U$575, U$602, U$604, U$631, U$633, U$660, U$662, U$689, U$691: Y0

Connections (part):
1.8V: C6.1, C7.1, R6.2, U1.12, U4.5
1.8V1: C19.1, C20.1, R13.2, U5.12, U8.5
1.8V2: C33.1, C34.1, R20.2, U9.12, U12.5
1.8V3: C47.1, C48.1, R27.2, U13.12, U16.5
1.8V4: C61.1, C62.1, R34.2, U17.12, U20.5
1.8V5: C75.1, C76.1, R41.2, U21.12, U24.5
1.8V6: C89.1, C90.1, R48.2, U25.12, U28.5
1.8V7: C103.1, C104.1, R55.2, U29.12, U32.5
1.8V8: C117.1, C118.1, R62.2, U33.12, U36.5
1.8V9: C131.1, C132.1, R69.2, U37.12, U40.5
1.8V10: C145.1, C146.1, R76.2, U41.12, U44.5
1.8V11: C159.1, C160.1, R83.2, U45.12, U48.5
1.8V12: C173.1, C174.1, R90.2, U49.12, U52.5
1.8V13: C187.1, C188.1, R97.2, U53.12, U56.5
1.8V14: C201.1, C202.1, R104.2, U57.12, U60.5
1.8V15: C215.1, C216.1, R111.2, U61.12, U64.5
1.8V16: C229.1, C230.1, R118.2, U65.12, U68.5
1.8V17: C243.1, C244.1, R125.2, U69.12, U72.5
1.8V18: C257.1, C258.1, R132.2, U73.12, U76.5
1.8V19: C271.1, C272.1, R139.2, U77.12, U80.5
1.8V20: C285.1, C286.1, R146.2, U81.12, U84.5
1.8V21: C299.1, C300.1, R153.2, U85.12, U88.5
1.8V22: C313.1, C314.1, R160.2, U89.12, U92.5
1.8V23: C327.1, C328.1, R167.2, U93.12, U96.5
3.3V: C2.1, C3.1, C5.1, C13.1, D4.2, I2C.2, J1.2, J2.2, J3.2, PWR.2, Q1.2, Q2.2, R2.2, R5.2, U2.5, U2.8, U3.2, U$1.1
3.3V1: C16.1, C17.1, C24.1, C27.1, D8.2, I2C1.2, J4.2, J5.2, J6.2, PWR1.2, Q3.2, Q4.2, R11.2, R12.2, U6.5, U6.8, U7.2, U$13.1
3.3V2: C30.1, C31.1, C38.1, C41.1, D12.2, I2C2.2, J7.2, J8.2, J9.2, PWR2.2, Q5.2, Q6.2, R18.2, R19.2, U10.5, U10.8, U11.2, U$59.1
3.3V3: C44.1, C45.1, C52.1, C55.1, D16.2, I2C3.2, J10.2, J11.2, J12.2, PWR3.2, Q7.2, Q8.2, R25.2, R26.2, U14.5, U14.8, U15.2, U$88.1
3.3V4: C58.1, C59.1, C66.1, C69.1, D20.2, I2C4.2, J13.2, J14.2, J15.2, PWR4.2, Q9.2, Q10.2, R32.2, R33.2, U18.5, U18.8, U19.2, U$117.1
3.3V5: C72.1, C73.1, C80.1, C83.1, D24.2, I2C5.2, J16.2, J17.2, J18.2, PWR5.2, Q11.2, Q12.2, R39.2, R40.2, U22.5, U22.8, U23.2, U$146.1
3.3V6: C86.1, C87.1, C94.1, C97.1, D28.2, I2C6.2, J19.2, J20.2, J21.2, PWR6.2, Q13.2, Q14.2, R46.2, R47.2, U26.5, U26.8, U27.2, U$175.1
3.3V7: C100.1, C101.1, C108.1, C111.1, D32.2, I2C7.2, J22.2, J23.2, J24.2, PWR7.2, Q15.2, Q16.2, R53.2, R54.2, U30.5, U30.8, U31.2, U$204.1
3.3V8: C114.1, C115.1, C122.1, C125.1, D36.2, I2C8.2, J25.2, J26.2, J27.2, PWR8.2, Q17.2, Q18.2, R60.2, R61.2, U34.5, U34.8, U35.2, U$233.1
3.3V9: C128.1, C129.1, C136.1, C139.1, D40.2, I2C9.2, J28.2, J29.2, J30.2, PWR9.2, Q19.2, Q20.2, R67.2, R68.2, U38.5, U38.8, U39.2, U$262.1
3.3V10: C142.1, C143.1, C150.1, C153.1, D44.2, I2C10.2, J31.2, J32.2, J33.2, PWR10.2, Q21.2, Q22.2, R74.2, R75.2, U42.5, U42.8, U43.2, U$291.1
3.3V11: C156.1, C157.1, C164.1, C167.1, D48.2, I2C11.2, J34.2, J35.2, J36.2, PWR11.2, Q23.2, Q24.2, R81.2, R82.2, U46.5, U46.8, U47.2, U$320.1
3.3V12: C170.1, C171.1, C178.1, C181.1, D52.2, I2C12.2, J37.2, J38.2, J39.2, PWR12.2, Q25.2, Q26.2, R88.2, R89.2, U50.5, U50.8, U51.2, U$349.1
3.3V13: C184.1, C185.1, C192.1, C195.1, D56.2, I2C13.2, J40.2, J41.2, J42.2, PWR13.2, Q27.2, Q28.2, R95.2, R96.2, U54.5, U54.8, U55.2, U$378.1
3.3V14: C198.1, C199.1, C206.1, C209.1, D60.2, I2C14.2, J43.2, J44.2, J45.2, PWR14.2, Q29.2, Q30.2, R102.2, R103.2, U58.5, U58.8, U59.2, U$407.1
3.3V15: C212.1, C213.1, C220.1, C223.1, D64.2, I2C15.2, J46.2, J47.2, J48.2, PWR15.2, Q31.2, Q32.2, R109.2, R110.2, U62.5, U62.8, U63.2, U$436.1
3.3V16: C226.1, C227.1, C234.1, C237.1, D68.2, I2C16.2, J49.2, J50.2, J51.2, PWR16.2, Q33.2, Q34.2, R116.2, R117.2, U66.5, U66.8, U67.2, U$465.1
3.3V17: C240.1, C241.1, C248.1, C251.1, D72.2, I2C17.2, J52.2, J53.2, J54.2, PWR17.2, Q35.2, Q36.2, R123.2, R124.2, U70.5, U70.8, U71.2, U$494.1
3.3V18: C254.1, C255.1, C262.1, C265.1, D76.2, I2C18.2, J55.2, J56.2, J57.2, PWR18.2, Q37.2, Q38.2, R130.2, R131.2, U74.5, U74.8, U75.2, U$523.1
3.3V19: C268.1, C269.1, C276.1, C279.1, D80.2, I2C19.2, J58.2, J59.2, J60.2, PWR19.2, Q39.2, Q40.2, R137.2, R138.2, U78.5, U78.8, U79.2, U$552.1
3.3V20: C282.1, C283.1, C290.1, C293.1, D84.2, I2C20.2, J61.2, J62.2, J63.2, PWR20.2, Q41.2, Q42.2, R144.2, R145.2, U82.5, U82.8, U83.2, U$581.1
3.3V21: C296.1, C297.1, C304.1, C307.1, D88.2, I2C21.2, J64.2, J65.2, J66.2, PWR21.2, Q43.2, Q44.2, R151.2, R152.2, U86.5, U86.8, U87.2, U$610.1
3.3V22: C310.1, C311.1, C318.1, C321.1, D92.2, I2C22.2, J67.2, J68.2, J69.2, PWR22.2, Q45.2, Q46.2, R158.2, R159.2, U90.5, U90.8, U91.2, U$639.1
3.3V23: C324.1, C325.1, C332.1, C335.1, D96.2, I2C23.2, J70.2, J71.2, J72.2, PWR23.2, Q47.2, Q48.2, R165.2, R166.2, U94.5, U94.8, U95.2, U$668.1
3.3V_SW: C8.1, C12.1, Q2.3, U1.9, U4.1, U4.3
3.3V_SW1: C18.1, C22.1, Q3.3, U5.15
3.3V_SW2: C4.1, C10.1, Q1.3, U1.15
3.3V_SW3: C23.1, C25.1, Q4.3, U5.9, U8.1, U8.3
3.3V_SW4: C32.1, C36.1, Q5.3, U9.15
3.3V_SW5: C37.1, C39.1, Q6.3, U9.9, U12.1, U12.3
3.3V_SW6: C46.1, C50.1, Q7.3, U13.15
3.3V_SW7: C51.1, C53.1, Q8.3, U13.9, U16.1, U16.3
3.3V_SW8: C60.1, C64.1, Q9.3, U17.15
3.3V_SW9: C65.1, C67.1, Q10.3, U17.9, U20.1, U20.3
3.3V_SW10: C74.1, C78.1, Q11.3, U21.15
3.3V_SW11: C79.1, C81.1, Q12.3, U21.9, U24.1, U24.3
3.3V_SW12: C88.1, C92.1, Q13.3, U25.15
3.3V_SW13: C93.1, C95.1, Q14.3, U25.9, U28.1, U28.3
3.3V_SW14: C102.1, C106.1, Q15.3, U29.15
3.3V_SW15: C107.1, C109.1, Q16.3, U29.9, U32.1, U32.3
3.3V_SW16: C116.1, C120.1, Q17.3, U33.15
3.3V_SW17: C121.1, C123.1, Q18.3, U33.9, U36.1, U36.3
3.3V_SW18: C130.1, C134.1, Q19.3, U37.15
3.3V_SW19: C135.1, C137.1, Q20.3, U37.9, U40.1, U40.3
3.3V_SW20: C144.1, C148.1, Q21.3, U41.15
3.3V_SW21: C149.1, C151.1, Q22.3, U41.9, U44.1, U44.3
3.3V_SW22: C158.1, C162.1, Q23.3, U45.15
3.3V_SW23: C163.1, C165.1, Q24.3, U45.9, U48.1, U48.3
3.3V_SW24: C172.1, C176.1, Q25.3, U49.15
3.3V_SW25: C177.1, C179.1, Q26.3, U49.9, U52.1, U52.3
3.3V_SW26: C186.1, C190.1, Q27.3, U53.15
3.3V_SW27: C191.1, C193.1, Q28.3, U53.9, U56.1, U56.3
3.3V_SW28: C200.1, C204.1, Q29.3, U57.15
3.3V_SW29: C205.1, C207.1, Q30.3, U57.9, U60.1, U60.3
3.3V_SW30: C214.1, C218.1, Q31.3, U61.15
3.3V_SW31: C219.1, C221.1, Q32.3, U61.9, U64.1, U64.3
3.3V_SW32: C228.1, C232.1, Q33.3, U65.15
3.3V_SW33: C233.1, C235.1, Q34.3, U65.9, U68.1, U68.3
3.3V_SW34: C242.1, C246.1, Q35.3, U69.15
3.3V_SW35: C247.1, C249.1, Q36.3, U69.9, U72.1, U72.3
3.3V_SW36: C256.1, C260.1, Q37.3, U73.15
3.3V_SW37: C261.1, C263.1, Q38.3, U73.9, U76.1, U76.3
3.3V_SW38: C270.1, C274.1, Q39.3, U77.15
3.3V_SW39: C275.1, C277.1, Q40.3, U77.9, U80.1, U80.3
3.3V_SW40: C284.1, C288.1, Q41.3, U81.15
3.3V_SW41: C289.1, C291.1, Q42.3, U81.9, U84.1, U84.3
3.3V_SW42: C298.1, C302.1, Q43.3, U85.15
3.3V_SW43: C303.1, C305.1, Q44.3, U85.9, U88.1, U88.3
3.3V_SW44: C312.1, C316.1, Q45.3, U89.15
3.3V_SW45: C317.1, C319.1, Q46.3, U89.9, U92.1, U92.3
3.3V_SW46: C326.1, C330.1, Q47.3, U93.15
3.3V_SW47: C331.1, C333.1, Q48.3, U93.9, U96.1, U96.3
!PAA_POW!: Q2.1, R5.1, U3.20
!PAA_POW!1: Q4.1, R12.1, U7.20
!PAA_POW!2: Q6.1, R19.1, U11.20
!PAA_POW!3: Q8.1, R26.1, U15.20
!PAA_POW!4: Q10.1, R33.1, U19.20
!PAA_POW!5: Q12.1, R40.1, U23.20
!PAA_POW!6: Q14.1, R47.1, U27.20
!PAA_POW!7: Q16.1, R54.1, U31.20
!PAA_POW!8: Q18.1, R61.1, U35.20
!PAA_POW!9: Q20.1, R68.1, U39.20
!PAA_POW!10: Q22.1, R75.1, U43.20
!PAA_POW!11: Q24.1, R82.1, U47.20
!PAA_POW!12: Q26.1, R89.1, U51.20
!PAA_POW!13: Q28.1, R96.1, U55.20
!PAA_POW!14: Q30.1, R103.1, U59.20
!PAA_POW!15: Q32.1, R110.1, U63.20
!PAA_POW!16: Q34.1, R117.1, U67.20
!PAA_POW!17: Q36.1, R124.1, U71.20
!PAA_POW!18: Q38.1, R131.1, U75.20
!PAA_POW!19: Q40.1, R138.1, U79.20
!PAA_POW!20: Q42.1, R145.1, U83.20
!PAA_POW!21: Q44.1, R152.1, U87.20
!PAA_POW!22: Q46.1, R159.1, U91.20
!PAA_POW!23: Q48.1, R166.1, U95.20
!VCSEL_POW!: Q1.1, R2.1, U3.1
!VCSEL_POW!1: Q3.1, R11.1, U7.1
!VCSEL_POW!2: Q5.1, R18.1, U11.1
!VCSEL_POW!3: Q7.1, R25.1, U15.1
!VCSEL_POW!4: Q9.1, R32.1, U19.1
!VCSEL_POW!5: Q11.1, R39.1, U23.1
!VCSEL_POW!6: Q13.1, R46.1, U27.1
!VCSEL_POW!7: Q15.1, R53.1, U31.1
!VCSEL_POW!8: Q17.1, R60.1, U35.1
!VCSEL_POW!9: Q19.1, R67.1, U39.1
!VCSEL_POW!10: Q21.1, R74.1, U43.1
!VCSEL_POW!11: Q23.1, R81.1, U47.1
!VCSEL_POW!12: Q25.1, R88.1, U51.1
!VCSEL_POW!13: Q27.1, R95.1, U55.1
!VCSEL_POW!14: Q29.1, R102.1, U59.1
!VCSEL_POW!15: Q31.1, R109.1, U63.1
!VCSEL_POW!16: Q33.1, R116.1, U67.1
!VCSEL_POW!17: Q35.1, R123.1, U71.1
!VCSEL_POW!18: Q37.1, R130.1, U75.1
!VCSEL_POW!19: Q39.1, R137.1, U79.1
!VCSEL_POW!20: Q41.1, R144.1, U83.1
!VCSEL_POW!21: Q43.1, R151.1, U87.1
!VCSEL_POW!22: Q45.1, R158.1, U91.1
!VCSEL_POW!23: Q47.1, R165.1, U95.1
GND: C2.2, C3.2, C4.2, C5.2, C6.2, C7.2, C8.2, C9.2, C10.2, C11.2, C12.2, C13.2, C14.2, D1.C, D2.1, D3.1, D4.1, J1.1, J2.1, J3.1, R7.1, U1.8, U1.13, U1.17, U2.6, U2.7, U3.3, U4.2, U$1.5
GND1: C16.2, C17.2, C18.2, C19.2, C20.2, C21.2, C22.2, C23.2, C24.2, C25.2, C26.2, C27.2, C28.2, D5.C, D6.1, D7.1, D8.1, J4.1, J5.1, J6.1, R14.1, U5.8, U5.13, U5.17, U6.6, U6.7, U7.3, U8.2, U$13.5
GND2: C30.2, C31.2, C32.2, C33.2, C34.2, C35.2, C36.2, C37.2, C38.2, C39.2, C40.2, C41.2, C42.2, D9.C, D10.1, D11.1, D12.1, J7.1, J8.1, J9.1, R21.1, U9.8, U9.13, U9.17, U10.6, U10.7, U11.3, U12.2, U$59.5
GND3: C44.2, C45.2, C46.2, C47.2, C48.2, C49.2, C50.2, C51.2, C52.2, C53.2, C54.2, C55.2, C56.2, D13.C, D14.1, D15.1, D16.1, J10.1, J11.1, J12.1, R28.1, U13.8, U13.13, U13.17, U14.6, U14.7, U15.3, U16.2, U$88.5
GND4: C58.2, C59.2, C60.2, C61.2, C62.2, C63.2, C64.2, C65.2, C66.2, C67.2, C68.2, C69.2, C70.2, D17.C, D18.1, D19.1, D20.1, J13.1, J14.1, J15.1, R35.1, U17.8, U17.13, U17.17, U18.6, U18.7, U19.3, U20.2, U$117.5
GND5: C72.2, C73.2, C74.2, C75.2, C76.2, C77.2, C78.2, C79.2, C80.2, C81.2, C82.2, C83.2, C84.2, D21.C, D22.1, D23.1, D24.1, J16.1, J17.1, J18.1, R42.1, U21.8, U21.13, U21.17, U22.6, U22.7, U23.3, U24.2, U$146.5
GND6: C86.2, C87.2, C88.2, C89.2, C90.2, C91.2, C92.2, C93.2, C94.2, C95.2, C96.2, C97.2, C98.2, D25.C, D26.1, D27.1, D28.1, J19.1, J20.1, J21.1, R49.1, U25.8, U25.13, U25.17, U26.6, U26.7, U27.3, U28.2, U$175.5
GND7: C100.2, C101.2, C102.2, C103.2, C104.2, C105.2, C106.2, C107.2, C108.2, C109.2, C110.2, C111.2, C112.2, D29.C, D30.1, D31.1, D32.1, J22.1, J23.1, J24.1, R56.1, U29.8, U29.13, U29.17, U30.6, U30.7, U31.3, U32.2, U$204.5
GND8: C114.2, C115.2, C116.2, C117.2, C118.2, C119.2, C120.2, C121.2, C122.2, C123.2, C124.2, C125.2, C126.2, D33.C, D34.1, D35.1, D36.1, J25.1, J26.1, J27.1, R63.1, U33.8, U33.13, U33.17, U34.6, U34.7, U35.3, U36.2, U$233.5
GND9: C128.2, C129.2, C130.2, C131.2, C132.2, C133.2, C134.2, C135.2, C136.2, C137.2, C138.2, C139.2, C140.2, D37.C, D38.1, D39.1, D40.1, J28.1, J29.1, J30.1, R70.1, U37.8, U37.13, U37.17, U38.6, U38.7, U39.3, U40.2, U$262.5
GND10: C142.2, C143.2, C144.2, C145.2, C146.2, C147.2, C148.2, C149.2, C150.2, C151.2, C152.2, C153.2, C154.2, D41.C, D42.1, D43.1, D44.1, J31.1, J32.1, J33.1, R77.1, U41.8, U41.13, U41.17, U42.6, U42.7, U43.3, U44.2, U$291.5
GND11: C156.2, C157.2, C158.2, C159.2, C160.2, C161.2, C162.2, C163.2, C164.2, C165.2, C166.2, C167.2, C168.2, D45.C, D46.1, D47.1, D48.1, J34.1, J35.1, J36.1, R84.1, U45.8, U45.13, U45.17, U46.6, U46.7, U47.3, U48.2, U$320.5
GND12: C170.2, C171.2, C172.2, C173.2, C174.2, C175.2, C176.2, C177.2, C178.2, C179.2, C180.2, C181.2, C182.2, D49.C, D50.1, D51.1, D52.1, J37.1, J38.1, J39.1, R91.1, U49.8, U49.13, U49.17, U50.6, U50.7, U51.3, U52.2, U$349.5
GND13: C184.2, C185.2, C186.2, C187.2, C188.2, C189.2, C190.2, C191.2, C192.2, C193.2, C194.2, C195.2, C196.2, D53.C, D54.1, D55.1, D56.1, J40.1, J41.1, J42.1, R98.1, U53.8, U53.13, U53.17, U54.6, U54.7, U55.3, U56.2, U$378.5
GND14: C198.2, C199.2, C200.2, C201.2, C202.2, C203.2, C204.2, C205.2, C206.2, C207.2, C208.2, C209.2, C210.2, D57.C, D58.1, D59.1, D60.1, J43.1, J44.1, J45.1, R105.1, U57.8, U57.13, U57.17, U58.6, U58.7, U59.3, U60.2, U$407.5
GND15: C212.2, C213.2, C214.2, C215.2, C216.2, C217.2, C218.2, C219.2, C220.2, C221.2, C222.2, C223.2, C224.2, D61.C, D62.1, D63.1, D64.1, J46.1, J47.1, J48.1, R112.1, U61.8, U61.13, U61.17, U62.6, U62.7, U63.3, U64.2, U$436.5
GND16: C226.2, C227.2, C228.2, C229.2, C230.2, C231.2, C232.2, C233.2, C234.2, C235.2, C236.2, C237.2, C238.2, D65.C, D66.1, D67.1, D68.1, J49.1, J50.1, J51.1, R119.1, U65.8, U65.13, U65.17, U66.6, U66.7, U67.3, U68.2, U$465.5
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

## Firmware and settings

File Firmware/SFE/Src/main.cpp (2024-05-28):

/*
    SPDX-License-Identifier: MIT
    
    Copyright (c) 2024 SparkFun Electronics
*/

#include "main.h"
#include "otosLsm6dso.h"
#include "otosPaa5160.h"
#include "registers.h"
#include "otosConstants.h"
#include "time.h"
#include "pose2d.h"
#include "adc.h"
#include "otosLut.h"
#include "otosKalmanFilter.h"
#include "arm_math.h"

// Helper function to calibrate the IMU. Must be stationary during calibration!
void calibrateImu(uint8_t numSamples);

// Helper function to get the latest sensor data and update the pose
void sensorUpdate();

// Helper function to update the main register copy from the self shadow
void copyRegsFromSelfShadow();

// Helper function to update the main register copy from the host shadow
void copyRegsFromHostShadow();

// Instances of the sensors
PAA5160 paa;
LSM6DSO lsm;

// Offset between OTOS and host, and its inverse
pose2d posHost;
pose2d posOffset;
pose2d posOffsetInv;

// IMU offset values
float accOffsetX = 0;
float accOffsetY = 0;
float gyrOffsetX = 0;
float gyrOffsetY = 0;
float gyrOffsetZ = 0;

// Approximate roll and pitch angles, used to determine whether accelerometer
// data can be trusted due to too much tilt of the sensor
float roll = 0;
float pitch = 0;

// Previous loop time in order to calculate delta time
uint32_t lastLoopTime = 0;

// Variable to track errors by function calls
sfeTkError_t err = 0;

// Scaler correction values
float userScalarLinear = 1.0f;
float userScalarAngular = 1.0f;

// Kalmam filters for x and y axes
otosKalmanFilter xKf(1e-8, 1e-6, 1e-4);
otosKalmanFilter yKf(1e-8, 1e-6, 1e-4);
otosKalmanFilter hKf(1e-10, 1e-7, 1e-1);

void setup(void)
{
    // Enable SysTick interrupt, which fires every millisecond and is used to
    // track the system time (see SysTick_Handler() in stm32c0xx_it.c)
    LL_SYSTICK_EnableIT();

    // Enable SPI. For some reason this isn't done by the code generator?
    LL_SPI_Enable(SPI1);

    // Reset I2C registers to ensure they are in a known state
    resetRegisters();

    // Enable the address match, NACK, and STOP interrupts for I2C. The TX and
    // RX interrupts are enabled dynamically when these 3 interrupts are
    // triggered (see I2C1_IRQHandler() in stm32c0xx_it.c)
    LL_I2C_EnableIT_ADDR(I2C1);
    LL_I2C_EnableIT_NACK(I2C1);
    LL_I2C_EnableIT_STOP(I2C1);

    // Calibrate and enable the ADC, which is used to check that the PAA5160 is
    // actually receiving power
    calibrateAndEnableADC();

    // Begin the PAA5160. This should be done before the LSM6DS0, because the
    // ESD diodes on the PAA5160's SPI pins will back-power it, which we don't
    // want. The begin() will power up the PAA5160, after which we can begin
    // the LSM6DS0 safely
    err = paa.begin();
    if(err != kSTkErrOk)
        registerStatus->errorPaa = 1;

    // Now we can begin the LSM6DS0
    err = lsm.begin();
    if(err != kSTkErrOk)
        registerStatus->errorLsm = 1;

    // Ensure the orientation of the PAA5160 is correct, it defaults to one axis
    // being inverted
    sfe_paa5160_orientation_t orientation;
    orientation.invertX = 0;
    orientation.invertY = 0;
    orientation.swapXY = 0;
    err = paa.setOrientation(orientation);
    if(err != kSTkErrOk)
        registerStatus->errorPaa = 1;

    // Set PAA5160 resolution to max (20k dpi)
    err = paa.setResolution(kPaa5160MaxResolution, kPaa5160MaxResolution);
    if(err != kSTkErrOk)
        registerStatus->errorPaa = 1;

    // Set range and data rate for accelerometer and gyro as high as we can, to
    // avoid clipping, and to see short data spikes. 16g and 2000dps is the max
    // of the LSM6DS0, and 416Hz is the max data rate that this application on
    // this MCU can reasonably handle
    err = lsm.setAccelRange(kLsm6dsoAccelRange16g);
    if(err != kSTkErrOk)
        registerStatus->errorLsm = 1;
    err = lsm.setGyroRange(kLsm6dsoGyroRange2000Dps);
    if(err != kSTkErrOk)
        registerStatus->errorLsm = 1;
    err = lsm.setAccelDataRate(kLsm6dsoOdr416Hz);
    if(err != kSTkErrOk)
        registerStatus->errorLsm = 1;
    err = lsm.setGyroDataRate(kLsm6dsoOdr416Hz);
    if(err != kSTkErrOk)
        registerStatus->errorLsm = 1;

    // Enable gyro data ready interrupt, which we will use to synchronize the
    // data from the PAA5160 and LSM6DS0
    err = lsm.setInterrupts(kLsm6dsoInt1Pin, kLsm6dsoInt1SrcDrdyG);
    if(err != kSTkErrOk)
        registerStatus->errorLsm = 1;

    // Testing has shown that the initial data from the LSM6DS0 seems to
    // "oscillate" just after powering on for some reason, despite the sensor
    // being motionless. This typically settles within 100ms, so we'll wait for
    // that to happen before we start calibrating the gyro
    delay(100);

    // Perform a quick calibration of the gyro. This should really only be done
    // when motionless, and we don't know if we are or not. But we'll do it
    // anyway since there's a decent chance that we are motionless if we just
    // reset. Hopefully the user will trigger a proper calibration later!
    calibrateImu(64);
}

void loop()
{
    // Update registers from self shadow registers if needed
    copyRegsFromSelfShadow();

    // Update registers from host shadow registers if needed
    copyRegsFromHostShadow();

    // Update sensor data if needed
    sensorUpdate();
}

void calibrateImu(uint8_t numSamples)
{
    // Variables to store the running sum of raw IMU data, which we'll use to
    // compute the average
    int32_t accSumX = 0;
    int32_t accSumY = 0;
    int32_t gyrSumX = 0;
    int32_t gyrSumY = 0;
    int32_t gyrSumZ = 0;

    // Loop until we get the requested number of samples
    uint8_t counter = numSamples;
    uint32_t timeoutStart = millis();
    while (counter > 0)
    {
        // Check if we've waited for too long (should only be 2.4ms at 416Hz)
        if(millis() - timeoutStart > 10)
        {
            // Timeout occurred, set flag and break out of loop
            registerStatus->errorLsm = 1;
            break;
        }

        // Wait for next data to become available from IMU
        if (!lsmDrdy)
            continue;

        // Reset the data ready flag for the next measurement
        lsmDrdy = false;

        // Reset timeout
        timeoutStart = millis();

        // Grab the IMU data. We use the raw data and convert it later for
        // better efficiency and numerical accuracy
        uint8_t lsmData[12];
        err = lsm.readRawAccelGyroAll(lsmData, 12);
        if(err != kSTkErrOk)
            registerStatus->errorLsm = 1;
        
        // Combine raw bytes into 16-bit signed integers
        int16_t gyrXRaw = (lsmData[1] << 8) | lsmData[0];
        int16_t gyrYRaw = (lsmData[3] << 8) | lsmData[2];
        int16_t gyrZRaw = (lsmData[5] << 8) | lsmData[4];
        int16_t accXRaw = (lsmData[7] << 8) | lsmData[6];
        int16_t accYRaw = (lsmData[9] << 8) | lsmData[8];

        // Add the IMU data to the running sums
        accSumX += accXRaw;
        accSumY += accYRaw;
        gyrSumX += gyrXRaw;
        gyrSumY += gyrYRaw;
        gyrSumZ += gyrZRaw;

        // Decrement the sample counter
        counter--;

        // Update register to inform host of progress
        registerBufferMain[kOtosRegImuCalib] = counter;
    }

    // Reset the last loop time to avoid a large delta time in the main loop
    lastLoopTime = micros();

    // Compute the averages in m/s^2 and radians/second, and store them as the
    // offsets
    accOffsetX = (accSumX * lsm.rawToMps2()) / numSamples;
    accOffsetY = (accSumY * lsm.rawToMps2()) / numSamples;
    gyrOffsetX = (gyrSumX * lsm.rawToRps()) / numSamples;
    gyrOffsetY = (gyrSumY * lsm.rawToRps()) / numSamples;
    gyrOffsetZ = (gyrSumZ * lsm.rawToRps()) / numSamples;
}

void sensorUpdate()
{
    // Check to see if new data is available from the IMU
    if (!lsmDrdy)
    {
        // No new data, nothing to do
        return;
    }

    ////////////////////////////////////////////////////////////////////////////
    // Sensor measurement (time critical section!)
    ////////////////////////////////////////////////////////////////////////////

    // We have new data! Set the output pin to indicate that we're now measuring
    LL_GPIO_SetOutputPin(GPIOA, LL_GPIO_PIN_9);

    // Immediately update the loop timer to get accurate time
    uint32_t loopTime = micros();

    // Reset the data ready flag before we read from the LSM6DSO, because
    // that clears this interrupt, and we need to be ready for the next one
    lsmDrdy = false;

    // Read data from sensors as soon as possible
    uint8_t paaData[12];
    err = paa.readBurstData(paaData, 12);
    if(err != kSTkErrOk)
        registerStatus->errorPaa = 1;
    uint8_t lsmData[12];
    err = lsm.readRawAccelGyroAll(lsmData, 12);
    if(err != kSTkErrOk)
        registerStatus->errorLsm = 1;

    ////////////////////////////////////////////////////////////////////////////
    // Measurement conversion
    ////////////////////////////////////////////////////////////////////////////
    
    // All the time-critical things are done, so we can do some math now. First
    // let's compute the delta time, and save the last loop time
    float dt = (loopTime - lastLoopTime) * 1e-6f;
    float dtInv = 1.0f / dt;
    lastLoopTime = loopTime;
    
    // Combine raw bytes into 16-bit signed integers
    int16_t deltaXRaw = (paaData[3] << 8) | paaData[2];
    int16_t deltaYRaw = (paaData[5] << 8) | paaData[4];
    int16_t deltaRRaw = (lsmData[1] << 8) | lsmData[0];
    int16_t deltaPRaw = (lsmData[3] << 8) | lsmData[2];
    int16_t deltaHRaw = (lsmData[5] << 8) | lsmData[4];
    int16_t accelXRaw = (lsmData[7] << 8) | lsmData[6];
    int16_t accelYRaw = (lsmData[9] << 8) | lsmData[8];

    // Convert the PAA5160 data to meters
    float deltaX = deltaXRaw * paa.rawToMetersX();
    float deltaY = deltaYRaw * paa.rawToMetersY();

    // Convert the gyro data to radians/second, apply the gyro offset
    float vR = (deltaRRaw * lsm.rawToRps() - gyrOffsetX);
    float vP = (deltaPRaw * lsm.rawToRps() - gyrOffsetY);
    float vH = (deltaHRaw * lsm.rawToRps() - gyrOffsetZ);

    // Convert the accelerometer data to m/s^2, and apply the acceleration
    // offset. The IMU is mounted 90 degrees from the PAA5160, so we need to
    // swap the X and Y axes, and negate Y    
    float accelXMps2 = (accelYRaw * lsm.rawToMps2()) - accOffsetY;
    float accelYMps2 = -((accelXRaw * lsm.rawToMps2()) - accOffsetX);

    ////////////////////////////////////////////////////////////////////////////
    // Lookup table calibration
    ////////////////////////////////////////////////////////////////////////////

    // The resolution of the PAA5160 varies with the surface velocity. A lookup
    // table has been implemented that provides a scaling factor to compensate
    // based on the measured velocities, so compute the measured velocities
    float vx = deltaX * dtInv;
    float vy = deltaY * dtInv;

    // Using the measured velocities, determine the scaling factors for each
    // axis using the lookup table. The lookup table requires inches per second
    float xScalar = 1.0f;
    float yScalar = 1.0f;
    if(registerSignalProcess->enLut)
        bilinearInterp(vx * 39.37f, vy * 39.37f, xScalar, yScalar);

    // Scale the velocities by the lookup table scalars, and apply the user
    // defined scalars
    vx *= xScalar * userScalarLinear;
    vy *= yScalar * userScalarLinear;

    ////////////////////////////////////////////////////////////////////////////
    // Tilt detection
    ////////////////////////////////////////////////////////////////////////////

    // Compute roll and pitch angles approximately. Simple integration like this
    // is not technically the right way to do this, but it's not being used for
    // true orientation detection, just to determine if the sensor has been
    // tiled significantly
    roll += vR * dt;
    pitch += vP * dt;

    // As described below, the optical tracking sensor can't always be trusted,
    // such as when the surface properties change suddenly. The solution there
    // is to ignore the optical tracking data if that's detected, and only use
    // the accelerometer data. This works fine under normal conditions, but if 
    // the user tilts the sensor more than ~20 degrees, the accelerometer data
    // causes a false positive detection of tracking issues, which can cause the
    // estimated velocity and position to explode. So if the tilt angles are
    // beyond a threshold (arbitrarily set to 0.2 radians, or 11.5 degrees),
    // we'll set the status flag to indicate that the tilt angle is too high,
    // and the accelerometer data will be ignored later
    if(abs(roll) > 0.2f || abs(pitch) > 0.2f)
        registerStatus->warnTiltAngle = 1;
    else
        registerStatus->warnTiltAngle = 0;

    ////////////////////////////////////////////////////////////////////////////
    // Kalmam filter update (angular)
    ////////////////////////////////////////////////////////////////////////////

    // Apply user-defined scalar for heading
    vH *= userScalarAngular;

    // First run the prediction step
    hKf.predict(dt);

    // Now run the update step with the latest measurement
    hKf.updateVel(vH, 1e-3);

    // Wrap heading to +/- pi
    if (hKf.xData[0] >= kPi)
        hKf.xData[0] -= k2Pi;
    if (hKf.xData[0] < -kPi)
        hKf.xData[0] += k2Pi;

    ////////////////////////////////////////////////////////////////////////////
    // Convert measurements to world frame
    ////////////////////////////////////////////////////////////////////////////

    // Pre-compute sin and cos so we don't have to do it multiple times
    float cosHeading = arm_cos_f32(hKf.xData[0]);
    float sinHeading = arm_sin_f32(hKf.xData[0]);

    // Rotate the measured velocity and acceleration by the heading
    if(registerSignalProcess->enRot)
    {
        float vxRot = vx * cosHeading - vy * sinHeading;
        float vyRot = vx * sinHeading + vy * cosHeading;
        float accelXMps2Rot = accelXMps2 * cosHeading - accelYMps2 * sinHeading;
        float accelYMps2Rot = accelXMps2 * sinHeading + accelYMps2 * cosHeading;

        vx = vxRot;
        vy = vyRot;
        accelXMps2 = accelXMps2Rot;
        accelYMps2 = accelYMps2Rot;
    }

    ////////////////////////////////////////////////////////////////////////////
    // Kalman filter update (linear)
    ////////////////////////////////////////////////////////////////////////////

    // First run the prediction step
    xKf.predict(dt);
    yKf.predict(dt);

    // Now run the update steps with the latest measurements. If the tilt angle
    // is sufficiently low, we'll use the data from both the accelerometer and
    // optical sensor, otherwise we'll only use the optical sensor data
    if(registerSignalProcess->enAcc && registerStatus->warnTiltAngle == 0)
    {
        // Acceleration update
        xKf.updateAcc(accelXMps2, 9e-4 * registerSignalProcess->enVar);
        yKf.updateAcc(accelYMps2, 9e-4 * registerSignalProcess->enVar);

        // Sometimes the velocity measured by the PAA5160 drops very low, which
        // is usually caused by tracking issues (eg. debris or a sudden change
        // in surface properties). We can detect this if the measured velocity
        // is significantly lower than the estimated velocity, in which case we
        // can ignore the measurement
        if(!((abs(vx) + abs(vy)) < .25 && (abs(xKf.xData[1]) + abs(yKf.xData[1])) > .5))
        {
            // Velocity update
            xKf.updateVel(vx, 6e-3f * registerSignalProcess->enVar);
            yKf.updateVel(vy, 6e-3f * registerSignalProcess->enVar);

            // Reset the warning flag
            registerStatus->warnOpticalTracking = 0;
        }
        else
        {
            // Set the warning flag
            registerStatus->warnOpticalTracking = 1;
        }
    }
    else
    {
        // Not using the accelerometer data, just do the velocity update
        xKf.updateVel(vx, 6e-3 * registerSignalProcess->enVar);
        yKf.updateVel(vy, 6e-3 * registerSignalProcess->enVar);
    }

    ////////////////////////////////////////////////////////////////////////////
    // Compute host position, velocity, and acceleration
    ////////////////////////////////////////////////////////////////////////////

    // Here we compute the host position, velocity, and acceleration in the
    // world frame. The equations below are very similar to what's used in
    // transformPose(), but we're doing them explicitly here to avoid computing
    // sine and cosine more than needed. Additionally, the velocity and
    // acceleration have to be computed slightly differently

    // Host position
    posHost.x = xKf.xData[0] + (posOffsetInv.x * cosHeading - posOffsetInv.y * sinHeading);
    posHost.y = yKf.xData[0] + (posOffsetInv.x * sinHeading + posOffsetInv.y * cosHeading);
    posHost.h = hKf.xData[0] + posOffsetInv.h;

    // Host velocity
    pose2d velHost;
    velHost.x = xKf.xData[1] + (-posOffsetInv.x * sinHeading - posOffsetInv.y * cosHeading) * hKf.xData[1];
    velHost.y = yKf.xData[1] + (posOffsetInv.x * cosHeading - posOffsetInv.y * sinHeading) * hKf.xData[1];
    velHost.h = hKf.xData[1];

    // Host acceleration
    pose2d accHost;
    float centripetalAcceleration = sqrtf(posOffsetInv.x * posOffsetInv.x + posOffsetInv.y * posOffsetInv.y) * hKf.xData[1] * hKf.xData[1];
    accHost.x = xKf.xData[2] + (-posOffsetInv.x * sinHeading - posOffsetInv.y * cosHeading) * hKf.xData[2]
                - (centripetalAcceleration * cosHeading - centripetalAcceleration * sinHeading);
    accHost.y = yKf.xData[2] + (posOffsetInv.x * cosHeading - posOffsetInv.y * sinHeading) * hKf.xData[2]
                - (centripetalAcceleration * sinHeading + centripetalAcceleration * cosHeading);
    accHost.h = hKf.xData[2];

    ////////////////////////////////////////////////////////////////////////////
    // Update shadow registers
    ////////////////////////////////////////////////////////////////////////////

    // Convert host position, velocity, and acceleration to integers in
    // preparation for storing in the shadow registers
    int16_t pxInt = posHost.x * kMeterToInt16;
    int16_t pyInt = posHost.y * kMeterToInt16;
    int16_t phInt = posHost.h * kRadToInt16;
    int16_t vxInt = velHost.x * kMpsToInt16;
    int16_t vyInt = velHost.y * kMpsToInt16;
    int16_t vhInt = velHost.h * kRpsToInt16;
    int16_t axInt = accHost.x * kMpssToInt16;
    int16_t ayInt = accHost.y * kMpssToInt16;
    int16_t ahInt = accHost.h * kRpssToInt16;

    // Compute standard deviation of the Kalman filter covariance matrices
    int16_t pxStdInt = sqrtf(xKf.pData[kOtosKfIdx00]) * kMeterToInt16;
    int16_t pyStdInt = sqrtf(yKf.pData[kOtosKfIdx00]) * kMeterToInt16;
    int16_t phStdInt = sqrtf(hKf.pData[kOtosKfIdx00]) * kRadToInt16;
    int16_t vxStdInt = sqrtf(xKf.pData[kOtosKfIdx11]) * kMpsToInt16;
    int16_t vyStdInt = sqrtf(yKf.pData[kOtosKfIdx11]) * kMpsToInt16;
    int16_t vhStdInt = sqrtf(hKf.pData[kOtosKfIdx11]) * kRpsToInt16;
    int16_t axStdInt = sqrtf(xKf.pData[kOtosKfIdx22]) * kMpssToInt16;
    int16_t ayStdInt = sqrtf(yKf.pData[kOtosKfIdx22]) * kMpssToInt16;
    int16_t ahStdInt = sqrtf(hKf.pData[kOtosKfIdx22]) * kRpssToInt16;

    // Now store the raw register data into the shadow buffer
    registerShadowSelf[kOtosRegPosXL] = pxInt & 0xFF;
    registerShadowSelf[kOtosRegPosXH] = (pxInt >> 8) & 0xFF;
    registerShadowSelf[kOtosRegPosYL] = pyInt & 0xFF;
    registerShadowSelf[kOtosRegPosYH] = (pyInt >> 8) & 0xFF;
    registerShadowSelf[kOtosRegPosHL] = phInt & 0xFF;
    registerShadowSelf[kOtosRegPosHH] = (phInt >> 8) & 0xFF;
    registerShadowSelf[kOtosRegVelXL] = vxInt & 0xFF;
    registerShadowSelf[kOtosRegVelXH] = (vxInt >> 8) & 0xFF;
    registerShadowSelf[kOtosRegVelYL] = vyInt & 0xFF;
    registerShadowSelf[kOtosRegVelYH] = (vyInt >> 8) & 0xFF;
    registerShadowSelf[kOtosRegVelHL] = vhInt & 0xFF;
    registerShadowSelf[kOtosRegVelHH] = (vhInt >> 8) & 0xFF;
    registerShadowSelf[kOtosRegAccXL] = axInt & 0xFF;
    registerShadowSelf[kOtosRegAccXH] = (axInt >> 8) & 0xFF;
    registerShadowSelf[kOtosRegAccYL] = ayInt & 0xFF;
    registerShadowSelf[kOtosRegAccYH] = (ayInt >> 8) & 0xFF;
    registerShadowSelf[kOtosRegAccHL] = ahInt & 0xFF;
    registerShadowSelf[kOtosRegAccHH] = (ahInt >> 8) & 0xFF;
    registerShadowSelf[kOtosRegPosStdXL] = pxStdInt & 0xFF;
    registerShadowSelf[kOtosRegPosStdXH] = (pxStdInt >> 8) & 0xFF;
    registerShadowSelf[kOtosRegPosStdYL] = pyStdInt & 0xFF;
    registerShadowSelf[kOtosRegPosStdYH] = (pyStdInt >> 8) & 0xFF;
    registerShadowSelf[kOtosRegPosStdHL] = phStdInt & 0xFF;
    registerShadowSelf[kOtosRegPosStdHH] = (phStdInt >> 8) & 0xFF;
    registerShadowSelf[kOtosRegVelStdXL] = vxStdInt & 0xFF;
    registerShadowSelf[kOtosRegVelStdXH] = (vxStdInt >> 8) & 0xFF;
    registerShadowSelf[kOtosRegVelStdYL] = vyStdInt & 0xFF;
    registerShadowSelf[kOtosRegVelStdYH] = (vyStdInt >> 8) & 0xFF;
    registerShadowSelf[kOtosRegVelStdHL] = vhStdInt & 0xFF;
    registerShadowSelf[kOtosRegVelStdHH] = (vhStdInt >> 8) & 0xFF;
    registerShadowSelf[kOtosRegAccStdXL] = axStdInt & 0xFF;
    registerShadowSelf[kOtosRegAccStdXH] = (axStdInt >> 8) & 0xFF;
    registerShadowSelf[kOtosRegAccStdYL] = ayStdInt & 0xFF;
    registerShadowSelf[kOtosRegAccStdYH] = (ayStdInt >> 8) & 0xFF;
    registerShadowSelf[kOtosRegAccStdHL] = ahStdInt & 0xFF;
    registerShadowSelf[kOtosRegAccStdHH] = (ahStdInt >> 8) & 0xFF;

    // Also store the raw LSM6DSO and PAA5160 data into the shadow buffer
    memcpy(registerShadowSelf + kOtosRegLsmGyrXL, lsmData, 12);
    memcpy(registerShadowSelf + kOtosRegPaaBurst00, paaData, 12);

    // Update flag to indicate the shadow registers have been written to
    shadowSelfWritten = true;
}
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

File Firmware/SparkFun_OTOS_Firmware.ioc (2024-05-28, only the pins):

Mcu.UserName=STM32C011F6Ux
PA0.GPIO_Label=MEAS_1V8
PA0.Signal=ADC1_IN0
PA1.Signal=SPI1_SCK
PA13.Signal=DEBUG_SWDIO
PA14-BOOT0.Signal=DEBUG_SWCLK
PA2.Signal=SPI1_MOSI
PA3.GPIO_Label=LSM_INT
PA3.Signal=GPXTI3
PA4.GPIO_Label=PAA_RST
PA4.Signal=GPIO_Output
PA5.GPIO_Label=PAA_CS
PA5.Signal=GPIO_Output
PA6.Signal=SPI1_MISO
PA7.GPIO_Label=PAA_MOTION
PA7.Signal=GPIO_Input
PA8.GPIO_Label=LSM_CS
PA8.Signal=GPIO_Output
PB6.Signal=I2C1_SCL
PB7.Signal=I2C1_SDA

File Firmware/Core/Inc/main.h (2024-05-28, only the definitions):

#define VCSEL_POW_Pin LL_GPIO_PIN_15
#define VCSEL_POW_GPIO_Port GPIOC
#define MEAS_1V8_Pin LL_GPIO_PIN_0
#define MEAS_1V8_GPIO_Port GPIOA
#define LSM_INT_Pin LL_GPIO_PIN_3
#define LSM_INT_GPIO_Port GPIOA
#define LSM_INT_EXTI_IRQn EXTI2_3_IRQn
#define PAA_RST_Pin LL_GPIO_PIN_4
#define PAA_RST_GPIO_Port GPIOA
#define PAA_CS_Pin LL_GPIO_PIN_5
#define PAA_CS_GPIO_Port GPIOA
#define PAA_MOTION_Pin LL_GPIO_PIN_7
#define PAA_MOTION_GPIO_Port GPIOA
#define LSM_CS_Pin LL_GPIO_PIN_8
#define LSM_CS_GPIO_Port GPIOA
#define PAA_POW_Pin LL_GPIO_PIN_14
#define PAA_POW_GPIO_Port GPIOC
#define NVIC_PRIORITYGROUP_0         ((uint32_t)0x00000007) /*!< 0 bit  for pre-emption priority,
#define NVIC_PRIORITYGROUP_1         ((uint32_t)0x00000006) /*!< 1 bit  for pre-emption priority,
#define NVIC_PRIORITYGROUP_2         ((uint32_t)0x00000005) /*!< 2 bits for pre-emption priority,
#define NVIC_PRIORITYGROUP_3         ((uint32_t)0x00000004) /*!< 3 bits for pre-emption priority,
#define NVIC_PRIORITYGROUP_4         ((uint32_t)0x00000003) /*!< 4 bits for pre-emption priority,

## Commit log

2024-01-02 Add initial hardware design
    [SparkFun_Optical_Tracking_Odometry_Sensor.brd, SparkFun_Optical_Tracking_Odometry_Sensor.sch]
2024-01-02 Add STM32 docs
2024-01-04 PAA5160 footprint tweaks
    Adjust pads to match datasheet recommendations
    Reduce silk outline to be only in corners
    Add tDocu lines for sensor location and pin 1 indication
    Also remove pullup resistor on the STM reset net, the STM has an internal pullup
    [SparkFun_Optical_Tracking_Odometry_Sensor.brd, SparkFun_Optical_Tracking_Odometry_Sensor.sch]
2024-01-05 v02 update
    Add MOSFETs controlled by GPIO pins in order to supply power to PAA5160 with correct timings
    Add correct decoupling capacitors
    Rearrange some GPIO pins
    Reduce silk around STM32C0
    Reroute entire board 🙃
    [SparkFun_Optical_Tracking_Odometry_Sensor.brd, SparkFun_Optical_Tracking_Odometry_Sensor.sch]
2024-01-08 Improve GND pour
    Add GND vias
    Nudge via locations to dodge silkscreen better
    [SparkFun_Optical_Tracking_Odometry_Sensor.brd]
2024-01-09 Design review updates
    Add regulator name to section in schematic
    Add voltage ranges for each component, and required voltage range for entire board
    Add GND via next to STM32 GND pad
    Center traces between Q1 and R2
    Nudge via and 3.3V trace left of R6 to get better GND stitching
    Fix acid trap with via under U4
    Fix orientation of silk on bottom
    Add silk line between D4 and C5
    [SparkFun_Optical_Tracking_Odometry_Sensor.brd, SparkFun_Optical_Tracking_Odometry_Sensor.sch]
2024-01-09 Improve GND pour
    Nudge up 3.3V trace left of C5 to get GND to pour below it
    [SparkFun_Optical_Tracking_Odometry_Sensor.brd]
2024-01-09 Add pulldown resistor to BOOT0 pin
    [SparkFun_Optical_Tracking_Odometry_Sensor.brd, SparkFun_Optical_Tracking_Odometry_Sensor.sch]
2024-01-09 Add axes to PAA5160 tDocu
    [SparkFun_Optical_Tracking_Odometry_Sensor.brd, SparkFun_Optical_Tracking_Odometry_Sensor.sch]
2024-02-26 v10 updates
    Bump version number to v10
    Add external pullup to RST net
    Nudge components and traces away from mounting holes
    Replace 3.3V regulator with 1.8V version
    Add PROD_ID values to STM32C0 and PAA5160
    Rename PAA5160 to full name of PAA5160E1-Q
    Rename STM32 to STM32C011F6U6 (32kB flash version)
    Swap R6 for 1k to minimize effect of leakage current into ADC
    [SparkFun_Optical_Tracking_Odometry_Sensor.brd, SparkFun_Optical_Tracking_Odometry_Sensor.sch]
2024-02-26 Update section titles in schematic
    [SparkFun_Optical_Tracking_Odometry_Sensor.sch]
2024-02-26 Replace external reset pullup with decoupling cap
    Turns out the datasheet calls for it, whoops!
    [SparkFun_Optical_Tracking_Odometry_Sensor.brd, SparkFun_Optical_Tracking_Odometry_Sensor.sch]
2024-02-28 Design review updates
    Fix one via being the wrong size
    Add silk line between R6 and C3
    [SparkFun_Optical_Tracking_Odometry_Sensor.brd]
2024-02-28 Add v10 production files
    [SparkFun_Optical_Tracking_Odometry_Sensor-Panel.GBL, SparkFun_Optical_Tracking_Odometry_Sensor-Panel.GBP, SparkFun_Optical_Tracking_Odometry_Sensor-Panel.GBS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]
2024-03-04 Fix STM32C0 PROD_ID
    [SparkFun_Optical_Tracking_Odometry_Sensor-Panel.brd, SparkFun_Optical_Tracking_Odometry_Sensor.brd, SparkFun_Optical_Tracking_Odometry_Sensor.sch]
2024-03-29 Stubs for arduino examples
2024-04-22 v11 updates
    Bump version number to v11
    Fix PAA5160 footprint (pad pitch was 0.6mm instead of 0.65mm, and needed to be pushed out 0.1mm)
    Fix power LED orientation (doh!)
    Fix measures
    [SparkFun_Optical_Tracking_Odometry_Sensor.brd, SparkFun_Optical_Tracking_Odometry_Sensor.sch]
2024-04-22 Add default I2C address to schematic
    [SparkFun_Optical_Tracking_Odometry_Sensor.sch]
2024-04-25 Add v11 production files
    [SparkFun_Optical_Tracking_Odometry_Sensor-Panel.brd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]
2024-05-07 Fix board outline file
2024-05-24 Updating to examples, hardware assembly
2024-05-31 Add Kalman filter design documents
2024-05-31 Add lookup table calibration documentation
    [stepper_disc_mount.stl, stepper_motor_bracket.stl, stepper_otos_mount.stl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]

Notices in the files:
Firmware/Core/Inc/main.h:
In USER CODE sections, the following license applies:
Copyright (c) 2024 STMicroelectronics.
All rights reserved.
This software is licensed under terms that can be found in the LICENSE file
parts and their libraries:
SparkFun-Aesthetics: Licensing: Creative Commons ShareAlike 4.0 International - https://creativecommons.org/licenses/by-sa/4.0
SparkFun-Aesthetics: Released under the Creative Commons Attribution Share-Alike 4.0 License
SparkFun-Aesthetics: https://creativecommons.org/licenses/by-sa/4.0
